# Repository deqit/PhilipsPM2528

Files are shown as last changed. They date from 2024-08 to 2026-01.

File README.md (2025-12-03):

# Reviving a Philips PM2528 Digital Multimeter
Picked up this vintage multimeter a while back. Half-functional, no manuals, and full of mystery. Perfect!

It’s built around an Intel 8035 microcontroller and packed with analog boards. There wasn’t a complete service manual anywhere, so I decided to dive in myself. This project's become a learning experience in hardware reverse engineering, firmware disassembly, and documentation.

Also see https://hackaday.io/project/203720-reviving-a-philips-pm2528-digital-multimeter

# The project
The goal of this project is fixing the multimeter. Well... maybe not really. In real life, the road towards that goal is much more interesting. And I'm documenting everything I found along the way.

In this repository you'll find:
- Original Philips-documentation (at least, what I could find, unfortunately in lo-res)
- Schematics (KiCad)
- PCB Layouts (KiCad)
- Schematic/PCB of a risercard, for testing the expansionboards
- Disassembled firmware, including annotations (Ghidra)
- A lot of documentation regarding relais-mapping, IO-expander-ports, etc.
- Detailed scope- and logic analyzer screenprints and capture-logs
- Deepdive: Explaination of how-everything-works
- etc.

Everything you find here is work-in-progress. It might be incomplete, and some parts may not be 100% accurate yet. If you spot something interesting or catch an error, feel free to drop me a message.

# The components
### Overview
- See [PM2528 Overview](/Deepdive/Overview/README.md "A very broad overview")
### Risercard
- See [PM2528 Risercard](/Deepdive/Risercard/README.md "A Risercard for testing the Expansionboards")
### ADC
- See [ADC Overview](/Deepdive/ADC/README.md "The ADC in more detail")
- See [ADC Control (Expansionboard N20)](/Deepdive/N20/README.md "ADC Control (Expansionboard N20)")
- See [ADC Analog (Expansionboard N21)](/Deepdive/N21/README.md "ADC Analog (Expansionboard N21)")

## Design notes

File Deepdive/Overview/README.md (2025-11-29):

# Introduction: A Multimeter with a Microprocessor Soul
Unlike modern instruments that rely on integrated chips, the PM2528 is built with a mixture of analog and logic-level circuits driven by an Intel 8035 microcontroller.

## Measurement Capabilities
The PM2528 supports a broad range of measurements, including:
- DC Voltage: 200 mV to 2000 V (max 1000 V continuous)
- AC Voltage (RMS): 200 mV to 2000 V (600 Vrms max)
- AC + DC Voltage: 200 mV to 2000 V (600 Vrms / 900 V peak max)
- DC Current: 2 µA to 2000 mA (2500 mA max)
- AC + DC Current: 2 µA to 2000 mA (2500 mA max)
- Resistance (2-wire): 200 Ω to 2000 MΩ
- Resistance (4-wire): 200 Ω to 2000 kΩ
- Temperature (via external PT100 sensor): –220 °C to +850 °C
- Optional features (not present in my unit) included:
- Peak voltage capture
- High-frequency AC voltage measurement

## System Overview: Four Functional Blocks
The PM2528 is organized into four primary functional blocks, each with clearly defined responsibilities.

### Analog Front-End

All measurements begin here. The analog section accepts voltage, current, resistance, or temperature inputs and scales them down to normalized voltage levels. These conditioned signals are then routed to the ADC for digitization. The analog input circuits also include protection circuitry and signal routing via relays, depending on the selected function and range.

### Analog-to-Digital Converter (ADC)
At the heart of the PM2528 is a dual-slope integrating ADC, a method widely used in precision multimeters of this era for its excellent noise rejection and accuracy. Unlike modern designs that use a single-chip ADC, the PM2528 implements this function across two full circuit boards.

### Control Logic and CPU

The PM2528 is controlled by an Intel 8035 microcontroller running at 6 MHz. It has 64 bytes of internal RAM and no on-chip ROM. The firmware lives in two external 2 KB EPROMs.

This microcontroller handles sequencing of measurement operations, display updates, user inputs, and communication over GPIB. Inputs to the CPU include front panel controls, GPIB interface, ADC conversion results and external trigger signals. Outputs are sent to a 7-segment display,  LEDs, Relay drivers and some external interfaces.

### Display and User Interface

The user interacts with the multimeter through a combination of buttons and a display: A 6-digit 7-segment LED array shows readings and units, LEDs (in fact: small lamps) indicate selected modes and functions, and function-keys allow measurement mode selection, ranging, and triggering.

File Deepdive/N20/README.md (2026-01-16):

# ADC Control (Expansionboard N20)
This expansion board forms the digital control interface between the microcontroller, the ADC Analog and the Counter.

Its functions include:
- Coordinating of the Ramp-Up and Ramp-Down phases
- Send the correct signals on time to the ADC Analog
- Trigger and reset the Counter
- Return measurement-ready signal to the CPU

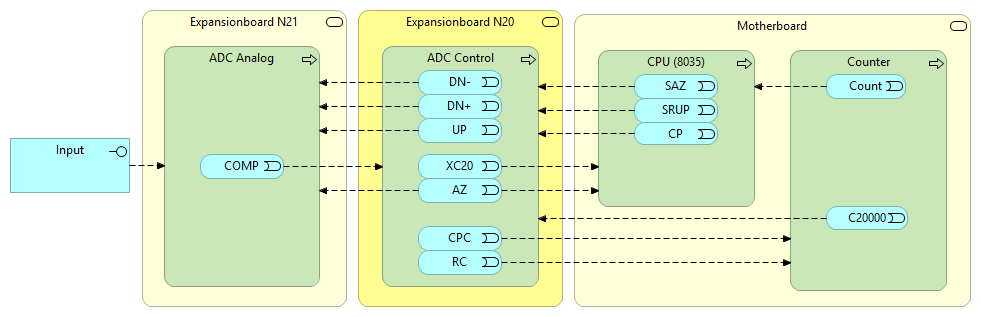
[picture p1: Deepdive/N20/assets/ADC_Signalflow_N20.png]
ADC Signalflow The signalflow between the components


### The signals
The signals used/shown on this page (see also the image above):
| Name | Description | I/O | Target | I/O Pin | Testpoint |
| - | - | :-: | - | -: | - |
| **SRUP** | Start Ramp-Up | I | CPU | 8 |
| **SAZ** | Set Auto Zero | I | CPU |9 |
| **CP** | Clock Pulses | I | CPU | 16 | TP2001 |
| **DN-** | RampDown phase, for -pol input signals | O | ADC Analog | 11 | TP2010 |
| **DN+** | RampDown phase, for +pol input signals | O | ADC Analog | 13 | TP2008 |
| **UP** | RampUp phase | O | ADC Analog| 14 | TP2007 | 
| **XC20** | Counter overflow (20.000 counts) @ RampDown | O | CPU | 15 |
| **AZ** | AutoZero active? | O | ADC Analog, CPU | 12 |
| **COMP** | COMPuting (integrator busy) | I | ADC Analog | 19 | TP2006 |
| **C20000** | Counter overflow (20.000 counts) | I | Counter | 5 |
| **CPC** | ClockPulses for Counter | O | Counter | 4 | TP2011 |
| **RC** | Reset Counter | O | Counter | 3 | TP2003 |

In the scope-screendumps, you'll also see these signals:
| Trace | Description | Measuring point |
| - | - | - |
| **yellow** | Input into ADC Integrator | N21.TP2105 |
| **purple** | ADC Integrator voltage | N21.TP2106 |

## A Measurement Cycle from the ADC Control's perspective

This section describes in detail how the N20 takes it role as the conductor of a measurement. The next image shows an overview, including the most important signals.

_Note: In the images below, the analogue traces are offset by +5V. That's because the digital 0V is -5V in reference to the analogue 0V and this is the way to show two signals in one screenshot (apart from Photoshop)._

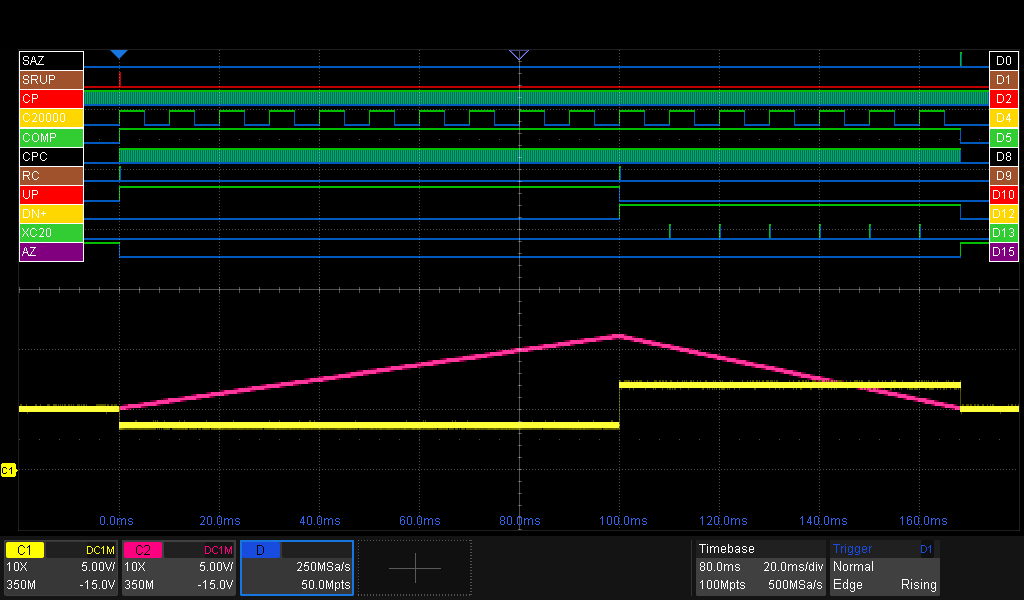
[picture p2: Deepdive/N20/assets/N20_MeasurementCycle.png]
N20 MeasurementCycle N20 - A complete measurement-cycle


#### @0ms: start of the cycle
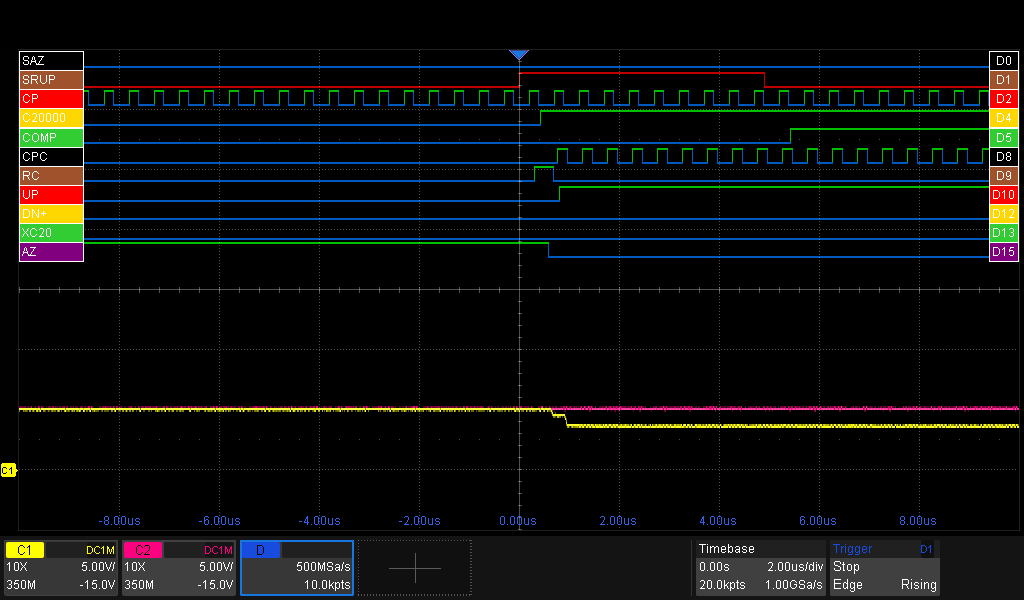
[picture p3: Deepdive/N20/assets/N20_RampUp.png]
N20 Start RampUp

- The measurement starts with a **SRUP**-pulse from the CPU
- The ADC Control resets the counter via **RC**. The counter resets and sets the **C20000** signal high (it's active low)
- The ADC Control opens the gate for the **CP** signals to passthrough to the Counter via the **CPC** signal.
- The ADC Control raises the **UP** signal, which instructs the ADC Analog to select the input-signal (reverse polarity) to be selected.
- The **AZ** signal is set low by the ADC-control, indicating there's no auto-zeroing going on.
- The ADC Analog signals the ADC Analog it's integrating, by setting the **COMP** signal.

#### @0-100ms: Ramp-up phase
See the first image in this section for reference.
- The Counter is busy counting, clocked by the **CPC** pulses.
- The Counter sends the **C20000** pulses to indicate it overflows. As the Ramp-Up phase is a fixed time phase, the ADC Control swallows them.
- Watch the clockpulses (**CP**) pulsing
- The ADC (**purple trace**) is integrating

#### @100ms: The fixed-time Ramp-Up phase is finished, starting the Ramp-Down phase
(please add 100ms to the time in the image)
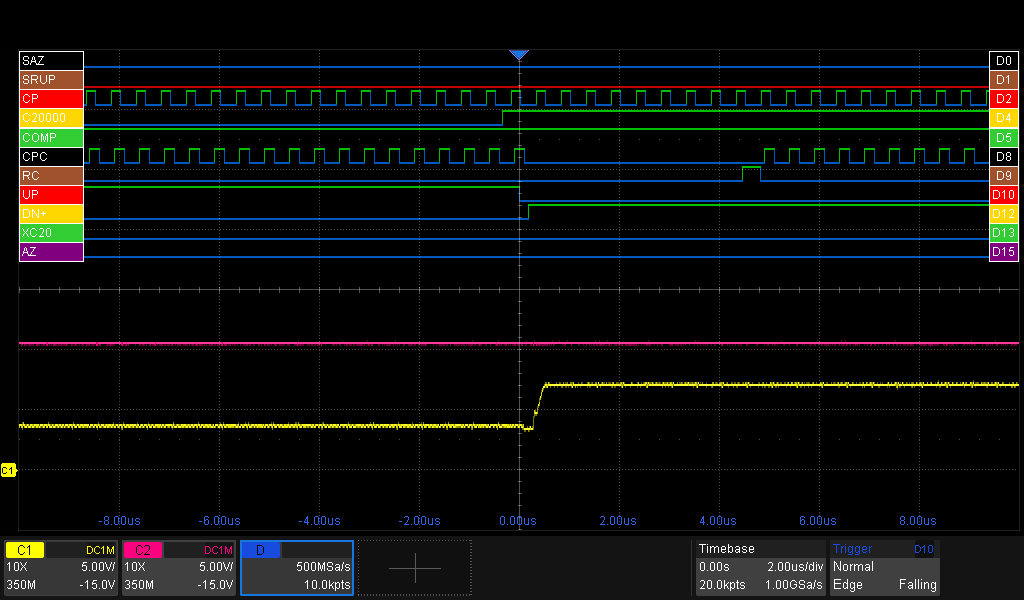
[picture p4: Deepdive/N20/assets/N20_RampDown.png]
N20 Start RampDown

- The ADC Control detected that the Ramp-Up phase has finished, as it has counted 200000 **CP** pulses.
- The ADC Control resets **UP** to signal the ADC Analog Ramp-Up is finished.
- The ADC Control sets **DN+** to indicate the ADC Analog we're now starting the Ramp-Down phase. The ADC Analog selects the positive reference-signal for de-integrating. For negative measure-signals, the ADC Analog would set **DN-** (not pictured).
- The ADC Control resets the counter via **RC**. The counter resets and sets/keeps the **C20000** signal high (it's active low).

#### @100-170ms: Ramp-down phase
See the first image in this section for reference.
- The ADC (**purple trace**) keeps draining
- For every counter-overflow (rising edge of **C20000**), the ADC Control sends a pulse to the CPU (**XC20**).

#### @170ms: Measurement ready
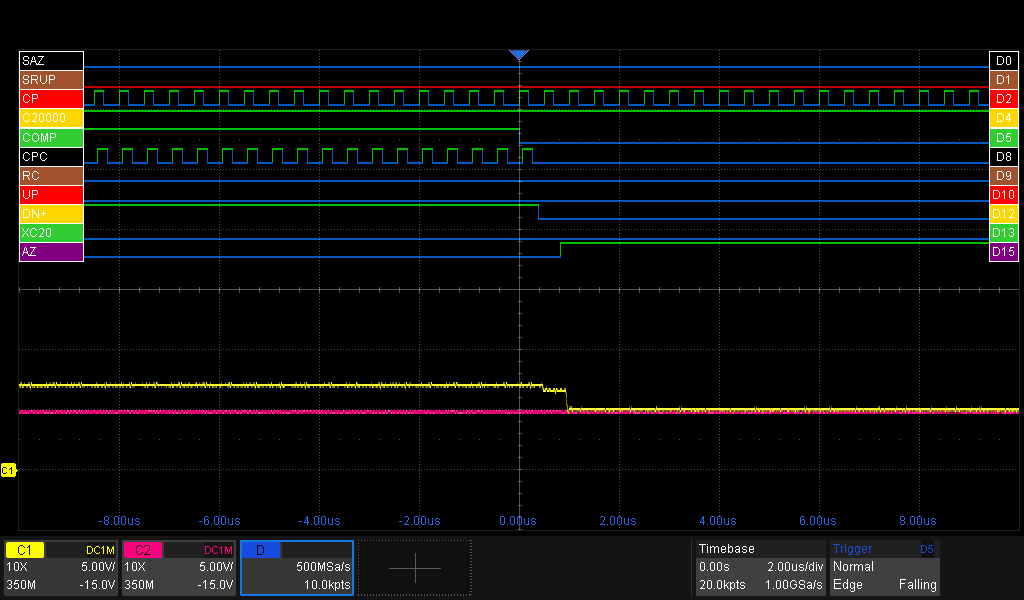
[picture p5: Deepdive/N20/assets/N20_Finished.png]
N20 Measurement Finished

- The ADC Analog detected that de-integrating is ready by resetting the **COMP** signal.
- The ADC Control then resets the **DN+** signal
- The ADC Control closes the gate for the **CPC** signal, stopping the Counter.
- The ADC Control asserts the **AZ** signal, signalling the CPU it's job has been done and signaling the ADC Analog to select 0V (**yellow trace**) as input to the ADC logic.

The CPU has enough info to calculate the voltage of the input-signal:
- the current value of the Counter
- Multiply the number of **XC20** pulses by 20.000
- Ramp-up phase = 200.000 counts (=fixed)
- Ramp-down phase = 135.100 counts (=6 x 20.000 from **XC20** + 15.100 from the Counter), which should be the same as the nummber of pulses **CPC**
- Reference-voltage = 2000mV
>Vin = (Tdown / Tup) × Vref = (135.100 / 200.000) * 2000mV = 1351mV

## Schematics
I copied and rearranged the schematics and PCB in KiCad, using the low‑res Philips docs as a reference. There might be a few small differences since I tweaked them to match my PM2528. You’ll find the KiCad files in other parts of this repo.
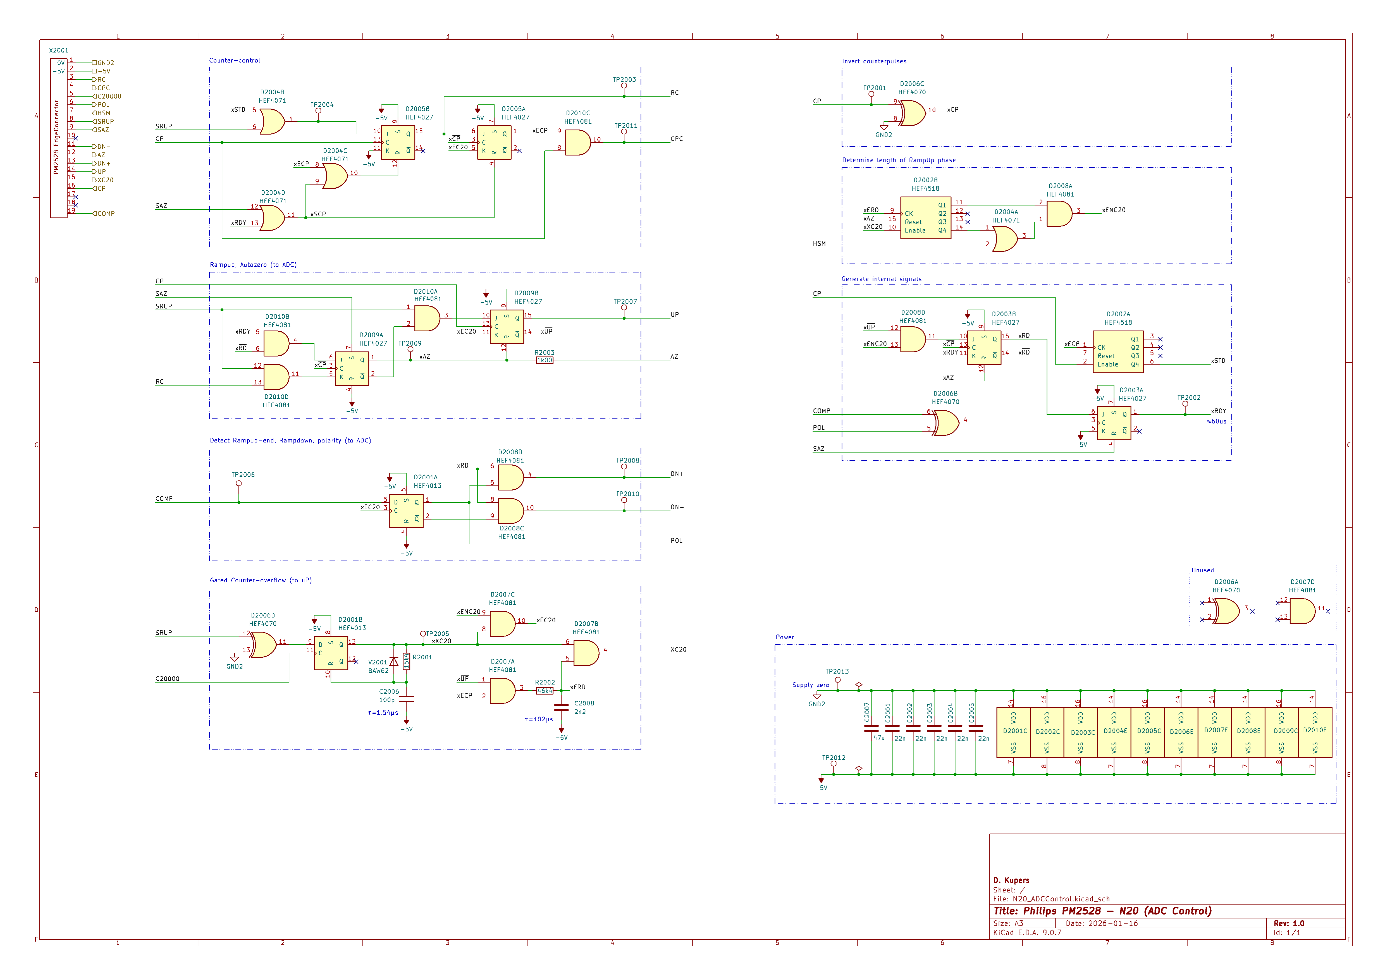
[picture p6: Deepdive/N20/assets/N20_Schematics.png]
N20 Schematics


The input- and output signals of this board are listed at the top of the page. The 'local' signals are listed in the next table.

#### Main signals
| Name |  Description | Testpoint |
| - | - | - |
| **x/UP** | Ramp**UP** active (active low)
| **xSTD** | **ST**art Ramp**D**own (level)| |
| **xERD** | **E**nable **R**amp**D**own | |
| **xRD** | **R**amp**D**own active | |
| **x/RD** | **R**amp**D**own active (active-low) | |
| **xAZ** | AutoZero active (same as **AZ**) | TP2009 |
| **xRDY** | **R**ea**DY**: RampUp and RampDown finished (pulse ≈60us)| TP2002 |

#### Clock and Counter pulses
| Name |  Description | Testpoint |
| - | - | - |
| **x/CP** | **C**lock**P**ulses (inverted)  | |
| **xECP** | **E**nable **C**lock**P**ulses (gate for pulses to counter)| |
| **xSCP** |  **S**top **C**ounter**P**ulses | |
| **xXC20** | Pulse (≈1.4us) for every Counter overflow  | TP2005 |
| **xENC20** | **EN**d **C20000**?  | |
| **xEC20** | **E**nable **C20000** gate, Pulse (≈1.4us) when ending RampUp | |
|
### Section: Counter-control (to Counter)
This section generates the **CPC** (ClockPulses for Counter) and **RC** (Reset Counter) signals.

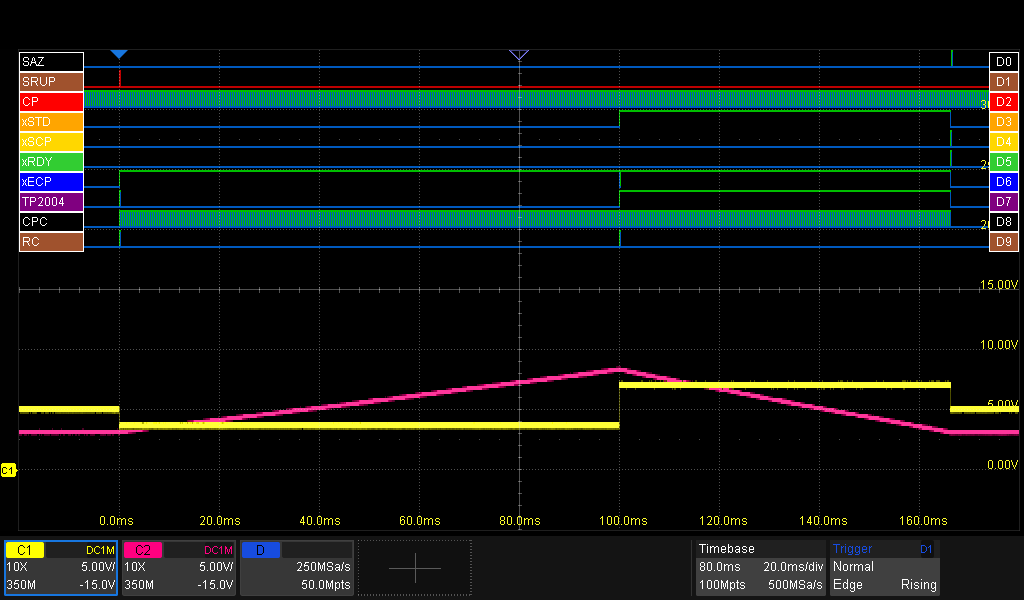
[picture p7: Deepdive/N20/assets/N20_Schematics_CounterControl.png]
N20 CounterControl


### Section: RampUp, AutoZero (to ADC)
This section generates the **UP** (RampUp active) and **AZ** (AutoZero) signals.

The **UP** (RampUp) signal is active during the RampUp phase.
The **AZ** (AutoZero) signal is active when the measurement is not active, eg, when not in the RampUp or RampDown phase.

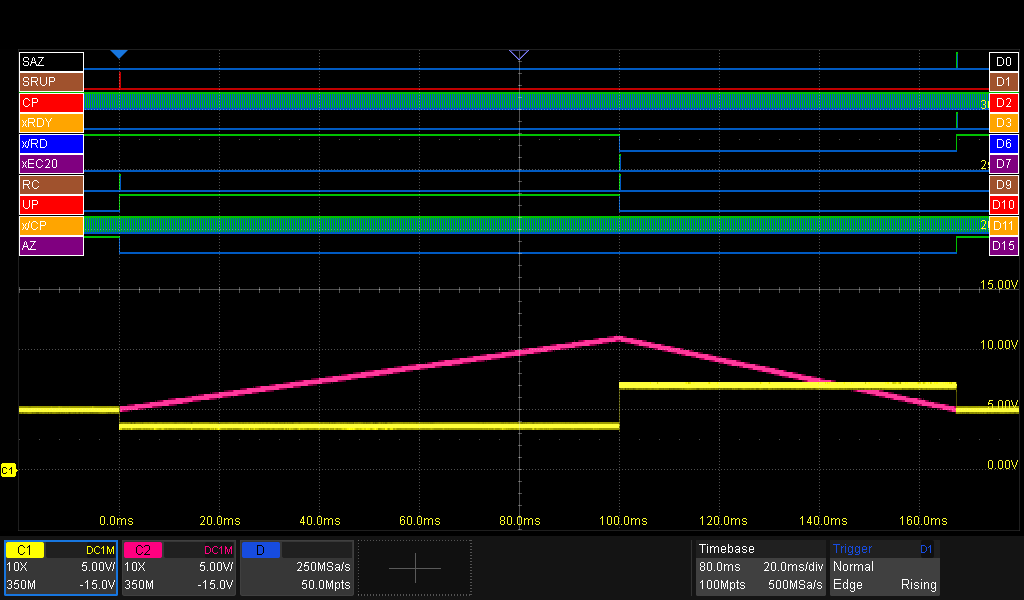
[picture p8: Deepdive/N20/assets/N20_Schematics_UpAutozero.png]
N20 UpAutozero


### Section: Polarity and RampDown (to ADC)
This section generates the **POL** (Polarity), **DN+** and **DN-** (DownRamp) signals.

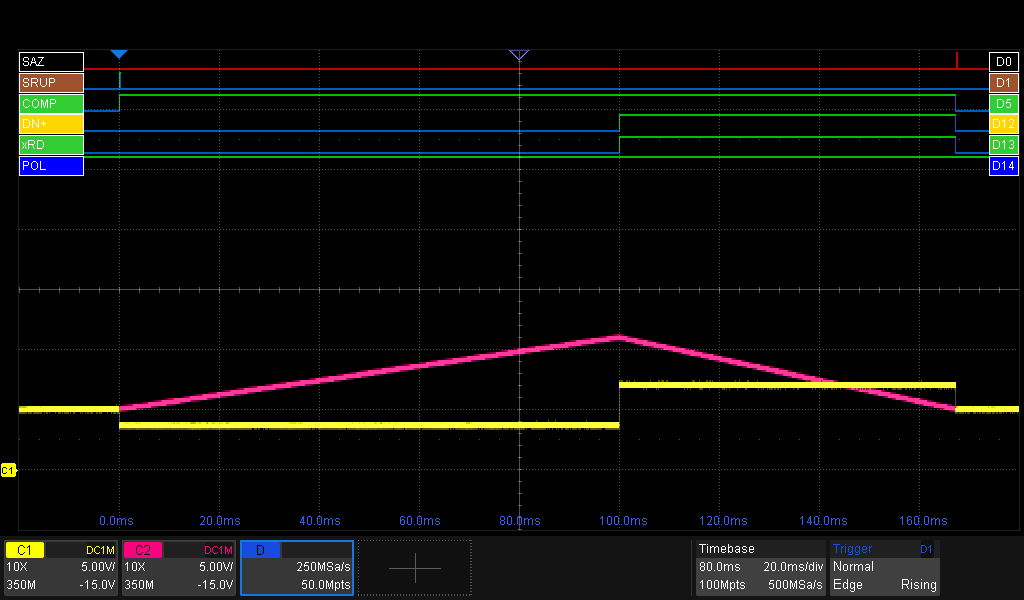
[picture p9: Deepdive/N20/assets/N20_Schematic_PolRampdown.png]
N20 Polarity, Rampdown


### Section: Gated Counter-overflow (to uP)
This section creates the **XC20** signal for the CPU. This is in fact a gated Counter-Overflow signal. The gate is closed in the RampUp phase, and opened in the RampDown phase.

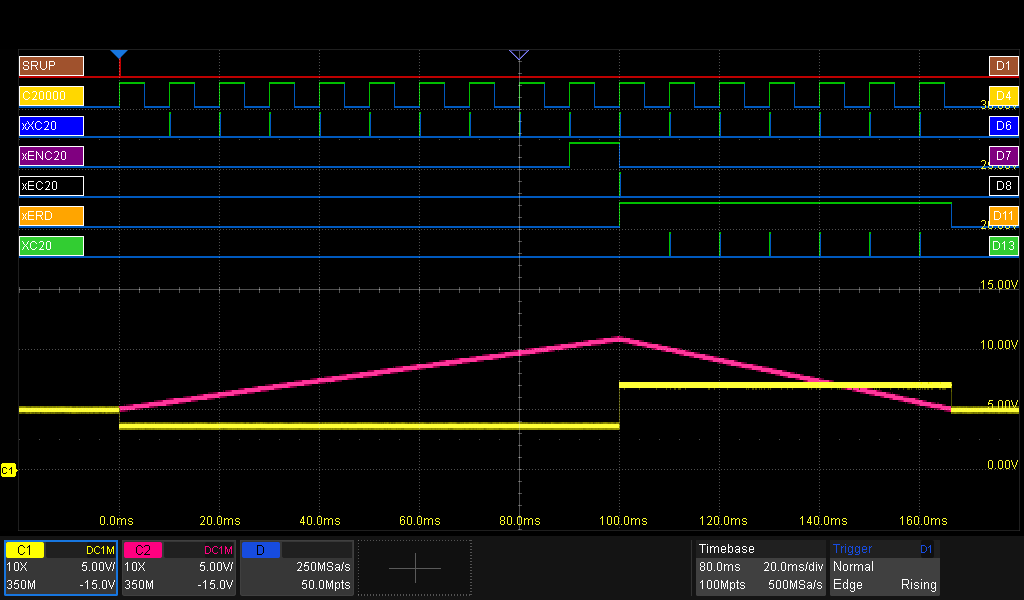
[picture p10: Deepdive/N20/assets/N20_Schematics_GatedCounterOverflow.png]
N20 Gated Counter Overflow


### Section: Invert counterpulses

### Section: Determine length of RampUp phase
This section generates the internal **xENC20** signal. In HSM-mode it sets **xENC20** after one Counter-overflow (10ms), otherwise it sets **xENC20** after 9 Counter-overflows (eg, 100ms). The RampUp-phase ends on the falling edge of **xENC20**, see the 'Generate internal signals' section.

### Section: Determine start and end of RampDown

## PCB
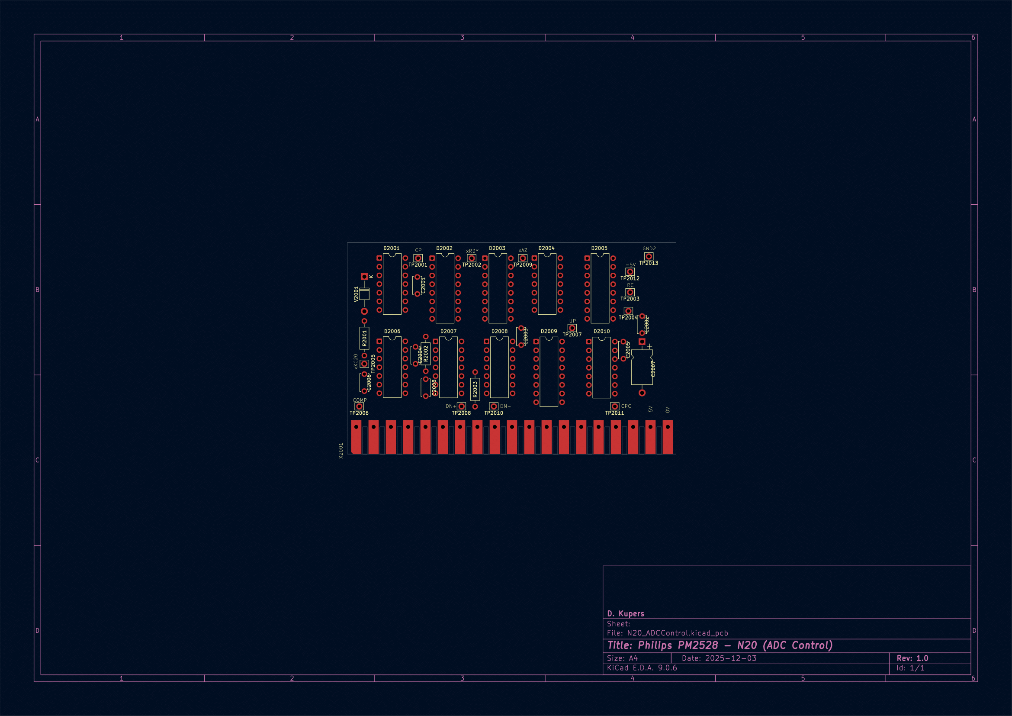
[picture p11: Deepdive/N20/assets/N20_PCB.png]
N20 PCB

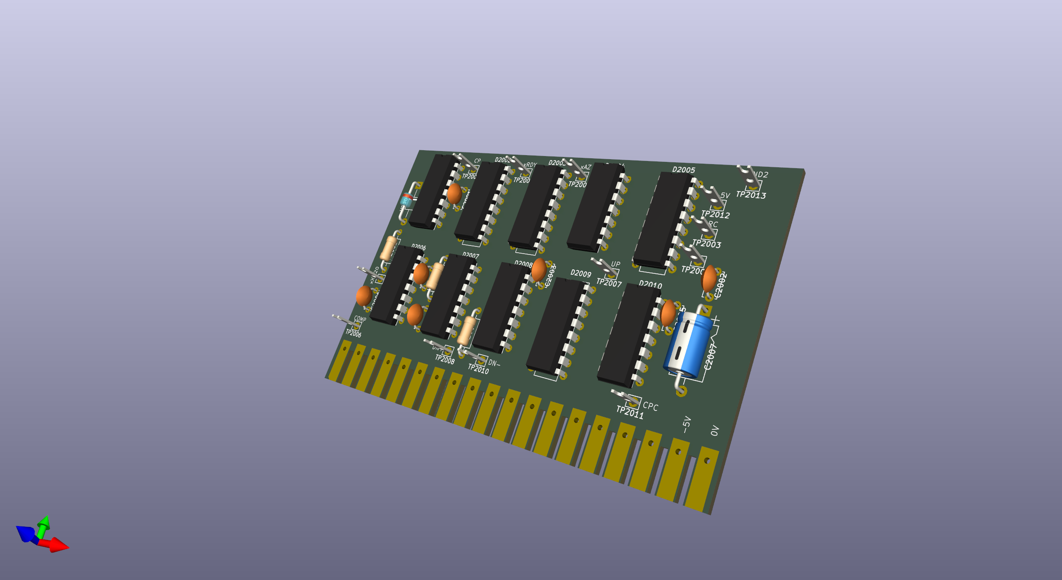
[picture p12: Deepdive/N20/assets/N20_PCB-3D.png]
N21 PCB 3D N20 PCB 3D


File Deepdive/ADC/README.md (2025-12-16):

# The ADC: Dual-Slope Precision from Discrete Parts
At the heart of the PM2528 is a **dual-slope integrating ADC**, a method widely used in precision multimeters of this era for its excellent noise rejection and accuracy. Unlike modern designs that use a single-chip ADC, the PM2528 implements most of this function across multiple components on multiple modules.

## The theory
An integrating ADC is a type of analog-to-digital converter that converts an unknown input voltage into a digital representation through the use of an integrator. In this implementation this is performed by a dual-slope converter. In short, it measures voltage by timing how long it takes to discharge a capacitor. It works in two phases: **ramp-up** and **ramp-down**.

#### Ramp-Up (Integration)
First, the unknown input voltage charges an integrator (an opamp with a capacitor in the feedback loop) for a fixed period. The output voltage of this integrator ramps up linearly.

#### Ramp-Down (De-integration)
Then, a known precise reference voltage of opposite polarity is applied, discharging the capacitor. The time required to bring the integrator’s output back to zero is measured. This gives the relationship:

>Vin = (Tdown / Tup) × Vref

Since the integration time (**Tup**) and **Vref** are fixed and stable, measuring **Tdown** gives an accurate representation of the input voltage.

## In Practice: how does the PM2528 do this?

Performing a measurement requires four components of the machine: The CPU, module ADC Control, module ADC Analog and a 20.000-count Counter. For understanding how everything works together, the role of every component must be clear.

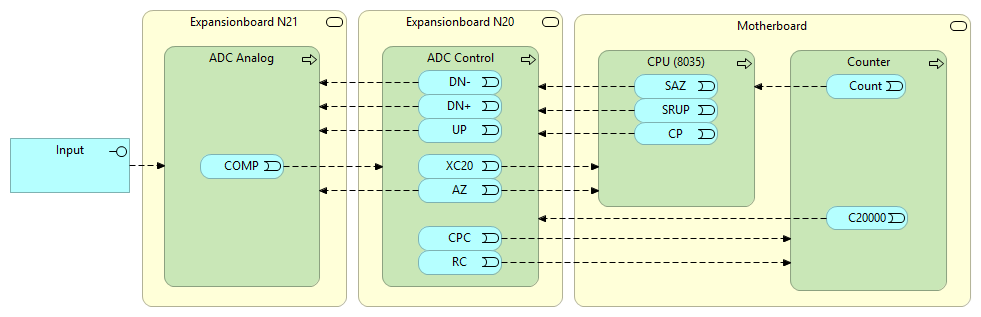
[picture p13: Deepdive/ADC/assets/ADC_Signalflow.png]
ADC Signalflow The signalflow between the components


#### Input
This is the voltage to be measured. For this section, assume this voltage has been scaled down to normalized voltage levels, ready for processing.

#### The CPU
The CPU is the director of a measurement. It is in control of the clocksignal, gives a start-signal to the ADC-Control and reads the counter, among other things.

#### ADC Control (Expansionboard N20)
This board forms the digital control interface between the microcontroller, the ADC Analog and the Counter. The ADC Control is normaly 'idle', unless commanded by the CPU to perform a measurement.

#### ADC Analog (Expansionboard N21)
Here lies the analog heart of the converter. This board provides a reference voltage for the de-integration phase and contains all analog logic for the dual slope integration process.

#### The Counter
The 20.000 counts Counter just counts pulses, provided by the ADC Control. In return, it provides the actual count-value to the CPU.

### The signals
The signals used/shown on this page (see also the image above):
| Signal | Use | Source | Target |
| - | - | - | - |
| **SRUP** | Start Ramp-Up | CPU | ADC Control |
| **SAZ** | Set Auto Zero | CPU | ADC Analog |
| **CP** | Clock Pulses | CPU | ADC Analog |
| **XC20** | Counter overflow (20.000 counts) @ RampDown | ADC Control | CPU |
| **Count** | Current value | Counter | CPU |
| **yellow trace** | Input to ADC Integrator | Signal conditioning | ADC Analog |
| **purple trace** | ADC Integrator | ADC Analog | ADC Analog |

## A Measurement Cycle from the CPU's perspective
Let’s walk through a full measurement cycle, based on scope captures and logic traces.

_Note: In the images below, the analogue traces are offset by +5V. That's because the digital 0V is -5V in reference to the analogue 0V and this is the way to show two signals in one screenshot (apart from Photoshop)._

The screencapture below shows a full ADC-cycle. The input voltage is about 1351mV DC, the meter is in 2V range. The digital signals (top of the screen) are the signals as seen from the CPU's point of view.

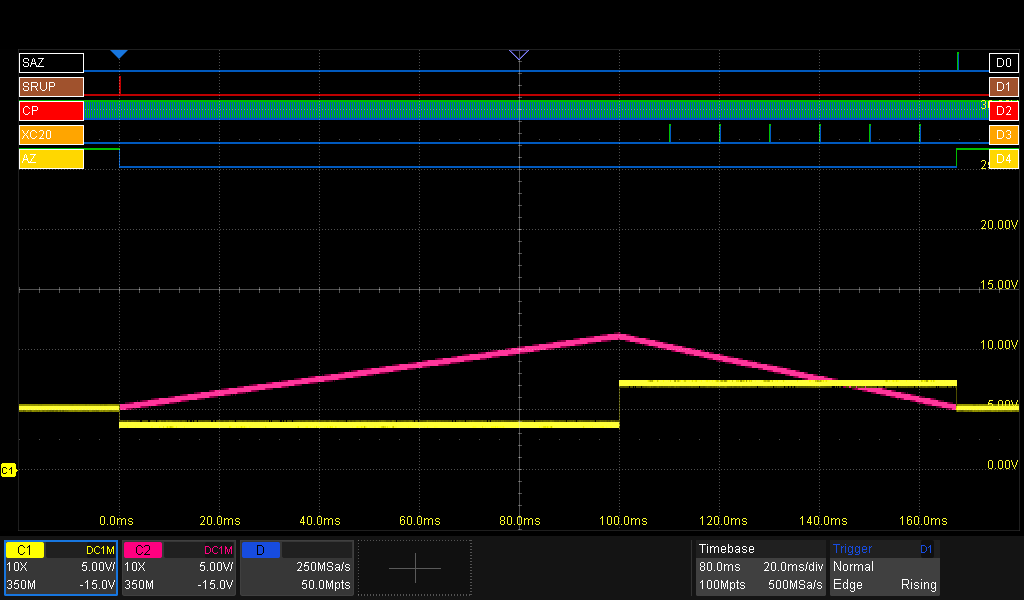
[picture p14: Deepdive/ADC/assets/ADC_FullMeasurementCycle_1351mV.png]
ADC Full MeasurementCycle A complete measurement-cycle


#### @0ms: start of the cycle
- The CPU sets the **SRUP** signal. This initiates the 'Ramp-Up' phase.
- The input-signal (**yellow trace**, reverse polarity, why?) is offered to the ADC
- The **AZ** signal is set low by the ADC-control, indicating there's no auto-zeroing going on.

#### @0-100ms: Ramp-up phase
- The ADC (**purple trace**) is integrating
- As this is a fixed time phase, under control of the ADC Control, the CPU does not receive any signal. Note there are no timer-overflow (**XC20**) pulses.
- Watch the clockpulses (**CP**) pulsing

#### @100ms: The fixed-time Ramp-Up phase is finished
- The measurement-signal (**yellow trace**) is set to the reference voltage (opposite polarity of the input voltage)

#### @100-170ms: Ramp-down phase
- The ADC (**purple trace**) keeps draining due to the reference voltage
- Every 20.000 pulses of the clock, the CPU receives the Counter Overflow pulse (**XC20**). The CPU counts the number of these pulses.

#### @170ms: Measurement ready
- The ADC (**purple trace**) has crossed zero, meaning we're ready. The CPU knows this, because the AutoZero signal (**AZ**) has been set by the ADC Control.
- The CPU asserts **SAZ** telling the ADC Control to auto-zero.
- The input signal to the ADC (**yellow trace**) is reset to 0V.

#### Displaying the measured value
The CPU now calculates the measured value, using
- the current value of the Counter
- the number of **XC20** pulses
- Ramp-up phase = 200.000 counts (=fixed)
- Ramp-down phase = 135.100 counts (=6 x 20.000 from **XC20** + 15.100 from the Counter)
- Reference-voltage = 2000mV
>Vin = (Tdown / Tup) × Vref = (135.100 / 200.000) * 2000mV = 1351mV

### A second example
When you offer a small voltage (but in the same measurement range), the Ramp-down phase will be shorter as the ADC won't be charged up as much in the Ramp-Up phase. See the image below for a measurement of 500mV.

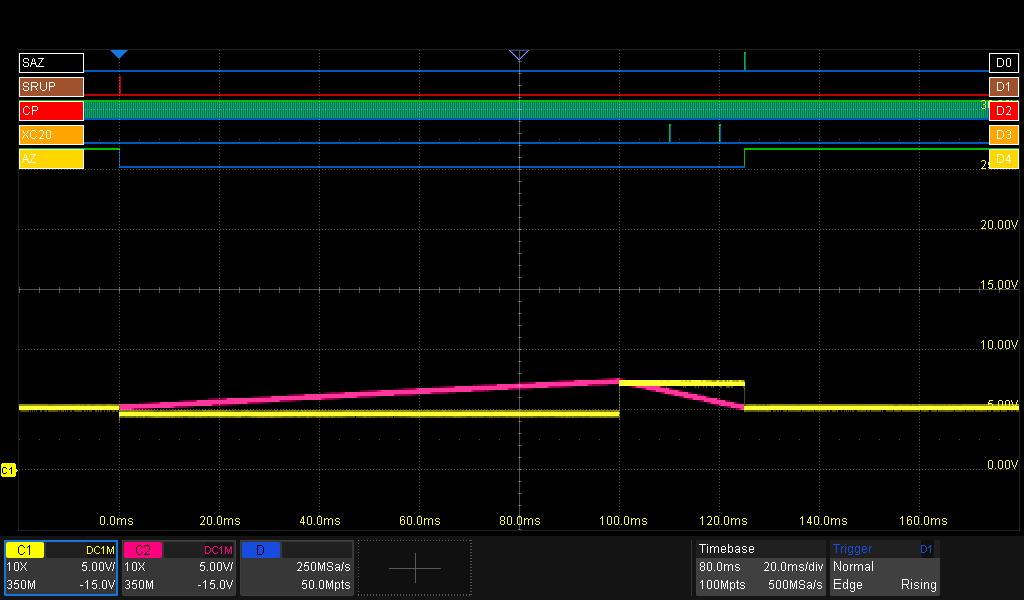
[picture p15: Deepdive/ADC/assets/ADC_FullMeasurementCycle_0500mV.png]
ADC Full MeasurementCycle A complete measurement-cycle


### High-speed mode
In high-speed mode (can only be enabled via the GPIB-interface) the ramp-up phase is reduced from 200.000 counts to 20.000 counts, eg, 10 times faster.

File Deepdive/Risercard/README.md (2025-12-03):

# Risercard
Testing the expansion boards isn’t exactly convenient. They’re packed in tight, so probing components is a hassle. Pulling a board out gives you access, but wiring up all the signals is basically impossible. The fix was straightforward: I built a simple riser card

It’s got a few handy features:
- Works in any expansion slot, except the ones reserved for the Galvanic Isolation board (N30) and the IEEE488 board (N32).
- Power LED to show there’s juice (0V/‑5V) coming from the PM2528 into the riser.
- Another power LED to confirm that same juice is actually reaching the “rised” board.
- Jumpers to break all 19 signals going to and from the board.
- Pin headers so you can tap or inject those 19 signals.
- Test pins for the same job, if you prefer a quick probe.

## Schematics and PCB
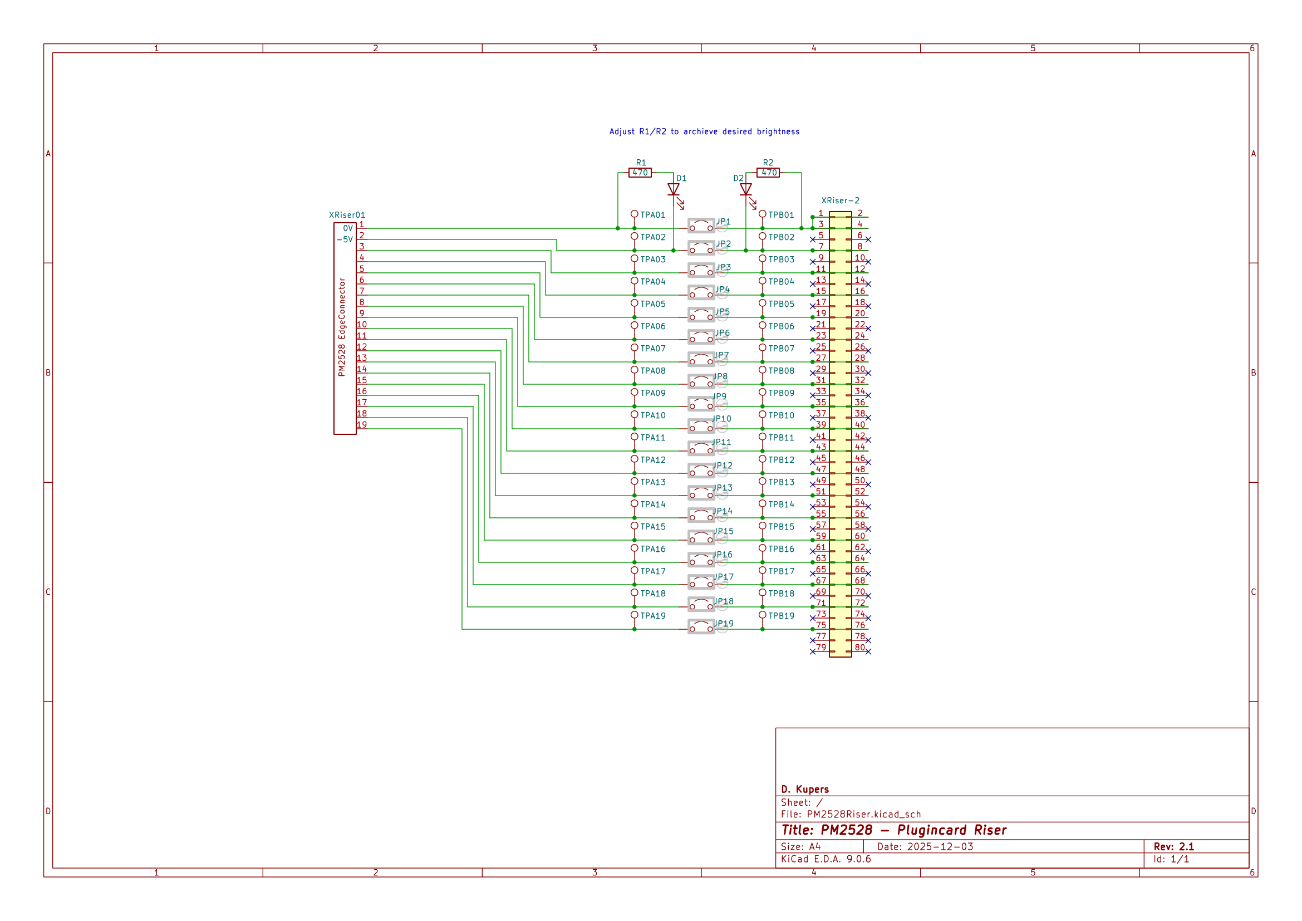
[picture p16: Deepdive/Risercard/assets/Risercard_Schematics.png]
Risercard Schematics

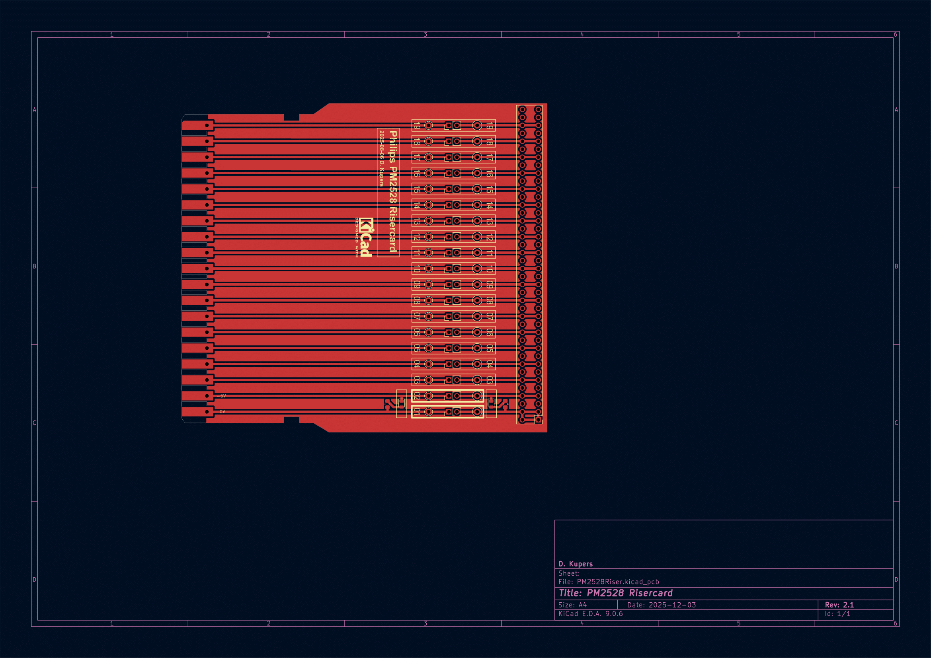
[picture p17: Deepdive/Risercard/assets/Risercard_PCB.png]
Risercard PCB

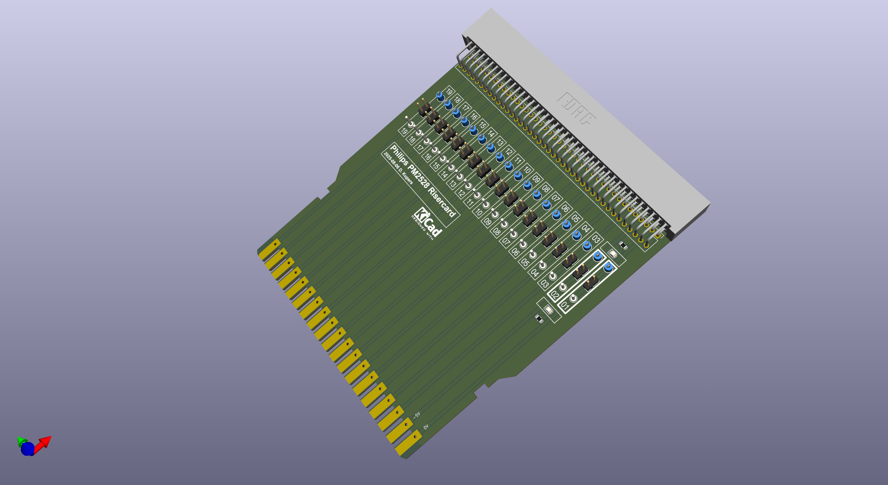
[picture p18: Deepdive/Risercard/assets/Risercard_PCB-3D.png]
Risercard PCB 3D

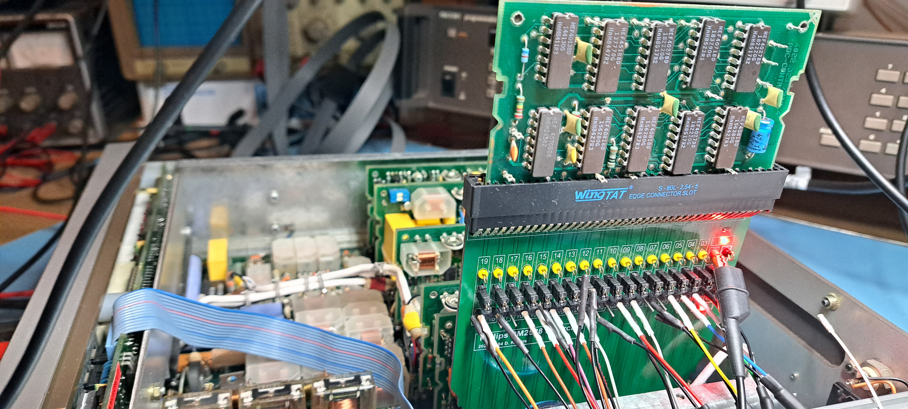
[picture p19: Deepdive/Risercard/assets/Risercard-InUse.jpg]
Risercard In use Risercard In real life


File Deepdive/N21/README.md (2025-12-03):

# ADC Analog (Expansionboard N21)
This expansion board realizes the actual Dual Slope Integrator.

Its functions include:
- Providing a reference voltage
- Realizing the actual Dual Slope Integrator
- Selecting the right signal to be fed into the integrator

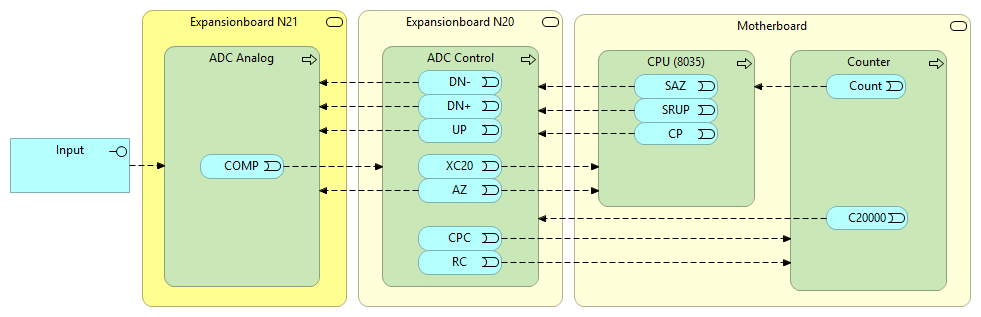
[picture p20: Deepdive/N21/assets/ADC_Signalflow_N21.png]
ADC Signalflow The signalflow between the components


The signals used/shown on this page (see also the image above):
| Signal | Use | Source | Target |
| - | - | - | - |
| **AZ** | AutoZero active? | ADC Control | ADC Analog, CPU |
| **DN-** | RampDown phase, for -pol input signals | ADC Control | ADC Analog |
| **DN+** | RampDown phase, for +pol input signals | ADC Control | ADC Analog |
| **UP** | RampUp phase | ADC Control | ADC Analog|
| **COMP** | COMPuting (integrator busy) | ADC Analog | ADC Control |
| **yellow trace** | Input to ADC Integrator | Signal conditioning | ADC Analog |
| **purple trace** | ADC Integrator | ADC Analog | ADC Analog |

## A Measurement Cycle from the ADC Analog's perspective

This section describes in detail how the N20 takes it role as the conductor of a measurement. The next image shows an overview, including the most important signals.

_Note: In the images below, the analogue traces are offset by +5V. That's because the digital 0V is -5V in reference to the analogue 0V and this is the way to show two signals in one screenshot (apart from Photoshop)._

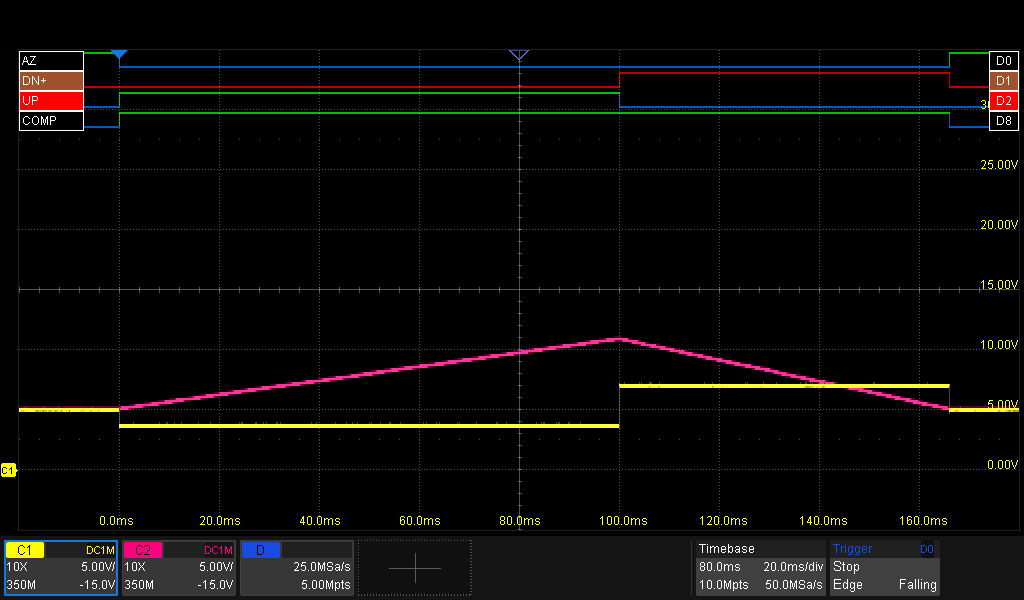
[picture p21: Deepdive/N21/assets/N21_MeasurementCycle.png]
N21 MeasurementCycle N21 - A complete measurement-cycle


#### @0ms: start of the cycle
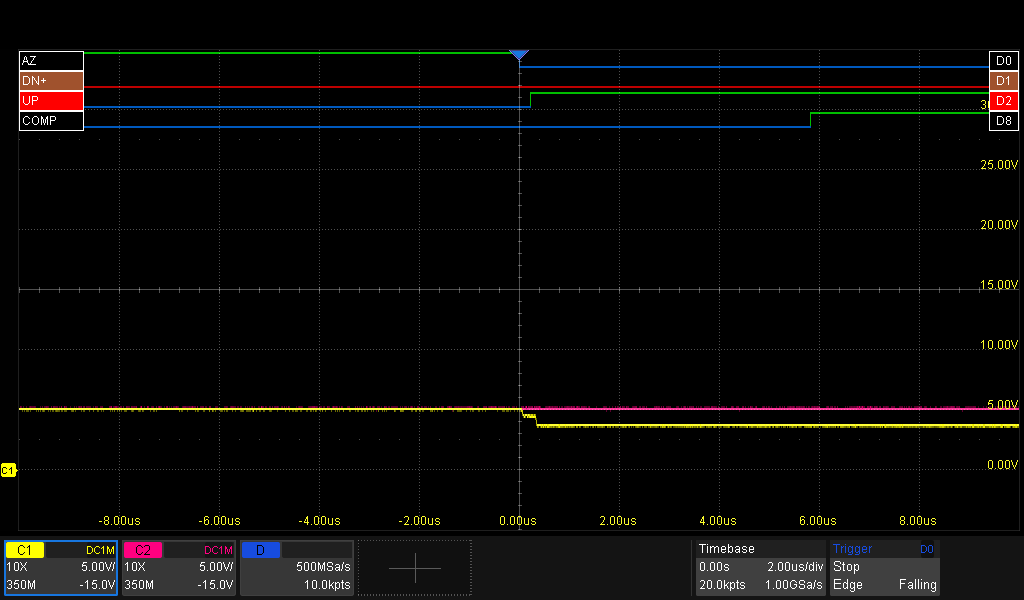
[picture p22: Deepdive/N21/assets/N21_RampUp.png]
N21 Start RampUp

- The measurement starts with the **AZ**-signal from the ADC Control. This 'releases' the zero-clamping and offset-correcting circuits.
- After this, the ADC Control signals the ADC Analog to start the RampUp-phase by setting the **UP** signal.
- The integrator starts integrating (**purple trace**)

#### @0-100ms: Ramp-up phase
See the first image in this section for reference.
- The ADC selects the input-signal to be fed into the integrator (**yellow trace**)
- The integrator keeps integrating (**purple trace**)
- The integrator on the ADC Analog sees a non-zero signal and raises **COMP**.

#### @100ms: The fixed-time Ramp-Up phase is finished
(please add 100ms to the time in the image)
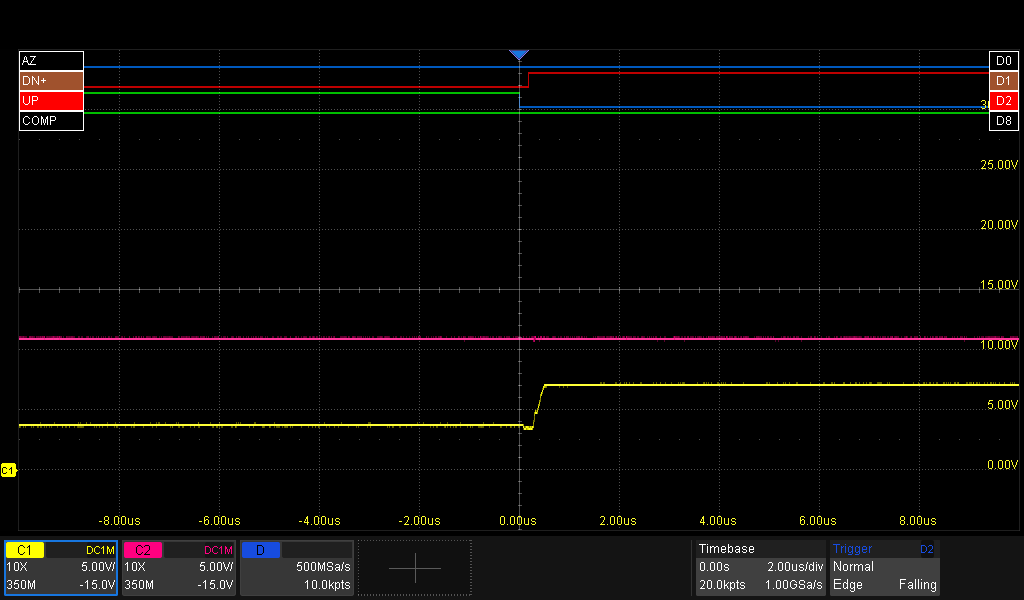
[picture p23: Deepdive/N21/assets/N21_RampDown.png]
N21 Start RampDown

- The ADC Control releases the **UP** signal as the fixed time has passed.
- The ADC Analog sets the **DN+** signal to tell the ADC Analog it can start the Ramp-Down phase.
- As a response, the ADC Analog now selects the correct Reference Signal (**yellow trace**), in this case +2V.
- The integrator now start to drain the capacitor (**purple trace**).

#### @100-170ms: Ramp-down phase
See the first image in this section for reference.
- The integration-capacitor (**purple trace**) keeps draining

#### @170ms: Measurement ready
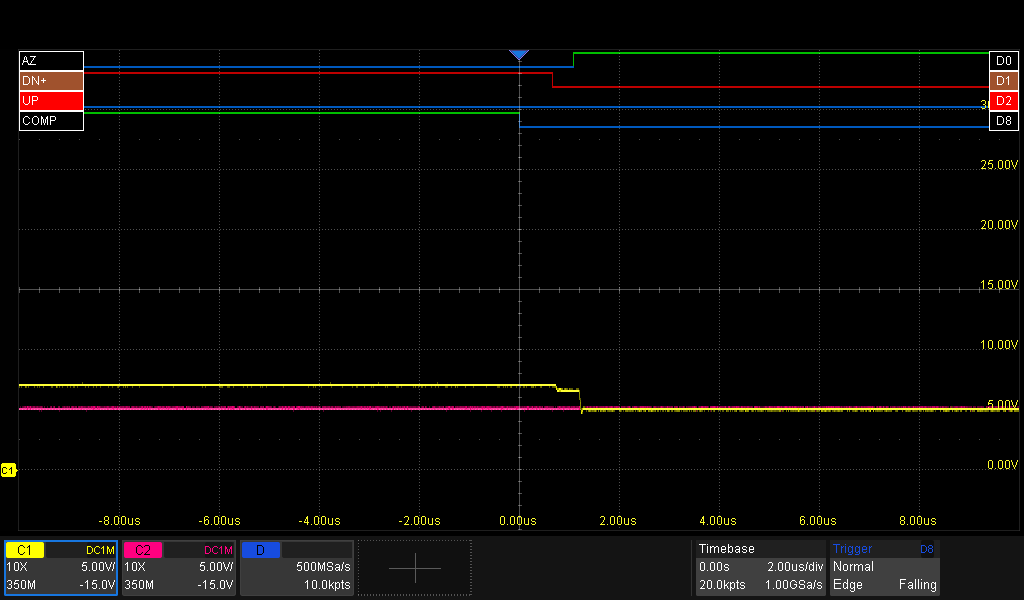
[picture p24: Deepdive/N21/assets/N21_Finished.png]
N21 Measurement Finished

- The ADC Analog detects de-integrating is ready (the capacitor-voltage crosses zero) and resets the **COMP** signal.
- The ADC Control release the **DN++** signal, telling the ADC Control to stop the Ramp-down phase.
- The ADC Analog deselects the reference-signal from the integrator-input
- The ADC Control sets the **AZ** signal, the ADC Analog initiates the Auto-zero circuitery.

## Schematics and PCB
I copied and redrew the schematics and PCB in KiCad, using the low‑res Philips docs as a reference. There might be a few small differences since I tweaked them to match my PM2528. You’ll find the KiCad files in other parts of this repo.
N21 Schematics
N21 PCB
N21 PCB 3D

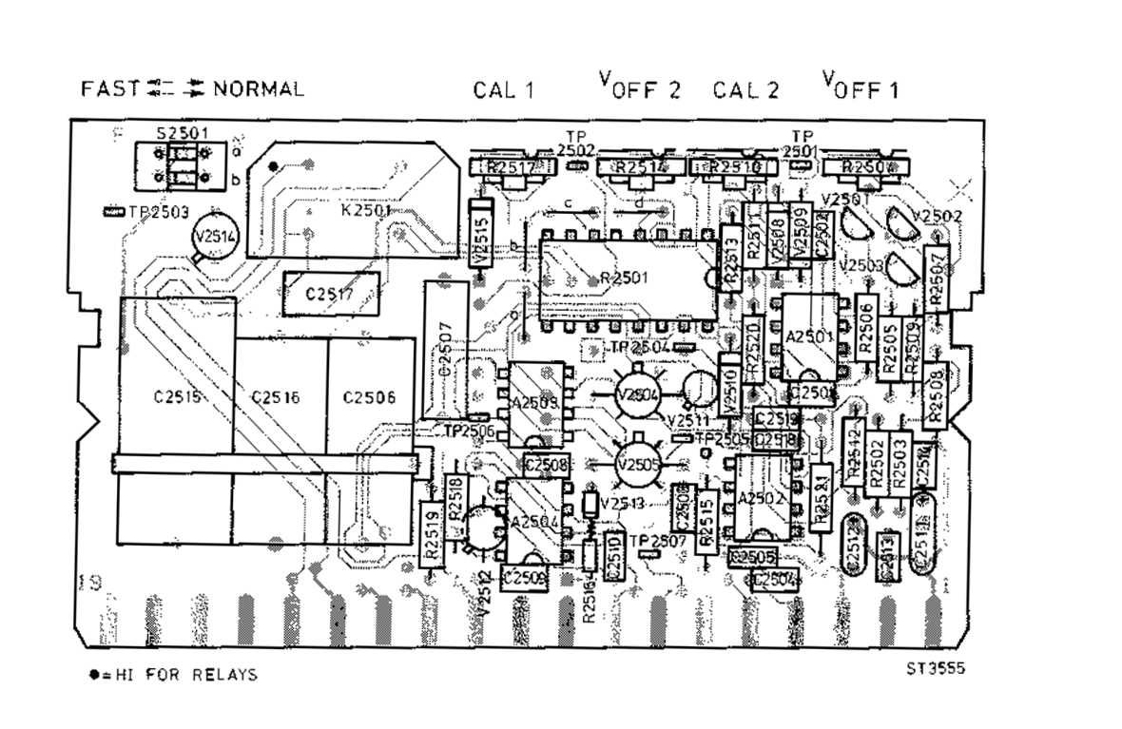
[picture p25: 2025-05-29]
Schematics/Expensionboards/N25_RMSConverter/pcb.png

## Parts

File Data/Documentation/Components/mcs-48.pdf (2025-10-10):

# Grokking the MCS-48 System

## Version 3.5.2, September 2021

# Preface

This document came into existence as the effort to collect and maintain the information about the MCS-48 microcontroller family I have access to.
The collected paperwork consists of several copied sheets from Intel databooks that age over time, slowly fading away. In addition, the resources in electronic form for this microcontroller

## family were never complete nor exhaustive. As nowadays, not everyone is lucky enough to have access to these old, big databooks, this document intends to transport all the

knowledge necessary to work with these grandfathers.
Please note that this document does not claim correctness of the contained information. Nor should you ever use it as the only reference for building critical applications.

## Five separate sources contributed to this document: - Two different versions of the "MCS-48TM Microcomputer User's Manual" The chapter "The Expanded MCS-48TM System" was found in a 1978's copy of the User's Manual while the chapter "The Single Component MCS® -48 System" was probably part of a

later revision of the User's Manual.

## - Das 8039, 8048, 8748 Brevier H. Weidner, Braunschweig The first part of this booklet is a translation of "The Single Component MCS ® -48 System" into the German language while the second part gives a very detailed description of the

family's instruction set.

## - HMOS Single-Component 8-Bit Microcomputer Intel Corporation, August 1982, Order Number 210677-001

A 9-page datasheet with an excellent instruction set table.

- Some scanned pages with details about the 8243, apparently from an old Intel databook.

## - A set of copied pages containing the 8245 product specification. The second page of the

character set is missing.

## October 2006

## Arnim Läuger

mailto: arnim.laeuger <at> gmx.net

The following are trademarks of Intel Corporation and its affiliates and may be used only to identify Intel products: BXP, CREDIT, i, ICE, ICS, im, insite, Intel, INTEL, Intelevision, Intellec, iSBC, iSBX, Library Manager, MCS, MAIN MULTIMODULE, Megachassis, Micromap, MULTIBUS, Plug-A-Bubble, PROMPT, Promware, RMX, UPI, µScope, System 2000, Micromainframe, and the combination of MCS, ICE, iSBC, iRMX or iCS and a numerical suffix.

# HMOS Single-Component 8-Bit Microcomputer

- High Performance HMOS | • Reduced Power Consumption
- Interval Timer/Event Counter | • Compatible with 8080/8085 Peripherals
- Two Single Level Interrupts | • Easily Expandable Memory and I/O
- Single 5-Volt Supply | • Up to 1.36 μs Instruction Cycle
- Over 96 Instructions; 90% Single Byte | All Instructions 1 or 2 Cycles

The Intel MCS®

-48 family are totally self-sufficient, 8-bit parallel computers fabricated on single silicon chips using Intel's advanced N-channel silicon gate HMOS process.
The family contains 27 I/O lines, an 8-bit timer/counter and on-board oscillator/clock circuits. For systems that require extra capability, the family can be expanded using MCS®
| -80/MCS® -85 peripherals.
To minimize development problems and provide maximum flexibility, a logically and functionally pin-compatible version of the ROM devices with UV-erasable user-programmable EPROM program memory is available with minor differences.
These microcomputers are designed to be efficient controllers as well as arithmetic processors. They have extensive bit handling capability as well as facilities for both binary and BCD arithmetic. Efficient use of program memory results from an instruction set consisting mostly of single byte instructions and no instructions over 2 bytes in length.
Device | Internal Memory | RAM Standby
8050AH | 4K x 8 ROM | 256 x 8 RAM | yes
8049H | 2K x 8 ROM | 128 x 8 RAM | yes
8048H | 1K x 8 ROM | 64 x 8 RAM | yes
8040AHL | none | 256 x 8 RAM | yes
8039HL | none | 128 x 8 RAM | yes
8035HL | none | 64 x 8 RAM | yes
8749H | 2K x 8 EPROM | 128 x 8 RAM | yes
8748H | 1K x 8 EPROM | 64 x 8 RAM | yes

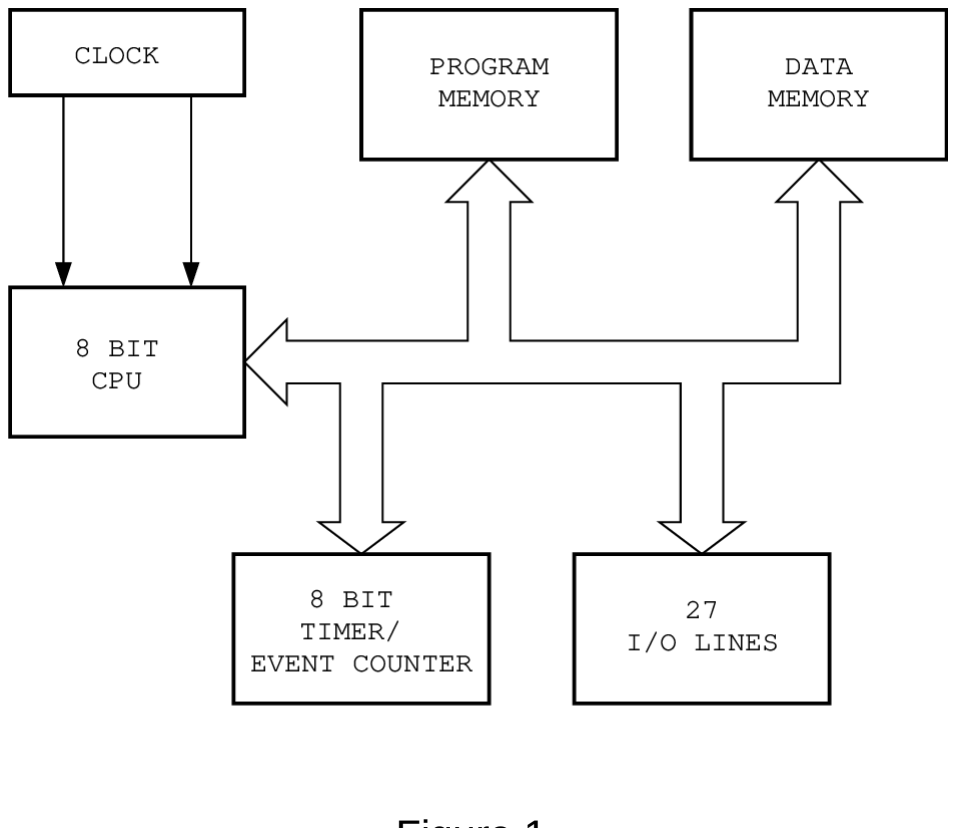
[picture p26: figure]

Figure 1.
Block Diagram

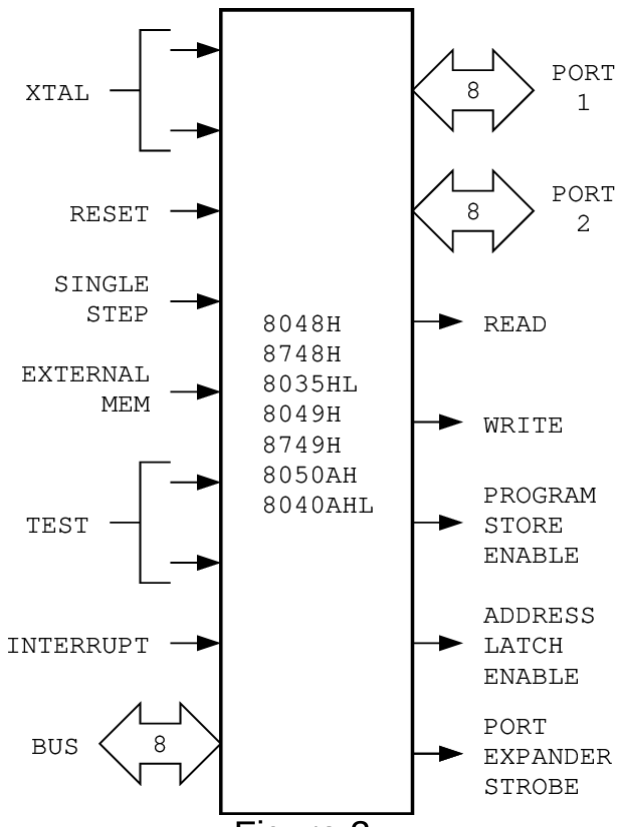
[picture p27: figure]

Figure 2.
Logic Symbol

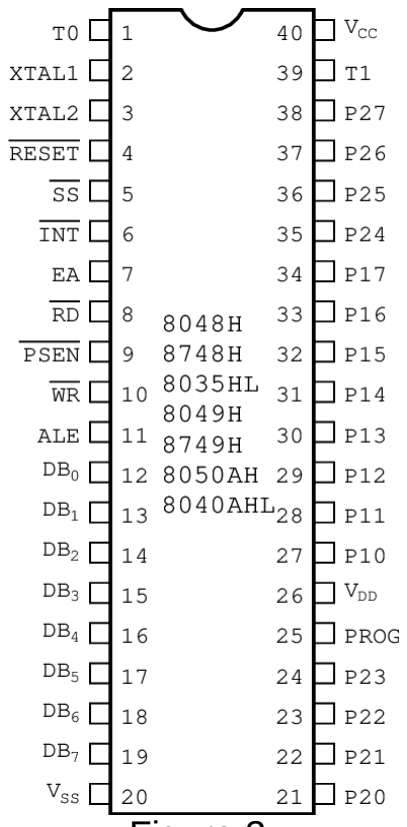
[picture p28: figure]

Figure 3.
Pin Configuration

# THE SINGLE COMPONENT MCS® -48 SYSTEM

## 1.0 INTRODUCTION

Sections 2 through 5 describe in detail the functional characteristics of the 8748H and 8749H EPROM,
8048AH/8049AH/8050AH | ROM | and | 8035AHL/
8039AHL/8040AHL CPU single component microcomputers. Unless otherwise noted, details within these sections apply to all versions. This chapter is limited to those functions useful in single-chip implementations of the MCS®

-48. The Chapter on the Expanded MCS®

| | | -48
System discusses functions which allow expansion of program memory, data memory, and input output capability.

## 2.0 ARCHITECTURE

The following sections break the MCS-48 Family into functional blocks and describe each in detail. The following description will use the 8048AH as the representative product for the family. See 4.

## 2.1 Arithmetic Section

The arithmetic section of the processor contains the basic data manipulation functions of the 8048AH and can be divided into the following blocks:
- Arithmetic Logic Unit (ALU)
- Accumulator
- Carry Flag
- Instruction Decoder

In a typical operation data stored in the accumulator is combined in the ALU with data from another source on the internal bus (such as a register or I/O port) and the result is stored in the accumulator or another register.

The following is more detailed description of the function of each block.

## INSTRUCTION DECODER

The operation code (op code) portion of each program instruction is stored in the Instruction Decoder and is converted to outputs which control the function of each of the blocks of the Arithmetic Section. These lines control the source of data and the destination register as well as the function performed in the ALU.

## ARITHMETIC LOGIC UNIT

The ALU accepts 8-bit data words from one or two sources and generates an 8-bit result under control of the Instruction Decoder. The ALU can perform the following functions:

- Add With or Without Carry
- AND, OR, Exclusive OR
- Increment/Decrement
- Bit Complement
- Rotate Left, Right
- Swap Nibbles
- BCD Decimal Adjust

If the operation performed by the ALU results in a value represented by more than 8 bits (overflow of most significant bit), the Carry Flag is set in the Program Status Word.

## ACCUMULATOR

The accumulator is the single most important data register in the processor, being one of the sources of input to the ALU and often the destination of the result of operations performed by the ALU. Data to and from I/O ports and memory also normally passes through the accumulator.

## 2.2 Program Memory

Resident program memory consists of 1024, 2048 or 4096 words eight bit wide which are addressed by the program counter. In the 8748H and the 8749H this memory is user programmable and erasable EPROM; in the 8048AH/ 8049AH/8050AH the memory is ROM which is mask programmable at the factory. The 8035AHL/8039AHL/ 8040AHL has no internal program memory and is used with external memory devices. Program code is completely interchangeable among the various versions. To access the upper 2K of program memory in the 8050AH and other MCS-48 devices, a select memory bank and a JUMP or CALL instruction must be executed to cross the 2K boundary.

There are three locations in Program Memory of special importance as shown in 5.

LOCATION 0
Activating the Reset line of the processor causes the first instruction to be fetched from location 0.

LOCATION 3
Activating the Interrupt input line of the processor (if interrupt is enabled) causes a jump to subroutine at location 3.

LOCATION 7
A timer/counter interrupt resulting from timer counter overflow (if enabled) causes a jump to subroutine at location 7.

Therefore, the first instruction to be executed after initialization is stored in location 0, the first word of an external interrupt service subroutine is stored in location 3 and the first word of a timer/counter service routines is stored in location 7. Program memory can be used to

4

## SINGLE COMPONENT MCS® -48 SYSTEM

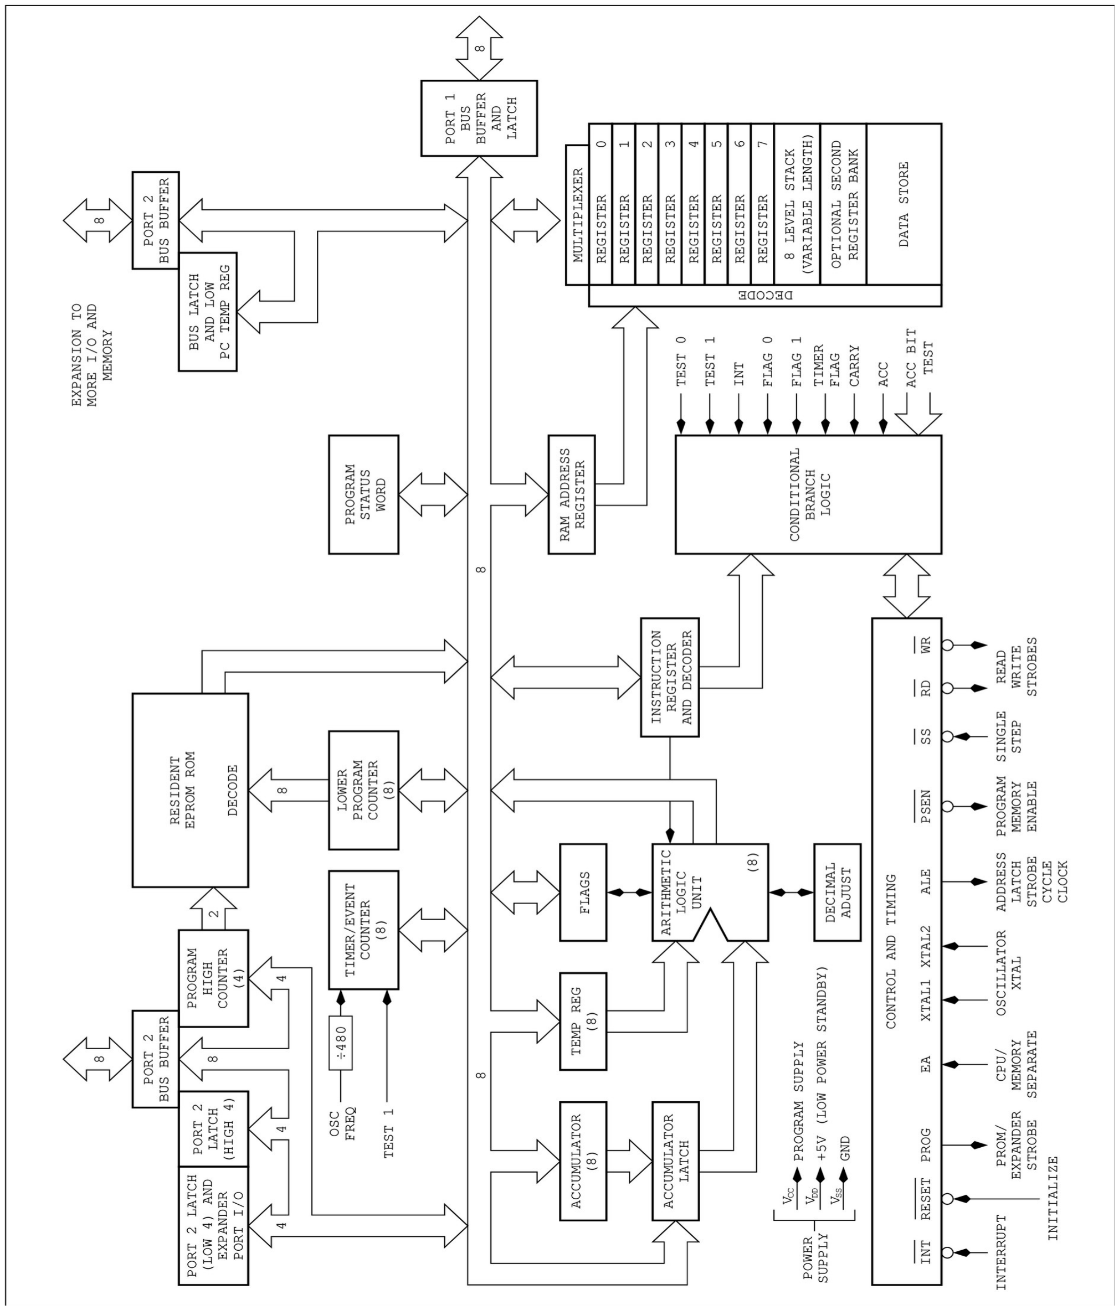
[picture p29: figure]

5

Figure 4: 8748H/8048H/8749AH/8050AH Block Diagram store constants as well as program instructions. Instructions such as MOVP and MOVP3 allow easy access to data "lookup" tables.

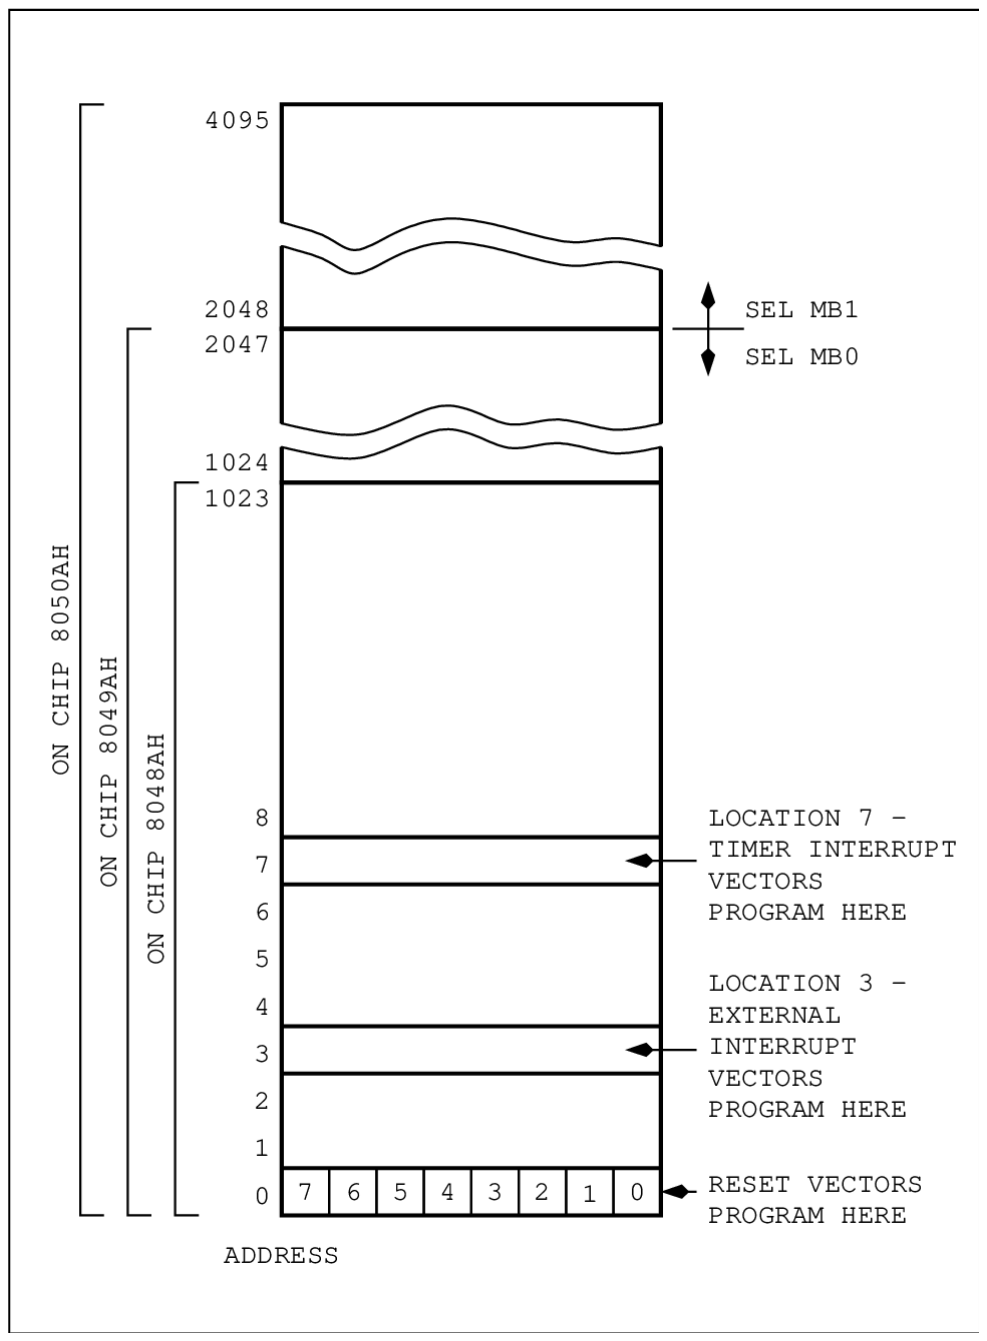
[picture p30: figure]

## 2.3 Data Memory

Resident data memory is organized as 64, 128 or 256 by 8-bits wide in the 8048AH, 8049AH and 8058AH. All locations are indirectly addressable through either of two RAM Pointer Registers which reside at address 0 and 1 of the register array. In addition, as shown in 6, the first 8 locations (0-7) of th array are designated as working registers and are directly addressable by several instructions. Since these registers are more easily addressed, they are usually used to store frequently accessed intermediate results. The DJNZ instruction makes very efficient use of the working registers as program loop counters by allowing the programmer to decrement and test the register in a single instruction.

By executing a Register Bank Switch instruction (SEL RB), RAM locations 24-31 are designated as the working registers in place of locations 0-7 and are then directly addressable. This second bank of working registers may be used as an extension of the first bank or reserved for use during interrupt service subroutines allowing the registers of Bank 0 used in the main program to be instantly "saved" by a Bank Switch. Note that if this second bank is not used, locations 24-31 are still addressable as general purpose RAM. Since the two RAM pointer Registers R0 and R1 are a part of the working register array, bank switch effectively creates two more pointer registers (R0/ and R1/) which can be used with R0 and R1 to easily access up to four separate working areas in RAM at one time. RAM locations 8-23 also serve a dual role in that they contain the program counter stack as explained in Section 2.6. These locations are addressed by the Stack Pointer during subroutine calls as well as by RAM Pointer Registers R0 and R1. If the level of subroutine nesting is less than 8, all stack registers are not required and can be used as general purpose RAM locations. Each level of subroutine nesting not used provides the user with two additional RAM locations.

6

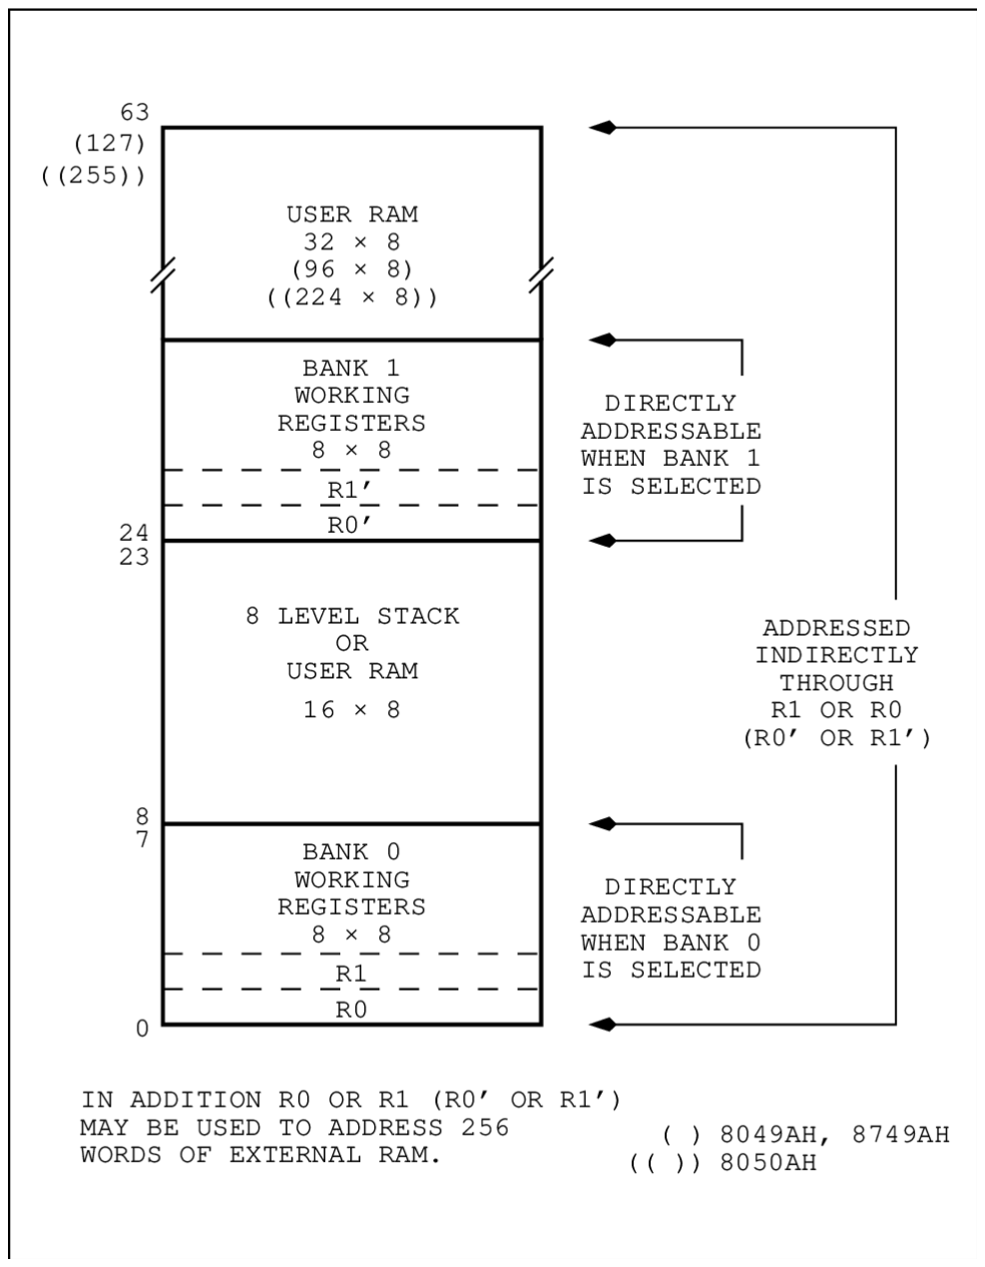
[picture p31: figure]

Figure 6. Data Memory Map

Figure 5. Program Memory Map

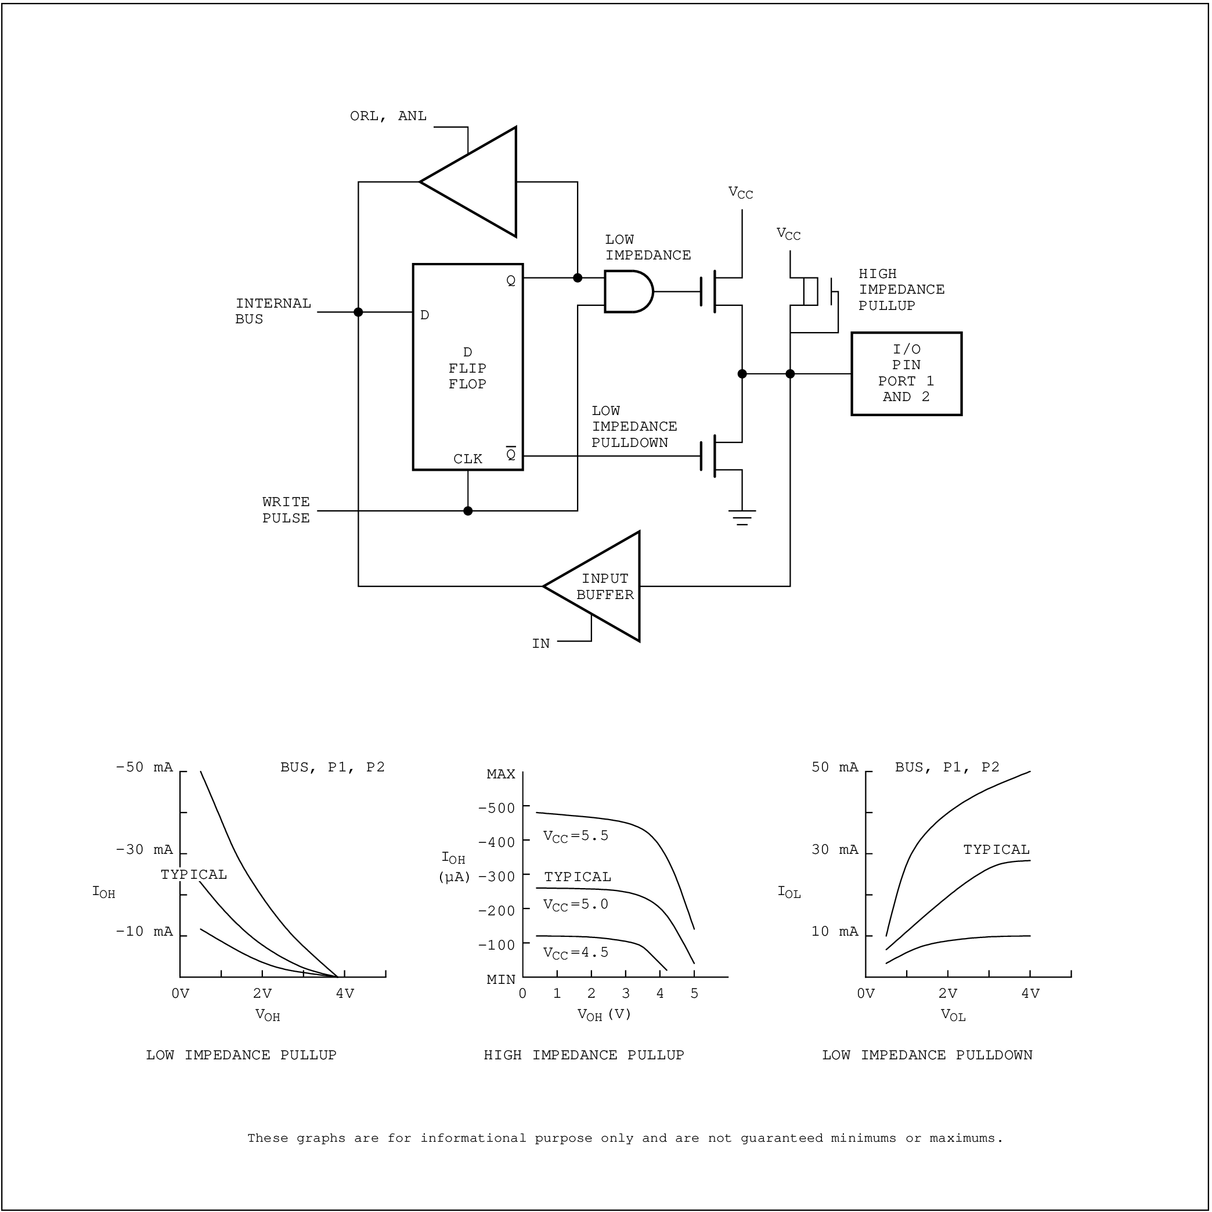
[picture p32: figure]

7

Figure 7. "Quasi-bidirectional" Port Structure

## 2.4 Input/Output

The 8048AH has 27 lines which can be used for input or output functions. These lines are grouped as 3 ports of 8 lines each which serve as either inputs, outputs or bidirectional ports and 3 "test" inputs which can alter program sequences when tested by conditional jump instructions.

## PORTS 1 AND 2

Ports 1 and 2 are each 8 bits wide and have identical characteristics. Data written to these ports is statically latched and remains unchanged until rewritten. As input ports these lines are non-latching, i. e., inputs must be present until read by an input instruction. Inputs are fully TTL compatible and outputs will drive one standard TTL load.

The lines of ports 1 and 2 are called quasi-bidirectional because of a special output circuit structure which allows each line to serve as an input and output or both even though outputs are statically latched. 7 shows the circuit configuration in detail. Each line is continuously pulled to VCC through a resistive device of relatively high impedance.

This pullup is sufficient to provide the source current for a TTL high level yet can be pulled low by a standard TTL gate thus allowing the same pin to be used for both input and output. To provide fast switching times in a "0" to "1" transition a relatively low impedance device is switched in momentarily (≈ 1/5 of a machine cycle) whenever a "1" is written to the line. When a "0" is written to the line, a low impedance device overcomes the light pullup and provides TTL current sinking capability. Since the pulldown transistor is a low impedance device a "1" must first be written to any line which is to be used as an input. Reset initializes all lines to the high impedance "1" state.

It is important to note that the ORL and the ANL are read/ write operations. When executed, the μC "reads" the port, modifies the data according to the instruction, then "writes" the data back to the port. The "writing" (essentially an OUTL instruction) enables the low impedance pull-up momentarily again even if the data was unchanged from a "1". This specifically applies to configurations that have inputs and outputs mixed together on the same port. See also section 8 in the Expanded MCS-48 System chapter.

## BUS

Bus is also an 8-bit port which is a true bidirectional port with associated input and output strobes. If the bidirectional feature is not needed, Bus can serve as either a statically latched output port or non-latching input port. Input and output lines on this port cannot be mixed however.

As a static port, data is written and latched using the OUTL instruction and inputted using the INS instruction. The INS and OUTL instructions generate pulses on the corresponding RD' and WR' output strobe lines; however, in the static port mode they are generally not used. As a bidirectional port the MOVX instructions are used to read and write the port. A write to the port generates a pulse on the WR' output line and output data is valid at the trailing edge of WR'. A read of the port generates a pulse on the RD' output line and input data must be valid at the trailing edge of RD'. When not being written or read, the BUS lines are in a high impedance state. See also sections 7 and 8 in the Expanded MCS-48 System chapter.

## 2.5 Test and INT Inputs

Three pins serve as inputs and are testable with the conditional jump instructions. These are T0, T1, and INT'. These pins allow inputs to cause program branches without the necessity to load an input port into the accumulator. The T0, T1, and INT' pins have other possible functions as well. See the pin description in Section 3.

## 2.6 Program Counter and Stack

The Program Counter is an independent counter while the Program Counter Stack is implemented using pairs of registers in the Data Memory Area. Only 10, 11 or 12 bits of the Program Counter are used to address the 1024, 2048 or 4096 words of on-board program memory of the 8048AH, 8049AH or 8050AH, while the most significant bits can be used for external Program Memory fetches. See 8. The Program Counter is initialized to zero by activating the Reset line.

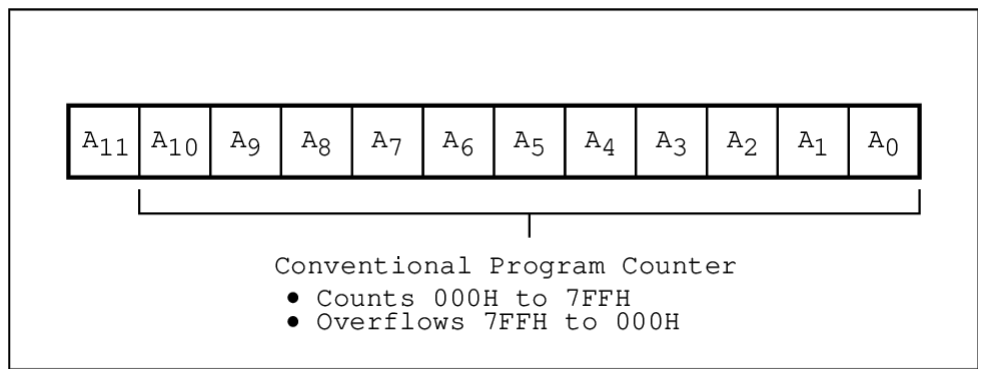
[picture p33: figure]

An interrupt or CALL to a subroutine causes the contents of the program counter to be stored in one of the 8 register pairs of the Program Counter Stack as shown in 9. The pair to be used is determined by a 3-bit Stack Pointer which is part of the Program Status Word (PSW).

8

Figure 8. Program Counter


Data RAM locations 8-23 are available as stack registers and are used to store the Program Counter and 4 bits of PSW as shown in 9. The Stack Pointer when initialized to 000 points to RAM location 8 and 9. The first subroutine jump or interrupt results in the program counter contents being transferred to locations 8 and 9 of the RAM array. The stack pointer is then incremented by one to point to locations 10 and 11 in anticipation of another CALL. Nesting of subroutines within subroutines can continue up to 8 times without overflowing the stack. If overflow does occur, the deepest address stored (locations 8 and 9) will be overwritten and lost since the stack pointer overflows from 111 to 000. It also underflows from 000 to 111.

The end of a subroutine, which is signaled by a return instruction (RET or RETR), causes the Stack Pointer to be decremented and the contents of the resulting register pair to be transferred to the Program Counter.

## 2.7 Program Status Word

An 8-bit status word which can be loaded to and from the accumulator exists called the Program Status Word (PSW). 10 shows the information available in the word. The Program Status Word is actually a collection of flipflops throughout the machine which can be read or written as a whole. The ability to write the PSW allows for easy restoration of machine status after a power down sequence.


The upper four bits of PSW are stored in the Program Counter Stack with every call to subroutine or interrupt vector and are optionally restored upon return with the RETR instruction. The RET return instruction does not update PSW.

The PSW bit definitions are as follows:

Bits 0-2: | Stack Pointer bits (S0, S1, S2)
Bit 3: | Not used ("1" level when read)
Bit 4: | Working Register Bank Switch Bit (BS) 0 = Bank 0 1 = Bank 1
Bit 5: | Flag 0 bit (F0) user controlled flag which can be complemented or cleared and tested with the conditional jump instruction JF0.
Bit 6: | Auxiliary Carry (AC) carry bit generated by an ADD instruction and used by the decimal adjust instruction DA A.
Bit 7: | Carry (CY) carry flag which indicates that the previous operation has resulted in overflow of the accumulator.

## 2.8 Conditional Branch Logic

The conditional branch logic within the processor enables several conditions internal and external to the processor to be tested by the user program. By using the conditional jump instruction the conditions that are listed in 1 can affect a change in the sequence of the program execution.

9

Figure 10. Program Status Word (PSW)

Figure 9. Program Counter Stack

Table 1

Device Testable | Jump Condition (Jump On)
Accumulator Accumulator Bit Carry Flag User Flags (F0, F1) Timer Overflow Flag Test Inputs (T0, T1) Interrupt Input (INT) | All zeros ---0 ------0 0 | not all zeros 1 1 1 1 1 ---

## 2.9 Interrupt

An interrupt sequence is initiated by applying a low "0" level input to the INT' pin. Interrupt is level triggered and active low to allow "WIRE ORing" of several interrupt sources at the input pin. 11 shows the interrupt logic of the 8048AH. The interrupt line is sampled every instruction cycle and when detected causes a "call to subroutine" at location 3 in program memory as soon as all cycles of the current instruction are complete. On 2-cycle instructions the interrupt line is sampled on the 2nd cycle only. INT' must be held low for at least 3 machine cycles to ensure proper interrupt operations. As in any CALL to subroutine, the Program Counter and Program Status word is saved in the stack. For a description of this operation see the previous section, Program Counter and Stack. Program Memory location 3 usually contains an unconditional jump to an interrupt service subroutine elsewhere in program memory. The end of an interrupt service subroutine is signaled by the execution of a Return and Restore Status instruction RETR. The interrupt system is single level in that once an interrupt is detected all further interrupt requests are ignored until execution of an RETR reenables the interrupt input logic. This occurs at the beginning of the second cycle of the RETR instruction. This sequence holds true also for an internal interrupt generated by timer overflow. If an internal timer/counter generated interrupt and an external source will be recognized at the same time, the external source will be recognized. See the following Timer/Counter section for a description of timer interrupt. If needed, a second external interrupt can be created by enabling the timer/counter interrupt, loading FFH in the Counter (one less than terminal count) and enabling the event counter mode. A "1" to "0" transition on the T1 input will then cause an interrupt vector to location 7.

## INTERRUPT TIMING

The interrupt input may be enabled or disabled under Program Control using the EN I and DIS I instructions. Interrupts are disabled by Reset and remain so until enabled by the user's program. An interrupt request must be removed before the RETR instruction is executed upon return from the service subroutine otherwise the processor will re-enter the service routine immediately. Many peripheral devices prevent this situation by resetting their interrupt request line whenever the processor accesses (Reads or Writes) the peripheral's data buffer register. If the interrupt device does not require access by the processor, one output line of the 8048AH may be designated as an "interrupt acknowledge" which is activated by the service subroutine to reset the interrupt request. The INT' pin may also be tested using the conditional jump instruction JNI. This instruction may be used to detect the presence of a pending interrupt before interrupts are enabled. If interrupt is left disabled, INT' may be used as another test input like T0 and T1.

## 2.10 Timer/Counter

The 8048AH contains a counter to aid the user in counting external events and generating accurate time delays without placing a burden on the processor for these functions. In both modes the counter operation is the same, the only difference being the source of the input to the counter. The timer/event counter is show in 12.

## COUNTER

The 8-bit binary counter is presettable and readable with the MOV instructions which transfer the contents of the accumulator to the counter and vice versa. The counter content may be affected by Reset and should be initialized by software. The counter is stopped by a Reset or STOP TCNT instruction and remains stopped until started as a timer by a STRT T instruction or as an event counter by a STRT CNT instruction. Once started, the counter will increment to this maximum count (FF) and overflow to zero continuing its count until stopped by a STOP TCNT instruction or Reset.

The increment from maximum count to zero (overflow) results in the setting of an overflow flag flip-flop and in the generation of an interrupt request. The state of the overflow flag is testable with the conditional jump instruction JTF. The flag is reset by executing a JTF or by Reset. The interrupt request is stored in a latch and then ORed with the external interrupt input INT. The timer interrupt may be enabled or disabled independently of external interrupt by the EN TCNTI and DIS TCNTI instructions. If enabled, the counter overflow will cause a subroutine call to location 7 where the timer or counter service routine may be stored.

10


11

Figure 11. Interrupt Logic


If timer and external interrupts occur simultaneously, the external interrupt will be recognized and the Call will be to location 3. Since the timer interrupt is latched it will remain pending until the external device is serviced and immediately be recognized upon return from the service routine. The pending timer interrupt is reset by the Call to location 7 or may be removed by executing a DIS TCNTI instruction.

## AS AN EVENT COUNTER

Execution of a START CNT instruction connects the T1 input pin to the counter input and enables the counter. The T1 input is sampled at the beginning of state 3 or in later MCS-48 devices in state time 4. Subsequent high to low transitions on T1 will cause the counter to increment. T1 must be held low for at least 1 machine cycle to ensure it won't be missed. The maximum rate at which the counter may be incremented is once per three instruction cycles (every 5.7 µsec when using an 8 MHz crystal) --- there is no minimum frequency. T1 input must remain high for at least 1/5 machine cycle after each transition.

## AS A TIMER

Execution of a START T instruction connects an internal clock to the counter input and enables the counter. The internal clock is derived by passing the basic machine cycle clock through a ÷ 32 prescaler. The prescaler is reset during the START T instruction. The resulting clock increments the counter every 32 machine cycles. Various delays from 1 to 256 counts can be obtained by presetting the counter and detecting overflow. Times longer than 256 counts may be achieved by accumulating multiple overflows in a register under software control. For time resolution less than 1 count an external clock can be applied to the T1 input and the counter operated in the event counter mode. ALE divided by 3 or more can serve as this external clock. Very small delays or "fine tuning" of larger delays can be easily accomplished by software delay loops.

Often a serial link is desirable in an MCS-48 family member. 2 lists the timer counts and cycles needed for a specific baud rate given a crystal frequency.

## 2.11 Clock and Timing Circuits

Timing generation for the 8048AH is completely self contained with the exception of a frequency reference which can be XTAL, ceramic resonator or external clock source. The Clock and Timing circuitry can be divided into the following functional blocks.

## OSCILLATOR

The on-board oscillator is a high gain parallel resonant circuit with a frequency range of 1 to 11 MHz. The X1 external pin is the input to the amplifier stage while X2 is the output. A crystal or ceramic resonator connected between X1 and X2 provides the feedback and phase shift required for oscillation. If an accurate frequency reference is not required, ceramic resonator may be used in place of the crystal.

For accurate clocking, a crystal should be used. An externally generated clock may also be applied to X1—X2 as the frequency source. See the data sheet for more information.

12

Figure 12. Timer/Event Counter

## STATE COUNTER

The output of the oscillator is divided by 3 in the State Counter to create a clock which defines the state times of the machine (CLK). CLK can be made available on the external pin T0 by executing an ENT0 CLK instruction. The output of CLK on T0 is disabled by Reset of the processor.

## CYCLE COUNTER

CLK is then divided by 5 in the Cycle Counter to provide a clock which defines a machine cycle consisting of 5 machine states as shown in 13. 14 shows the different internal operations as divided into the machine states. This clock is called Address Latch Enable (ALE) because of its function in MCS-48 systems with external memory. It is provided continuously on the ALE output pin.

## 2.12 Reset

The reset input provides a means for initialization for the processor. This Schmitt-trigger input has an internal pullup device which in combination with an external 1 µF capacitor provides an internal reset pulse of sufficient length to guarantee all circuitry is reset, as shown in 15. If the reset pulse is generated externally, the RESET pin must be held low for at least 10 milliseconds after the power supply is within tolerance. Only 5 machine cycles

(6.8 µs @ 11 MHz) are required if power is already on and the oscillator has stabilized. ALE and PSEN (if EA = 1) are active while in Reset.

Reset performs the following functions:

1) Sets program counter to zero.
2) Sets stack pointer to zero.
3) Selects register bank 0.
4) Selects memory bank 0.
5) Sets BUS to high impedance state (except when EA = 5 V).
6) Sets Ports 1 and 2 to input mode.
7) Disables interrupts (timer and external).
8) Stops timer.
9) Clears timer flag.
10) Clears F0 and F1.
11) Disables clock output from T0.

13

Table 2. Baud Rate Generation

Frequency (MHz) | TCY | T0 Prr(1/5 TCY) | Timer Prescaler (32 TCY)
4 6 8 11 | 3.75 µs 2.50 µs 1.88 µs 1.36 µs | 750 ns 500 ns 375 ns 275 ns | 120 µs 80 µs 60.2 µs 43.5 µs
Baud Rate | 4 MHz Timer Counts + Instr. Cycles | 6 MHz Timer Counts + Instr. Cycles | 8 MHz Timer Counts + Instr. Cycles | 11 MHz Timer Counts + Instr. Cycles
110 | 75 + 24 Cycles .01% Error | 113 + 20 Cycles .01% Error | 151 + 3 Cycles .01% Error | 208 + 28 Cycles .01% Error
300 | 27 + 24 Cycles .1% Error | 41 + 21 Cycles .03% Error | 55 + 13 Cycles .01% Error | 76 + 18 Cycles .04% Error
1200 | 6 + 30 Cycles .1% Error | 10 + 13 Cycles .1% Error | 12 + 27 Cycles .06% Error | 19 + 4 Cycles .12% Error
1800 | 4 + 20 Cycles .1% Error | 6 + 30 Cycles .1% Error | 9 + 7 Cycles .17% Error | 12 + 24 Cycles .12% Error
2400 | 3 + 15 Cycles .1% Error | 5 + 6 Cycles .4% Error | 6 + 24 Cycles .29% Error | 9 + 18 Cycles .12% Error
4800 | 1 + 23 Cycles 1.0% Error | 2 + 19 Cycles .4% Error | 3 + 14 Cycles .74% Error | 4 + 25 Cycles .12% Error


## 2.13 Single-Step

This feature, as pictured in 16, provides the user with a debug capability in that the processor can be stepped through the program one instruction at a time. While stopped, the address of the next instruction to be fetched is available concurrently on BUS and the lower half of Port
2. The user can therefore follow the program through each of the instruction steps. A timing diagram, showing the interaction between output ALE and input SS', is shown. The BUS buffer contents are lost during single step; however, a latch may be added to reestablish the lost I/O capability if needed. Data is valid at the leading edge of ALE.

14

Figure 13. MCS-48 Timing Generation and Cycle Timing


15

Figure 14. 8048AH/8049AH Instruction Timing Diagram


## TIMING

The 8048AH operates in a single-step mode as follows:

1) The processor is requested to stop by applying a low level on SS'.
2) The processor responds by stopping during the address fetch portion of the next instruction. If a double cycle instruction is in progress when the single step command is received, both cycles will be completed before stopping.
3) The processor acknowledges it has entered the stopped state by raising ALE high. In this state (which can be maintained indefinitely) the address of the next instruction to be fetched is present on BUS and the lower half of port 2.
4) SS' is then raised high to bring the processor out of the stopped mode allowing it to fetch the next instruction. The exit from stop is indicated by the processor brining ALE low.
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

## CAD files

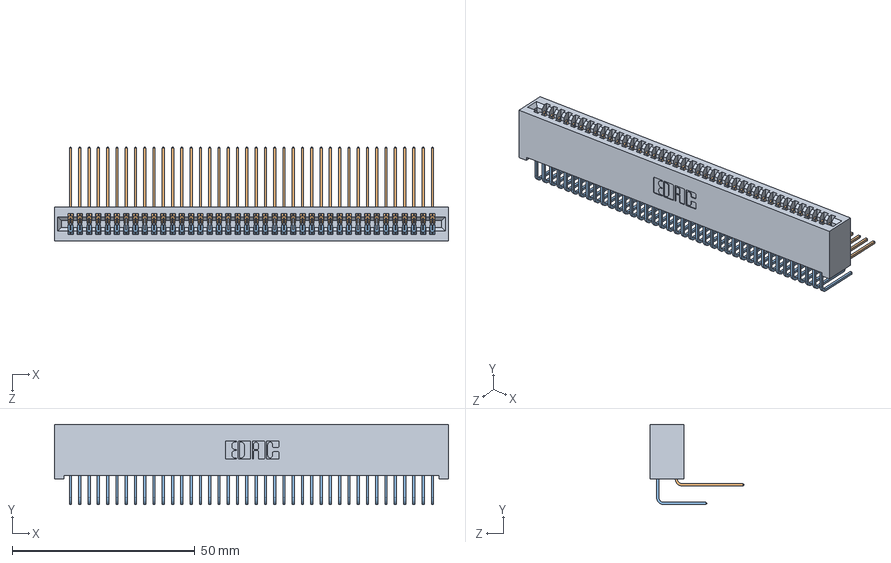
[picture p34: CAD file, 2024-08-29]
Schematics/RiserCard/components/342-080-558-201 - EDAC Card Edge Connector.STEP
107.8 x 21.9 x 25.8 mm
342 Part_Lugless
345-292-001_558 559 Tail - 1 x 40
345-292-001_558 Tail - 2 x 40

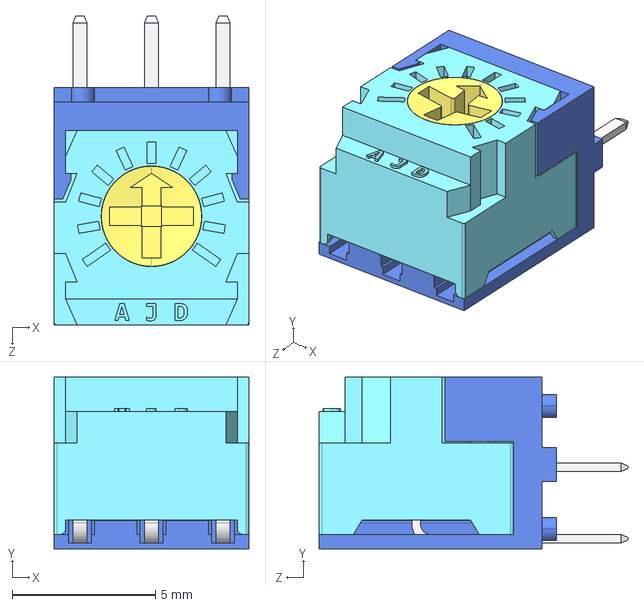
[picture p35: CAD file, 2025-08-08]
Schematics/_KiCad/3DModels/GF063X1.STEP
6.80 x 6.00 x 10.8 mm
GF063X1
SOPORTE_01

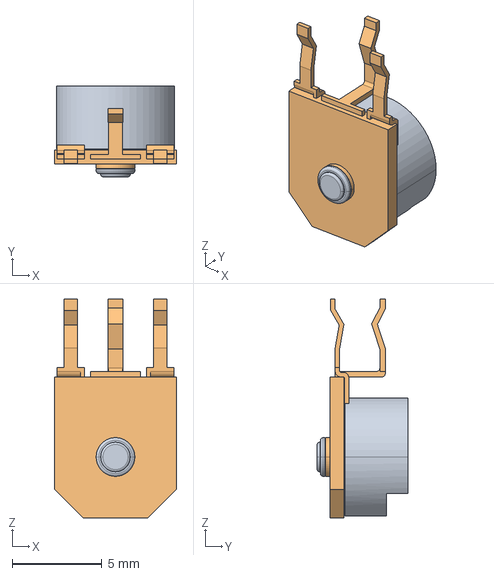
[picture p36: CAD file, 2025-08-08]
Schematics/_KiCad/3DModels/3306W.stp
6.81 x 5.05 x 12.2 mm

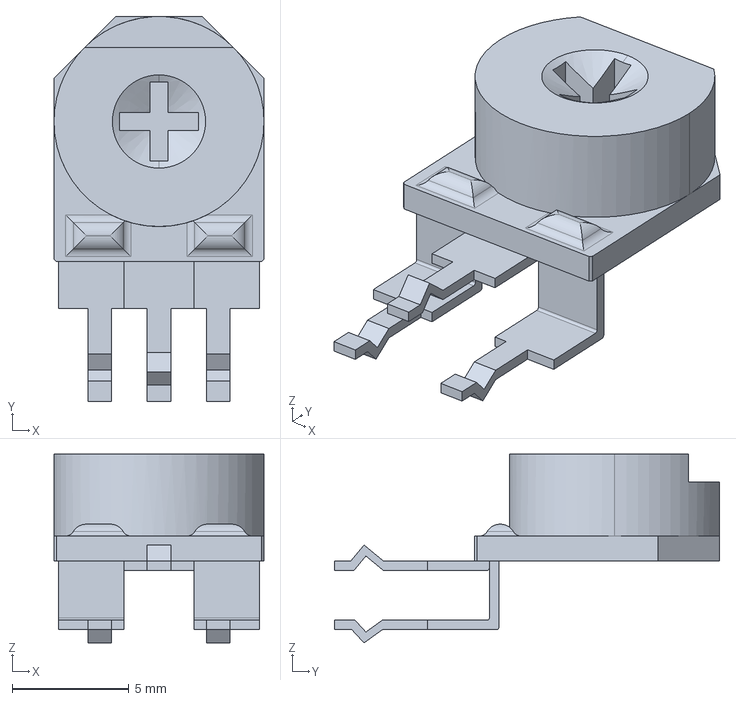
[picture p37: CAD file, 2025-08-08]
Schematics/_KiCad/3DModels/3319W.stp
8.99 x 16.5 x 8.08 mm

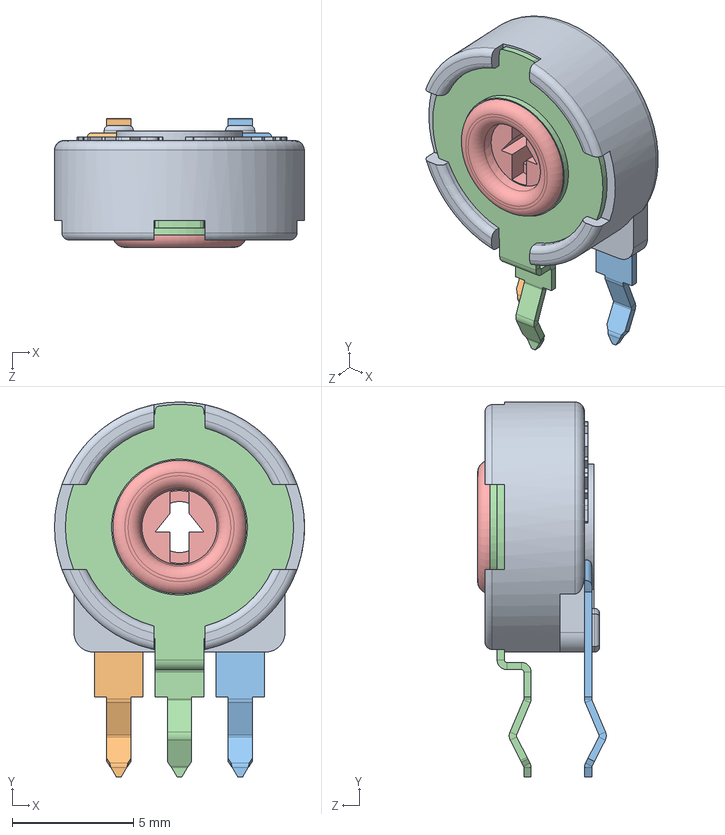
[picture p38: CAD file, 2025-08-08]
Schematics/_KiCad/3DModels/PT10_PTC10_LH02.STEP
10.3 x 15.4 x 5.30 mm
PT10LH02-CARCASA
PT10LH02-TERMINAL DERECHO
PT10LH02-TERMINAL IZQUIERDO
PT10LH02-COLECTOR
PT10LH02-PORTACURSOR_Predeterminada

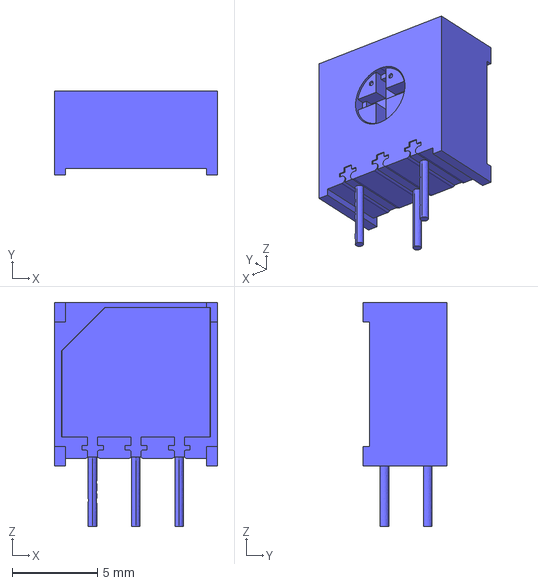
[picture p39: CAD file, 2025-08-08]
Schematics/_KiCad/3DModels/3386V001XXX.stp
9.58 x 4.95 x 13.1 mm

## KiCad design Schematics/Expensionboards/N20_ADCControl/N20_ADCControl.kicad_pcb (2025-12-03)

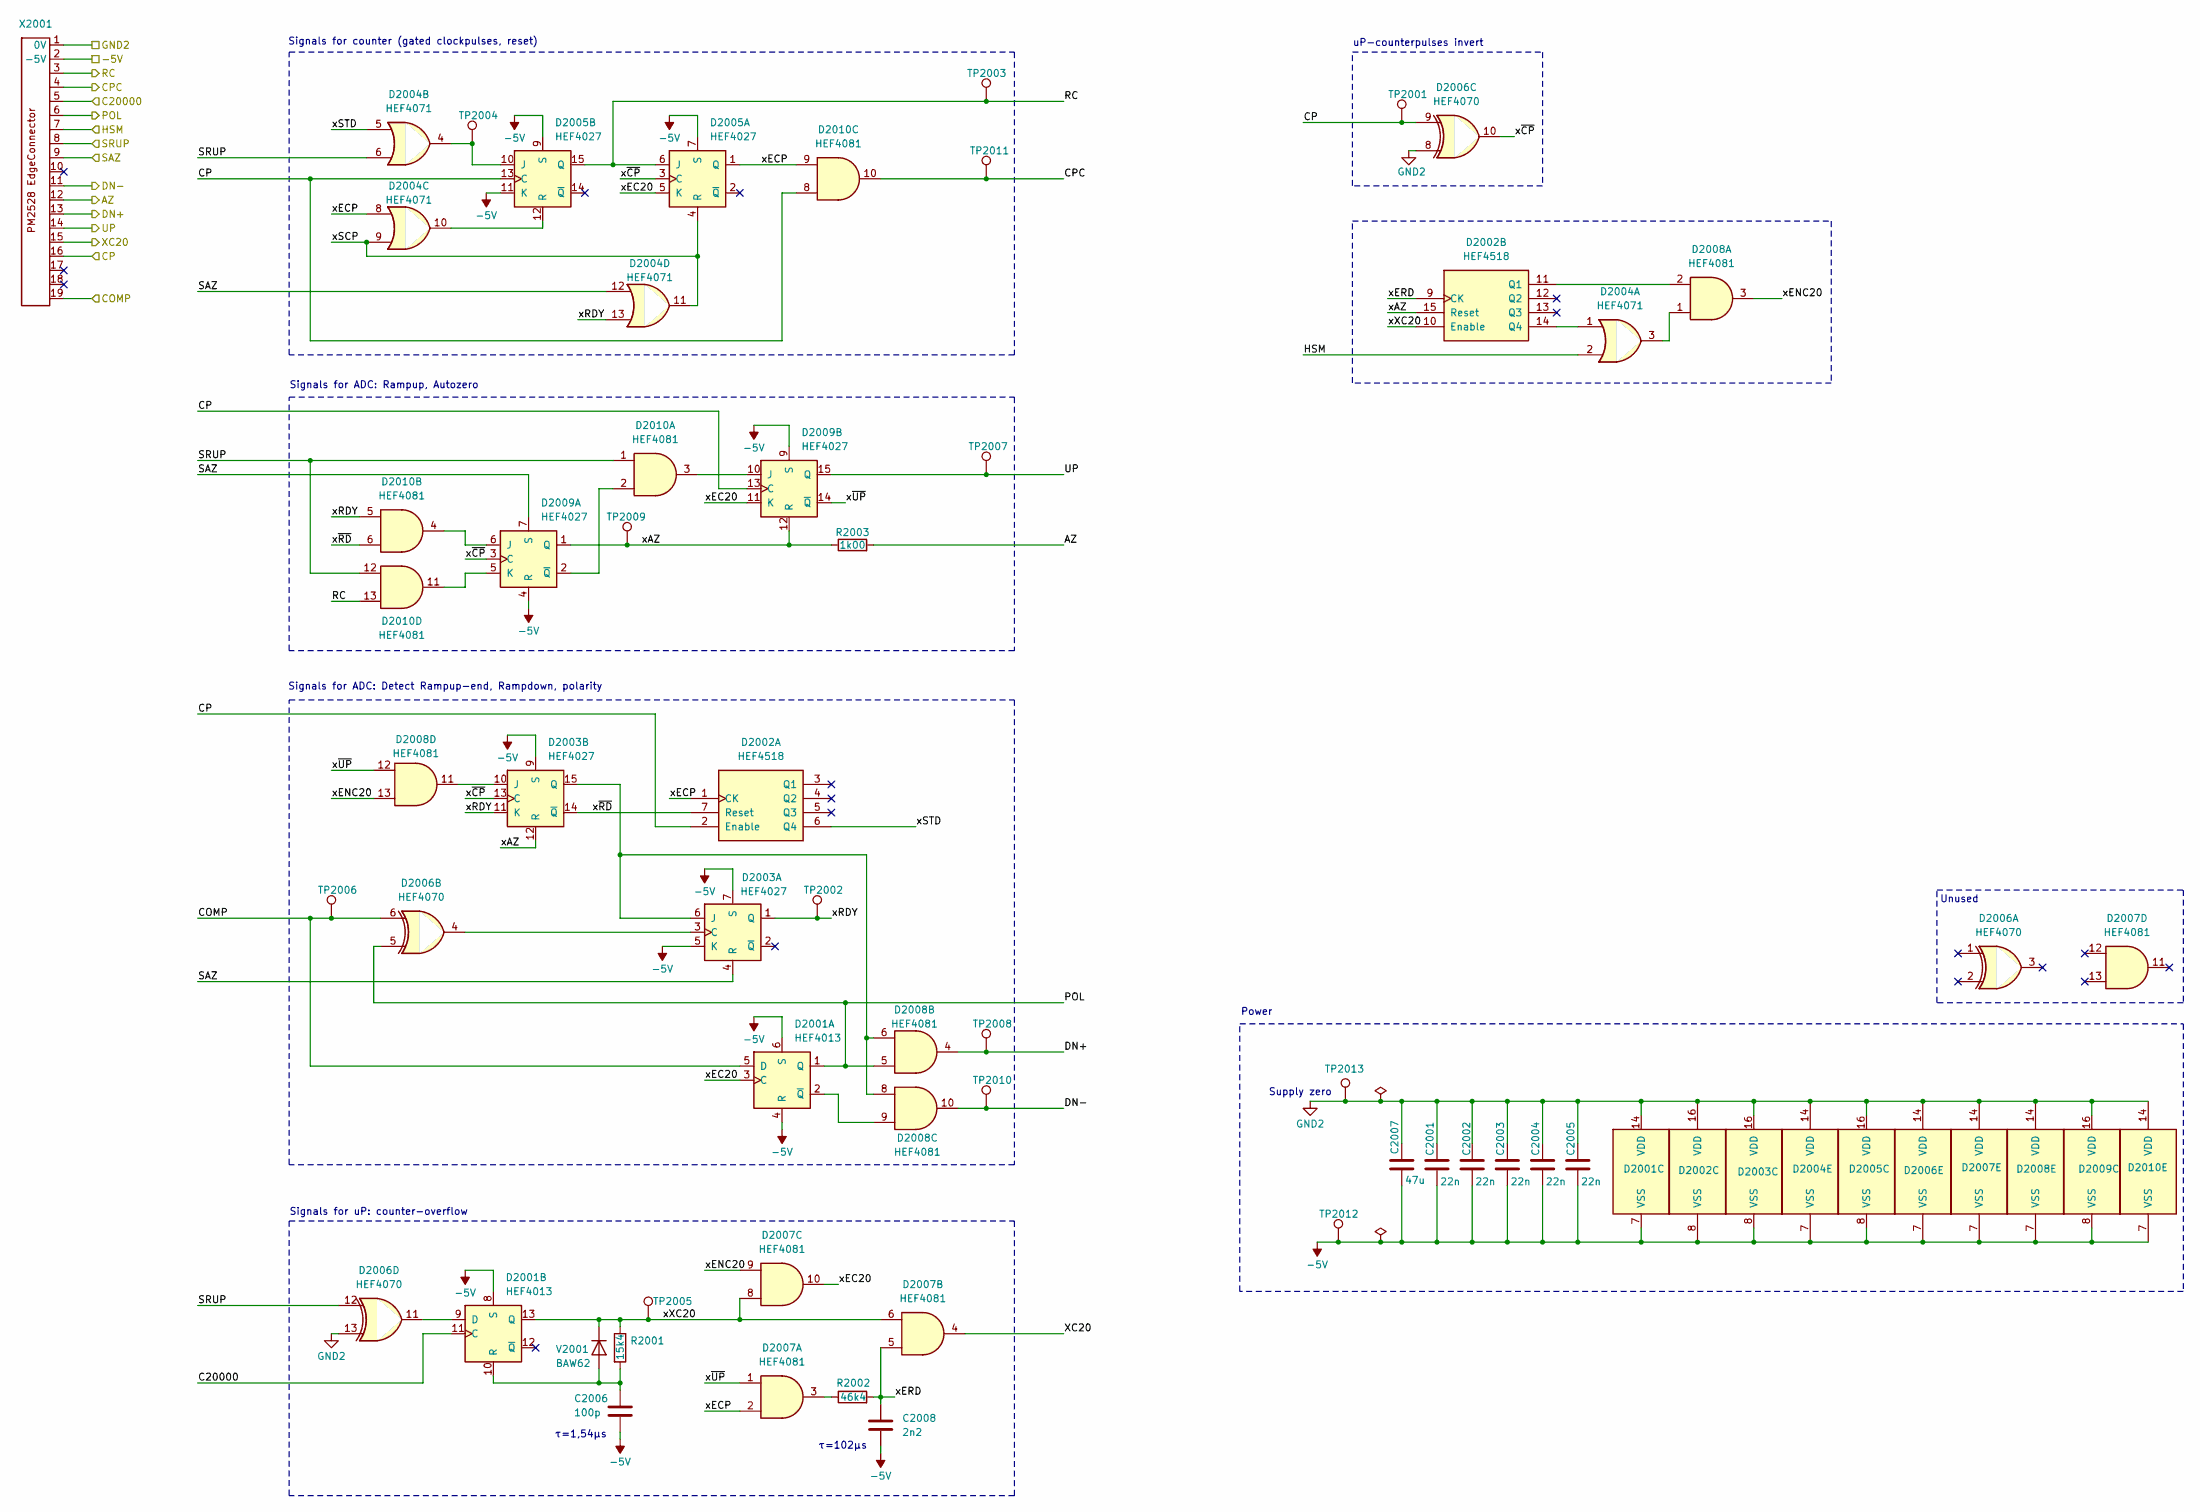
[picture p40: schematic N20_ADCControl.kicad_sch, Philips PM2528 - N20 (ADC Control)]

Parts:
C2001, C2002, C2003, C2004, C2005: 22n; C_Disc_D5.0mm_W2.5mm_P5.00mm
C2006: 100p; C_Disc_D5.0mm_W2.5mm_P5.00mm
C2007: 47u; CP_Axial_L10.0mm_D6.0mm_P15.00mm_Horizontal
C2008: 2n2; C_Disc_D5.0mm_W2.5mm_P5.00mm
D2001: HEF4013; DIP-14_W7.62mm
D2002: HEF4518; DIP-16_W7.62mm
D2003, D2005, D2009: HEF4027; DIP-16_W7.62mm
D2004: HEF4071; DIP-14_W7.62mm
D2006: HEF4070; DIP-14_W7.62mm
D2007, D2008, D2010: HEF4081; DIP-14_W7.62mm
R2001: 15k4; R_Axial_DIN0207_L6.3mm_D2.5mm_P10.16mm_Horizontal
R2002: 46k4; R_Axial_DIN0207_L6.3mm_D2.5mm_P10.16mm_Horizontal
R2003: 1k00; R_Axial_DIN0207_L6.3mm_D2.5mm_P10.16mm_Horizontal
TP2001, TP2002, TP2003, TP2004, TP2005, TP2006, TP2007, TP2008, TP2009, TP2010, TP2011, TP2012, TP2013: TestPoint; Pin_D0.9mm_L10.0mm_W2.4mm_FlatFork
V2001: BAW62; D_T-1_P10.16mm_Horizontal
X2001: PM2528_RiserCardConnector

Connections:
-5V: C2001.2, C2002.2, C2003.2, C2004.2, C2005.2, C2006.2, C2007.2, C2008.2, D2001.4 (R), D2001.6 (S), D2001.7 (VSS), D2001.8 (S), D2002.8 (VSS), D2003.5 (K), D2003.7 (S), D2003.8 (VSS), D2003.9 (S), D2004.7 (VSS), D2005.7 (S), D2005.8 (VSS), D2005.9 (S), D2005.11 (K), D2006.7 (VSS), D2007.7 (VSS), D2008.7 (VSS), D2009.4 (R), D2009.8 (VSS), D2009.9 (S), D2010.7 (VSS), TP2012.1, X2001.2 (-5V)
/AZ: R2003.2, X2001.12
/C20000: D2001.11 (C), X2001.5
/COMP: D2001.5 (D), D2006.6, TP2006.1, X2001.19
/CP: D2002.2 (Enable), D2005.13 (C), D2006.9, D2009.13 (C), D2010.8, TP2001.1, X2001.16
/CPC: D2010.10, TP2011.1, X2001.4
/DN+: D2008.4, TP2008.1, X2001.13
/DN-: D2008.10, TP2010.1, X2001.11
/HSM: D2004.2, X2001.7
/POL: D2001.1 (Q), D2006.5, D2008.5, X2001.6
/RC: D2005.6 (J), D2005.15 (Q), D2010.13, TP2003.1, X2001.3
/SAZ: D2003.4 (R), D2004.12, D2009.7 (S), X2001.9
/SRUP: D2004.6, D2006.12, D2010.1, D2010.12, X2001.8
/UP: D2009.15 (Q), TP2007.1, X2001.14
/XC20: D2007.4, X2001.15
/xAZ: D2002.15 (Reset), D2003.12 (R), D2009.1 (Q), D2009.12 (R), R2003.1, TP2009.1
/xEC20: D2001.3 (C), D2005.5 (K), D2007.10, D2009.11 (K)
/xECP: D2002.1 (CK), D2004.8, D2005.1 (Q), D2007.2, D2010.9
/xENC20: D2007.9, D2008.3, D2008.13
/xERD: C2008.1, D2002.9 (CK), D2007.5, R2002.2
/xRDY: D2003.1 (Q), D2003.11 (K), D2004.13, D2010.5, TP2002.1
/xSCP: D2004.9, D2004.11, D2005.4 (R)
/xSTD: D2002.6 (Q4), D2004.5
/xXC20: D2001.13 (Q), D2002.10 (Enable), D2007.6, D2007.8, R2001.1, TP2005.1, V2001.1 (K)
/x~CP: D2003.13 (C), D2005.3 (C), D2006.10, D2009.3 (C)
/x~RD: D2002.7 (Reset), D2003.14 (~Q), D2010.6
/x~UP: D2007.1, D2008.12, D2009.14 (~Q)
GND2: C2001.1, C2002.1, C2003.1, C2004.1, C2005.1, C2007.1, D2001.14 (VDD), D2002.16 (VDD), D2003.16 (VDD), D2004.14 (VDD), D2005.16 (VDD), D2006.8, D2006.13, D2006.14 (VDD), D2007.14 (VDD), D2008.14 (VDD), D2009.16 (VDD), D2010.14 (VDD), TP2013.1, X2001.1 (0V)
unnamed: D2001.2 (~Q), D2008.9
unnamed: D2001.9 (D), D2006.11
unnamed: C2006.1, D2001.10 (R), R2001.2, V2001.2 (A)
unnamed: D2002.11 (Q1), D2008.2
unnamed: D2002.14 (Q4), D2004.1
unnamed: D2003.3 (C), D2006.4
unnamed: D2003.6 (J), D2003.15 (Q), D2008.6, D2008.8
unnamed: D2003.10 (J), D2008.11
unnamed: D2004.3, D2008.1
unnamed: D2004.4, D2005.10 (J), TP2004.1
unnamed: D2004.10, D2005.12 (R)
unnamed: D2007.3, R2002.1
unnamed: D2009.6 (J), D2010.4
unnamed: D2009.5 (K), D2010.11
unnamed: D2009.2 (~Q), D2010.2
unnamed: D2009.10 (J), D2010.3

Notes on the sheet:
τ=102μs
Signals for ADC: Rampup, Autozero
Signals for ADC: Detect Rampup-end, Rampdown, polarity
Power
Supply zero
uP-counterpulses invert
Signals for counter (gated clockpulses, reset)
τ=1,54μs
Signals for uP: counter-overflow
Unused

Board: 2 copper layers, 36 parts (0 on the bottom side), 44 nets, no tracks yet.

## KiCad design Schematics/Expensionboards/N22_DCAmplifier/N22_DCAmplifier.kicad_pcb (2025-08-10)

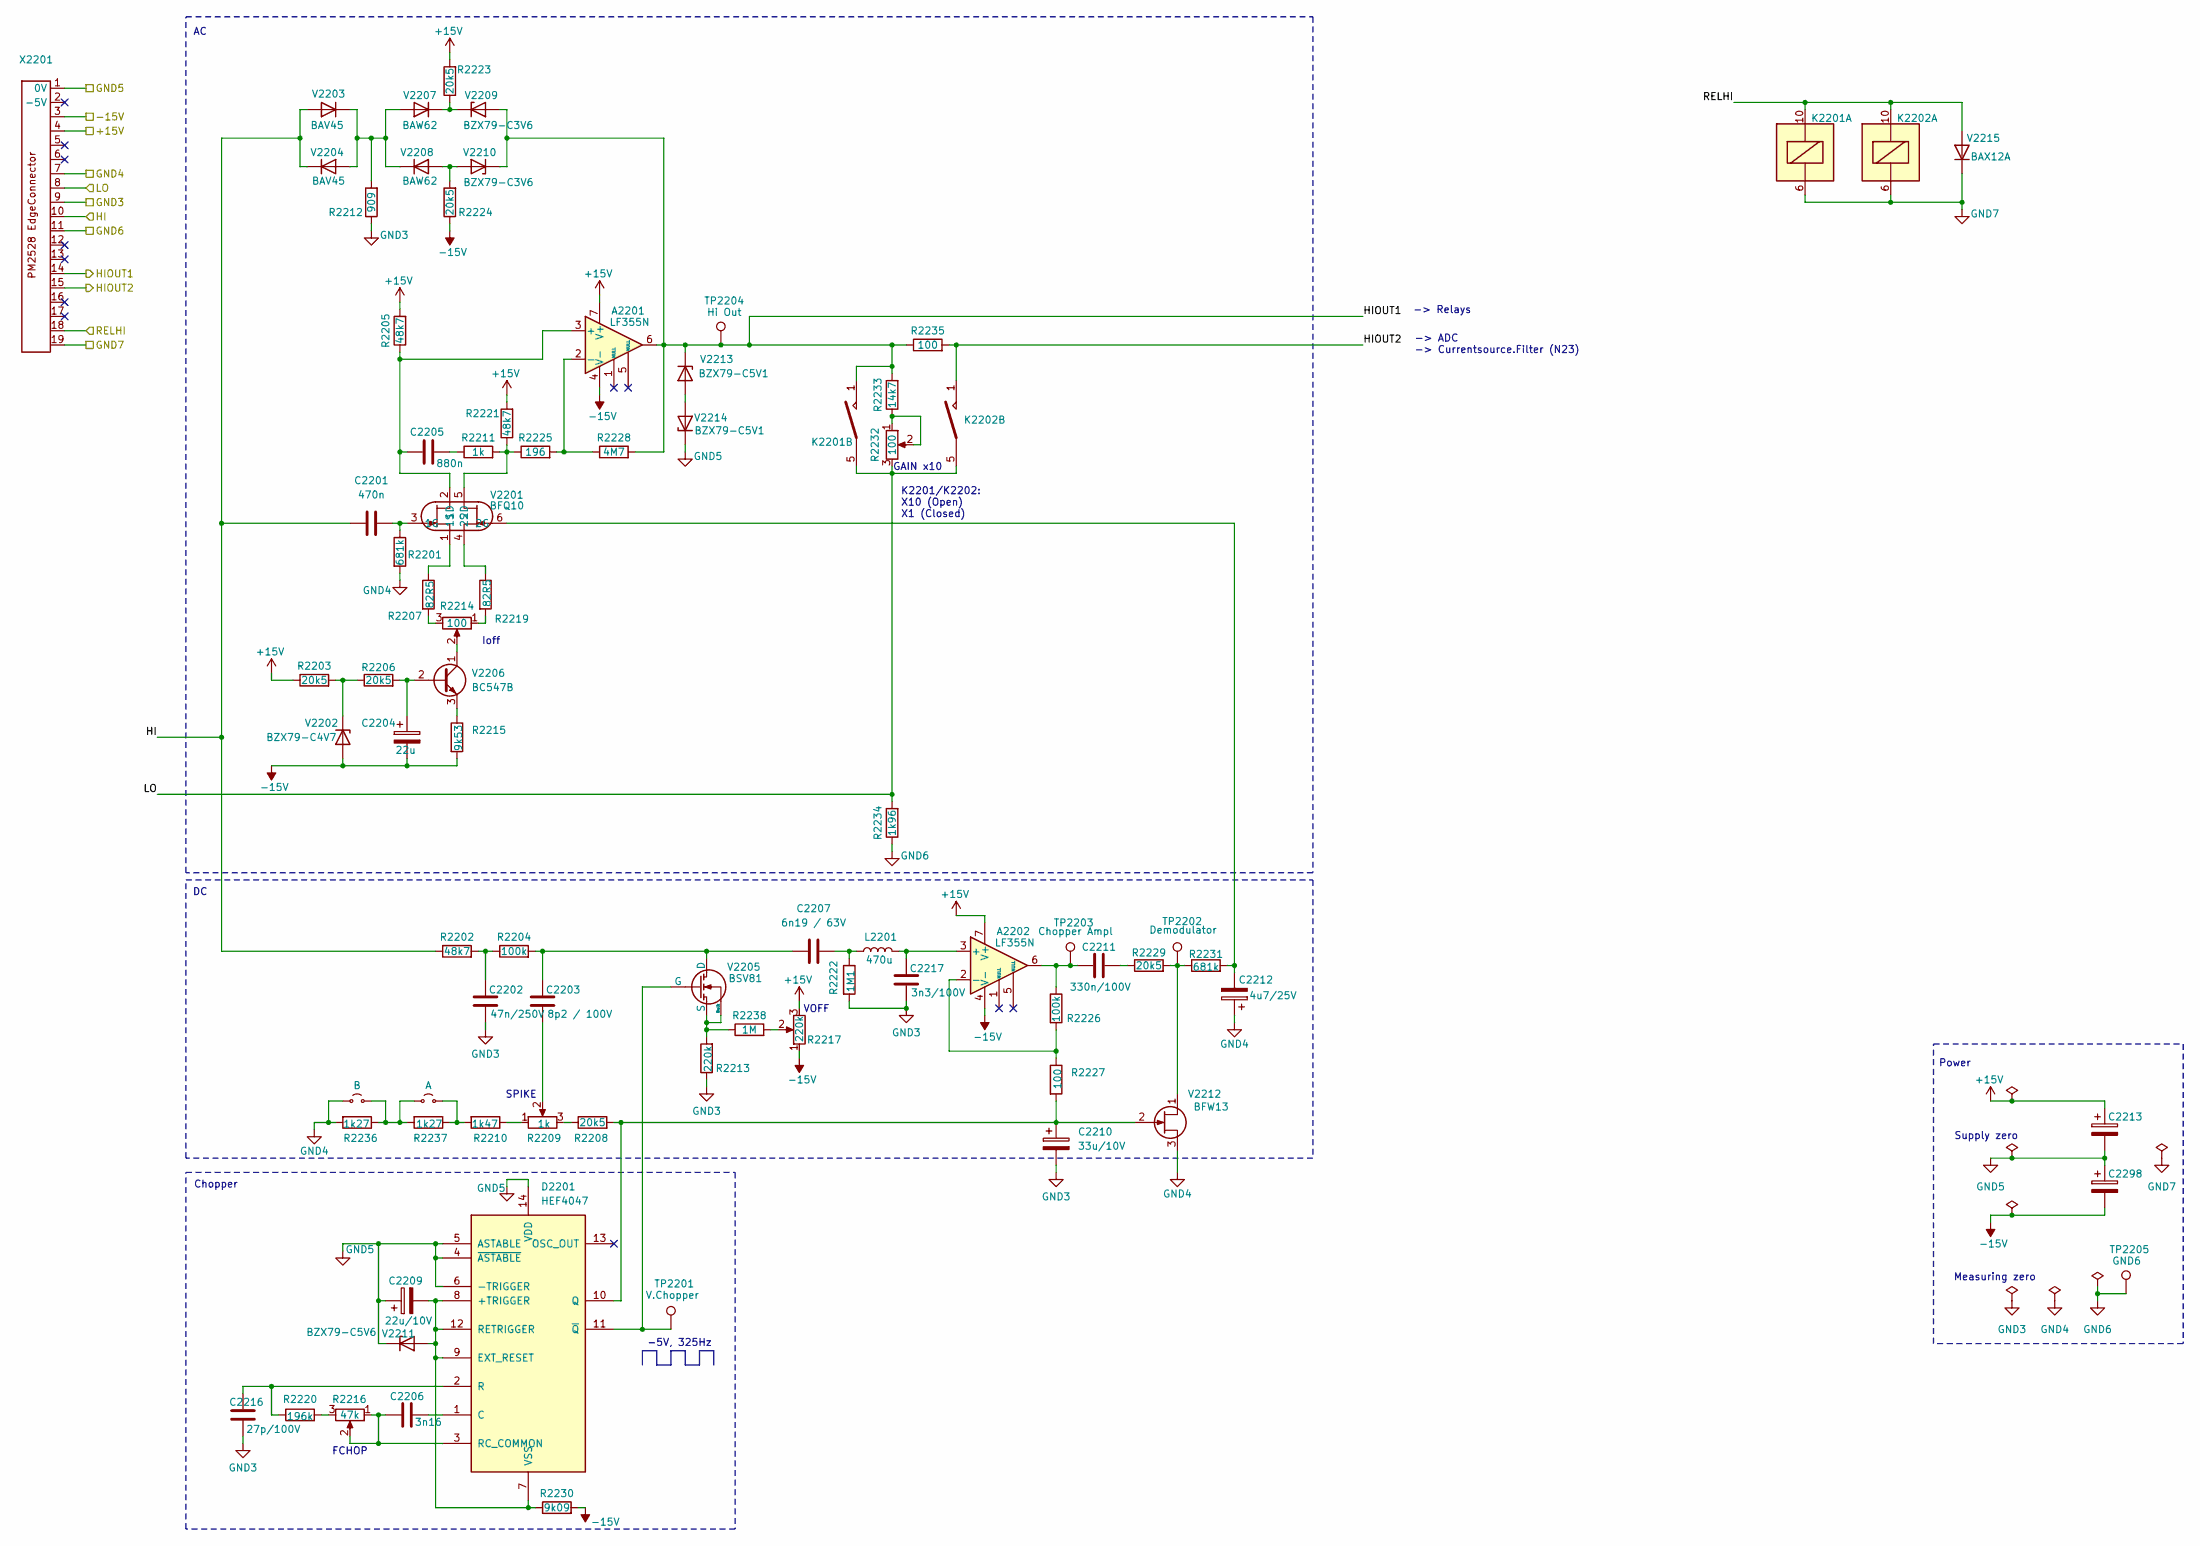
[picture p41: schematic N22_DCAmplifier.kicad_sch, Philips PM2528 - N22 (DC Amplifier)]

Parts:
A2201, A2202: LF355N; DIP-8_W7.62mm
C2201: 470n; C_Rect_L18.0mm_W6.0mm_P15.00mm_FKS3_FKP3
C2202: 47n/250V; C_Rect_L10.0mm_W4.0mm_P7.50mm_FKS3_FKP3
C2203: 8p2 / 100V; C_Disc_D4.3mm_W1.9mm_P5.00mm
C2204: 22u; CP_Radial_Tantal_D4.5mm_P5.00mm
C2205: 880n; C_Rect_L18.0mm_W5.0mm_P15.00mm_FKS3_FKP3
C2206: 3n16; C_Axial_L3.8mm_D2.6mm_P15.00mm_Horizontal
C2207: 6n19 / 63V; C_Axial_L3.8mm_D2.6mm_P15.00mm_Horizontal
C2209: 22u/10V; C_Disc_D5.0mm_W2.5mm_P5.00mm
C2210: 33u/10V; CP_Radial_Tantal_D4.5mm_P5.00mm
C2211: 330n/100V; C_Rect_L18.0mm_W5.0mm_P15.00mm_FKS3_FKP3
C2212: 4u7/25V; CP_Radial_Tantal_D4.5mm_P5.00mm
C2213, C2298: C_Polarized; C_Disc_D4.7mm_W2.5mm_P5.00mm
C2216: 27p/100V; C_Disc_D5.1mm_W3.2mm_P5.00mm
C2217: 3n3/100V; C_Disc_D4.3mm_W1.9mm_P5.00mm
D2201: HEF4047; DIP-14_W7.62mm
JP2201: A; TestPoint_Bridge_Pitch5.08mm_Drill0.7mm
JP2202: B; TestPoint_Bridge_Pitch5.08mm_Drill0.7mm
K2201, K2202: Reed relay assy
L2201: 470u; L_Axial_L9.5mm_D4.0mm_P15.24mm_Horizontal_Fastron_SMCC
R2201, R2231: 681k; R_Axial_DIN0207_L6.3mm_D2.5mm_P10.16mm_Horizontal
R2202, R2205, R2221: 48k7; R_Axial_DIN0207_L6.3mm_D2.5mm_P10.16mm_Horizontal
R2203, R2206, R2208, R2223, R2224, R2229: 20k5; R_Axial_DIN0207_L6.3mm_D2.5mm_P10.16mm_Horizontal
R2204, R2226: 100k; R_Axial_DIN0207_L6.3mm_D2.5mm_P10.16mm_Horizontal
R2207, R2219: 82R5; R_Axial_DIN0207_L6.3mm_D2.5mm_P10.16mm_Horizontal
R2209: 1k; Trimmer vertical
R2210: 1k47; R_Axial_DIN0207_L6.3mm_D2.5mm_P10.16mm_Horizontal
R2211: 1k; R_Axial_DIN0207_L6.3mm_D2.5mm_P10.16mm_Horizontal
R2212: 909; R_Axial_DIN0207_L6.3mm_D2.5mm_P10.16mm_Horizontal
R2213: 220k; R_Axial_DIN0207_L6.3mm_D2.5mm_P10.16mm_Horizontal
R2214, R2232: 100; Trimmer vertical
R2215: 9k53; R_Axial_DIN0207_L6.3mm_D2.5mm_P10.16mm_Horizontal
R2216: 47k; Trimmer vertical
R2217: 220k; Trimmer vertical
R2220: 196k; R_Axial_DIN0207_L6.3mm_D2.5mm_P10.16mm_Horizontal
R2222: 1M1; R_Axial_DIN0207_L6.3mm_D2.5mm_P10.16mm_Horizontal
R2225: 196; R_Axial_DIN0207_L6.3mm_D2.5mm_P10.16mm_Horizontal
R2227, R2235: 100; R_Axial_DIN0207_L6.3mm_D2.5mm_P10.16mm_Horizontal
R2228: 4M7; R_Axial_DIN0207_L6.3mm_D2.5mm_P10.16mm_Horizontal
R2230: 9k09; R_Axial_DIN0207_L6.3mm_D2.5mm_P10.16mm_Horizontal
R2233: 14k7; R_Axial_DIN0207_L6.3mm_D2.5mm_P10.16mm_Horizontal
R2234: 1k96; R_Axial_DIN0207_L6.3mm_D2.5mm_P10.16mm_Horizontal
R2236, R2237: 1k27; R_Axial_DIN0207_L6.3mm_D2.5mm_P10.16mm_Horizontal
R2238: 1M; R_Axial_DIN0309_L9.0mm_D3.2mm_P12.70mm_Horizontal
TP2201: V.Chopper; Pin_D0.9mm_L10.0mm_W2.4mm_FlatFork
TP2202: Demodulator; Pin_D0.9mm_L10.0mm_W2.4mm_FlatFork
TP2203: Chopper Ampl; Pin_D0.9mm_L10.0mm_W2.4mm_FlatFork
TP2204: Hi Out; Pin_D0.9mm_L10.0mm_W2.4mm_FlatFork
TP2205: GND6; Pin_D0.9mm_L10.0mm_W2.4mm_FlatFork
V2201: BFQ10; TO-75-6
V2202: BZX79-C4V7; D_DO-35_SOD27_P10.16mm_Horizontal
V2203, V2204: BAV45; D_DO-35_SOD27_P7.62mm_Horizontal
V2205: BSV81; TO-72-4
V2206: BC547B; TO-92_Inline
V2207, V2208: BAW62; D_DO-35_SOD27_P10.16mm_Horizontal
V2209, V2210: BZX79-C3V6; D_DO-35_SOD27_P10.16mm_Horizontal
V2211: BZX79-C5V6; D_DO-35_SOD27_P10.16mm_Horizontal
V2212: BFW13; TO-72-4
V2213, V2214: BZX79-C5V1; D_DO-35_SOD27_P12.70mm_Horizontal
V2215: BAX12A; D_DO-35_SOD27_P10.16mm_Horizontal
X2201: PM2528_RiserCardConnector

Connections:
+15V: A2201.7 (V+), A2202.7 (V+), C2213.1, R2203.1, R2205.2, R2217.3, R2221.2, R2223.2, X2201.4
-15V: A2201.4 (V-), A2202.4 (V-), C2204.2, C2298.2, R2215.2, R2217.1, R2224.1, R2230.2, V2202.2 (A), X2201.3
/HI: C2201.1, R2202.1, V2203.2 (A), V2204.1 (K), X2201.10
/HIOUT1: A2201.6, K2201.1, R2228.2, R2233.2, R2235.1, TP2204.1, V2209.2 (A), V2210.1 (K), V2213.1 (K), X2201.14
/HIOUT2: K2202.1, R2235.2, X2201.15
/LO: K2201.5, K2202.5, R2232.3, R2234.2, X2201.8
/RELHI: K2201.10, K2202.10, V2215.2 (A), X2201.18
GND3: C2202.1, C2210.2, C2216.1, C2217.1, R2212.1, R2213.1, R2222.2, X2201.9
GND4: C2212.1, JP2202.1 (A), R2201.2, R2236.2, V2212.3 (S), X2201.7
GND5: C2209.1, C2213.2, C2298.1, D2201.4 (~ASTABLE), D2201.5 (ASTABLE), D2201.6 (-TRIGGER), D2201.14 (VDD), V2211.1 (K), V2214.1 (K), X2201.1 (0V)
GND6: R2234.1, TP2205.1, X2201.11
GND7: K2201.6, K2202.6, V2215.1 (K), X2201.19
unnamed: A2201.3 (+), C2205.1, R2205.1, V2201.2 (1D)
unnamed: A2201.2 (-), R2225.2, R2228.1
unnamed: A2202.3 (+), C2217.2, L2201.2
unnamed: A2202.2 (-), R2226.2, R2227.1
unnamed: A2202.6, C2211.1, R2226.1, TP2203.1
unnamed: C2202.2, R2202.2, R2204.1
unnamed: C2203.1, R2209.2
unnamed: C2205.2, R2211.1
unnamed: C2207.2, L2201.1, R2222.1
unnamed: C2211.2, R2229.1
unnamed: C2209.2, D2201.7 (VSS), D2201.8 (+TRIGGER), D2201.9 (EXT_RESET), D2201.12 (RETRIGGER), R2230.1, V2211.2 (A)
unnamed: C2206.2, D2201.1 (C)
unnamed: C2210.1, D2201.10 (Q), R2208.2, R2227.2, V2212.2 (G)
unnamed: C2216.2, D2201.2 (R), R2220.1
unnamed: C2206.1, D2201.3 (RC_COMMON), R2216.1, R2216.2
unnamed: D2201.11 (~Q), TP2201.1, V2205.2 (G)
unnamed: JP2201.1 (A), JP2202.2 (B), R2236.1, R2237.2
unnamed: JP2201.2 (B), R2210.2, R2237.1
unnamed: R2207.2, R2214.3
unnamed: R2208.1, R2209.3
unnamed: R2209.1, R2210.1
unnamed: R2214.1, R2219.2
unnamed: R2216.3, R2220.2
unnamed: R2217.2, R2238.2
unnamed: R2232.1, R2232.2, R2233.1
unnamed: C2201.2, R2201.1, V2201.3 (1G)
unnamed: R2207.1, V2201.1 (1S)
unnamed: R2211.2, R2221.1, R2225.1, V2201.5 (2D)
unnamed: C2212.2, R2231.2, V2201.6 (2G)
unnamed: R2219.1, V2201.4 (2S)
unnamed: R2203.2, R2206.1, V2202.1 (K)
unnamed: R2212.2, V2203.1 (K), V2204.2 (A), V2207.2 (A), V2208.1 (K)
unnamed: R2213.2, R2238.1, V2205.3 (S), V2205.4 (Bulk)
unnamed: C2203.2, C2207.1, R2204.2, V2205.1 (D)
unnamed: C2204.1, R2206.2, V2206.2 (B)
unnamed: R2214.2, V2206.1 (C)
unnamed: R2215.1, V2206.3 (E)
unnamed: R2223.1, V2207.1 (K), V2209.1 (K)
unnamed: R2224.2, V2208.2 (A), V2210.2 (A)
unnamed: R2229.2, R2231.1, TP2202.1, V2212.1 (D)
unnamed: V2213.2 (A), V2214.2 (A)

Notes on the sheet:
-> Relays
-> ADC -> Currentsource.Filter (N23)
FCHOP
SPIKE
Supply zero
GAIN x10
K2201/K2202: X10 (Open) X1 (Closed)
VOFF
Chopper
-5V, 325Hz
Power
Measuring zero
Ioff

Board: 2 copper layers, 81 parts (0 on the bottom side), 53 nets, no tracks yet.

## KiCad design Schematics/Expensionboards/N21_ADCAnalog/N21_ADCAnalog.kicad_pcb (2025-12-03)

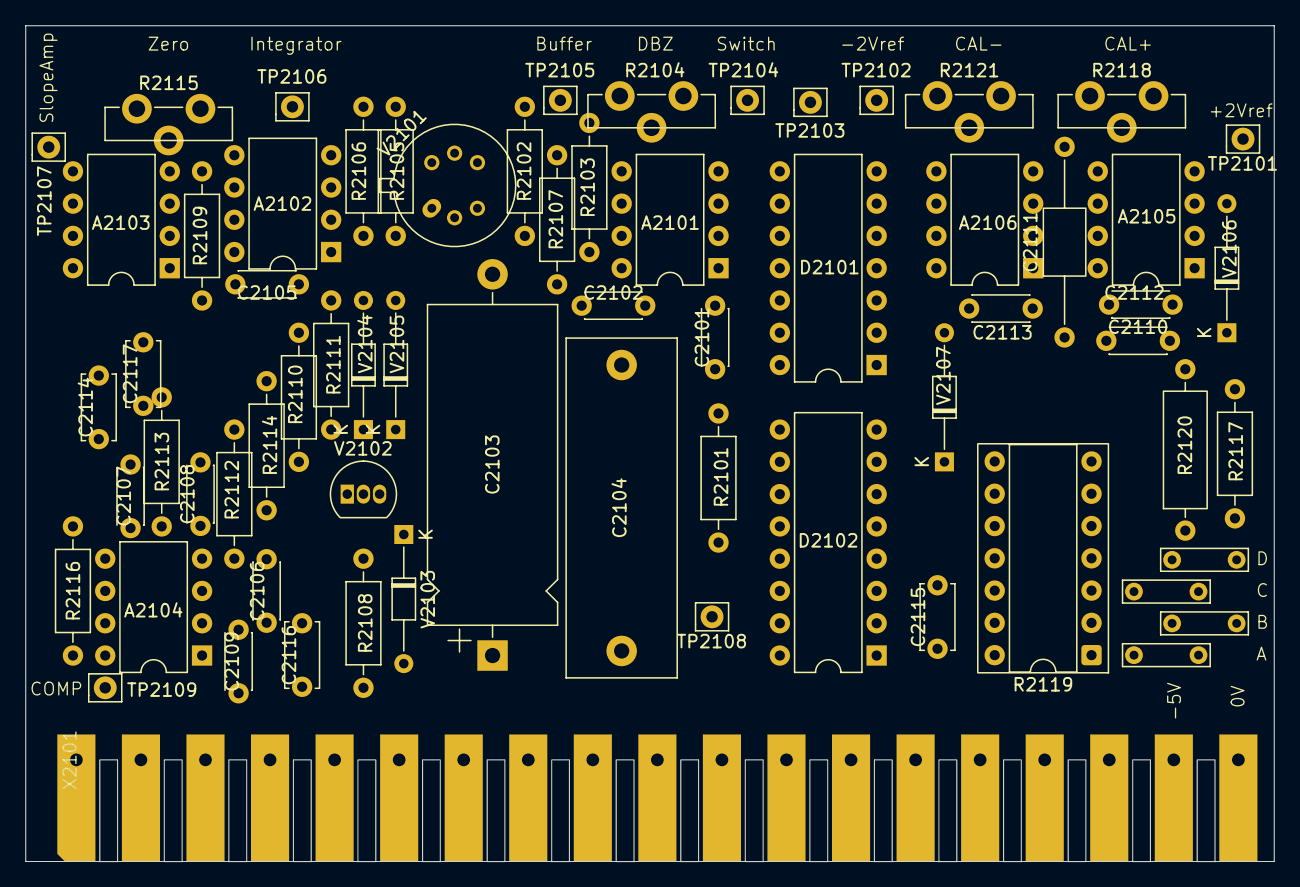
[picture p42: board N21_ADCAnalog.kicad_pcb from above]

Board: 2 copper layers, 98.2 x 65.8 mm, 67 parts (0 on the bottom side), 54 nets, no tracks yet.

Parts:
A2101: LF356H; DIP-8_W7.62mm
A2102, A2105, A2106: LM201AN; DIP-8_W7.62mm
A2103: LF355H; DIP-8_W7.62mm
A2104: LM311N; DIP-8_W7.62mm
C2101: 10n/100V; C_Disc_D4.3mm_W1.9mm_P5.00mm
C2102, C2107, C2108, C2109: 22n/63V; C_Disc_D4.3mm_W1.9mm_P5.00mm
C2103: 162n/100V; CP_Axial_L25.0mm_D10.0mm_P30.00mm_Horizontal
C2104: 3u3/100V; C_Rect_L26.5mm_W8.5mm_P22.50mm_MKS4
C2105, C2112, C2113: 33p/100V; C_Disc_D4.3mm_W1.9mm_P5.00mm
C2106: 220p/500V; C_Disc_D4.3mm_W1.9mm_P5.00mm
C2110: 4n7/100V; C_Disc_D4.3mm_W1.9mm_P5.00mm
C2111: 4n22/63V; C_Axial_L5.1mm_D3.1mm_P15.00mm_Horizontal
C2114, C2117: 6u8/25V; C_Disc_D5.0mm_W2.5mm_P5.00mm
C2115, C2116: 22u/10V; C_Disc_D5.0mm_W2.5mm_P5.00mm
D2101: HEF4066; DIP-14_W7.62mm
D2102: HEF4104; DIP-16_W7.62mm
JP2101: A; TestPoint_Bridge_Pitch5.08mm_Drill0.7mm
JP2102: B; TestPoint_Bridge_Pitch5.08mm_Drill0.7mm
JP2103: C; TestPoint_Bridge_Pitch5.08mm_Drill0.7mm
JP2104: D; TestPoint_Bridge_Pitch5.08mm_Drill0.7mm
R2101: 8k66; R_Axial_DIN0207_L6.3mm_D2.5mm_P10.16mm_Horizontal
R2102: 140k; R_Axial_DIN0207_L6.3mm_D2.5mm_P10.16mm_Horizontal
R2103: 64k9; R_Axial_DIN0207_L6.3mm_D2.5mm_P10.16mm_Horizontal
R2104: 680k; Trimmer vertical
R2105, R2106: 21M1; R_Axial_DIN0207_L6.3mm_D2.5mm_P10.16mm_Horizontal
R2107: 24k9; R_Axial_DIN0207_L6.3mm_D2.5mm_P10.16mm_Horizontal
R2108: 40k2; R_Axial_DIN0207_L6.3mm_D2.5mm_P10.16mm_Horizontal
R2109: 5k9; R_Axial_DIN0207_L6.3mm_D2.5mm_P10.16mm_Horizontal
R2110: 121k; R_Axial_DIN0207_L6.3mm_D2.5mm_P10.16mm_Horizontal
R2111: 5k90; R_Axial_DIN0207_L6.3mm_D2.5mm_P10.16mm_Horizontal
R2112, R2113: 442; R_Axial_DIN0207_L6.3mm_D2.5mm_P10.16mm_Horizontal
R2114: 442k; R_Axial_DIN0207_L6.3mm_D2.5mm_P10.16mm_Horizontal
R2115: 47k; Trimmer vertical
R2116: 1k05; R_Axial_DIN0207_L6.3mm_D2.5mm_P10.16mm_Horizontal
R2117: 8k25; R_Axial_DIN0207_L6.3mm_D2.5mm_P10.16mm_Horizontal
R2118: 33; Trimmer vertical
R2119: OM528; DIP-14_W7.62mm_Socket
R2120: 590; R_Axial_DIN0309_L9.0mm_D3.2mm_P12.70mm_Horizontal
R2121: 100; Trimmer vertical
TP2101: +2Vref; Pin_D0.9mm_L10.0mm_W2.4mm_FlatFork
TP2102: -2Vref; Pin_D0.9mm_L10.0mm_W2.4mm_FlatFork
TP2103: 0Vref; Pin_D0.9mm_L10.0mm_W2.4mm_FlatFork
TP2104: Switch; Pin_D0.9mm_L10.0mm_W2.4mm_FlatFork
TP2105: Buffer; Pin_D0.9mm_L10.0mm_W2.4mm_FlatFork
TP2106: Integrator; Pin_D0.9mm_L10.0mm_W2.4mm_FlatFork
TP2107: Slope Amp; Pin_D0.9mm_L10.0mm_W2.4mm_FlatFork
TP2108: Input; Pin_D0.9mm_L10.0mm_W2.4mm_FlatFork
TP2109: Comp; Pin_D0.9mm_L10.0mm_W2.4mm_FlatFork
V2101: TO-78-6
V2102: BSV80; TO-92_Inline
V2103, V2104, V2105, V2106: BAW62; D_DO-34_SOD68_P10.16mm_Horizontal
V2107: BZV14; D_DO-34_SOD68_P10.16mm_Horizontal
X2101: PM2528_RiserCardConnector

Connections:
+5V: C2115.1, D2102.1 (Vddo), X2101.5
+15V: A2101.7 (V+), A2102.7 (V+), A2103.7 (V+), A2104.8 (V+), A2105.7 (V+), A2106.7 (V+), C2101.2, C2107.1, C2114.1, R2107.1, R2115.1, R2117.2, X2101.4
-5V: A2104.1 (GND), C2109.2, C2116.2, D2101.7 (VSS), D2102.8 (Vss), X2101.2 (-5V)
-15V: A2101.4 (V-), A2102.4 (V-), A2103.4 (V-), A2104.4 (V-), A2105.4 (V-), A2106.4 (V-), C2102.2, C2108.2, C2117.2, R2105.2, R2106.2, R2115.3, X2101.3
/+2VRef: C2110.2, D2101.11, R2117.1, R2118.2, R2118.3, R2119.8, TP2101.1, V2106.1 (K), X2101.7
/AZ: D2102.5, X2101.12
/COMP: A2104.7, R2116.2, TP2109.1, X2101.19
/DN+: D2102.12, X2101.13
/DN-: D2102.4, X2101.11
/INPUT: R2101.1, TP2108.1, X2101.9
/UP: D2102.11, X2101.14
/xAZ: D2101.5, D2102.6, V2103.1 (K)
/xDN+: D2101.12, D2102.13
/xDN-: D2101.6, D2102.3
/xUP: D2101.13, D2102.10
GND3: A2103.3 (+), C2104.2, C2110.1, C2111.2, D2101.4, D2102.15 (EN), D2102.16 (Vddi), R2113.2, R2119.10, TP2103.1, X2101.6, X2101.8, X2101.10
GND4: C2101.1, C2102.1, C2107.2, C2108.1, C2109.1, C2114.2, C2115.2, C2116.1, C2117.1, D2101.14 (VDD), R2108.2, R2116.1, V2104.1 (K), V2105.2 (A), X2101.1 (0V), X2101.18
unnamed: A2101.3 (+), D2101.2, D2101.3, D2101.9, D2101.10, TP2104.1
unnamed: A2101.2 (-), A2101.6, R2102.2, R2103.2, TP2105.1
unnamed: A2102.3 (+), R2106.1, V2101.4 (2S)
unnamed: A2102.2 (-), R2105.1, V2101.1 (1S)
unnamed: A2102.1 (BAL), C2105.1
unnamed: A2102.8 (C/B), C2105.2
unnamed: A2102.6, C2103.1, R2109.1, TP2106.1
unnamed: A2103.2 (-), R2109.2, R2110.1
unnamed: A2103.6, R2110.2, R2111.2, R2112.1, TP2107.1
unnamed: A2104.2 (+), C2106.2, R2104.1, R2104.2, R2113.1, R2114.1
unnamed: A2104.3 (-), C2106.1, R2112.2
unnamed: A2104.5 (BAL), A2104.6 (STRB)
unnamed: A2105.3 (+), R2119.6
unnamed: A2105.2 (-), A2106.2 (-), R2119.4
unnamed: A2105.1 (LOGIC_REFERENCE), C2112.2
unnamed: A2105.8 (~DISABLE), C2112.1
unnamed: A2106.3 (+), R2119.9
unnamed: A2106.1 (LOGIC_REFERENCE), C2113.2
unnamed: A2106.8 (~DISABLE), C2113.1
unnamed: C2111.1, D2101.8, R2119.12, TP2102.1
unnamed: D2101.1, R2101.2
unnamed: JP2101.1 (A), JP2102.1 (A), R2119.14
unnamed: R2119.1, R2120.1
unnamed: JP2103.1 (A), R2119.2
unnamed: JP2104.1 (A), R2119.11
unnamed: R2118.1, R2119.5
unnamed: R2103.1, R2104.3
unnamed: R2114.2, R2115.2
unnamed: R2120.2, R2121.3
unnamed: R2107.2, V2101.2 (1D), V2101.5 (2D)
unnamed: C2103.2, R2102.1, V2101.3 (1G)
unnamed: C2104.1, V2101.6 (2G), V2102.3 (S)
unnamed: R2111.1, V2102.1 (D), V2104.2 (A), V2105.1 (K)
unnamed: R2108.1, V2102.2 (G), V2103.2 (A)
unnamed: A2105.6, V2106.2 (A)
unnamed: A2106.6, R2121.1, R2121.2, V2107.2 (A)
unnamed: R2119.7, V2107.1 (K)

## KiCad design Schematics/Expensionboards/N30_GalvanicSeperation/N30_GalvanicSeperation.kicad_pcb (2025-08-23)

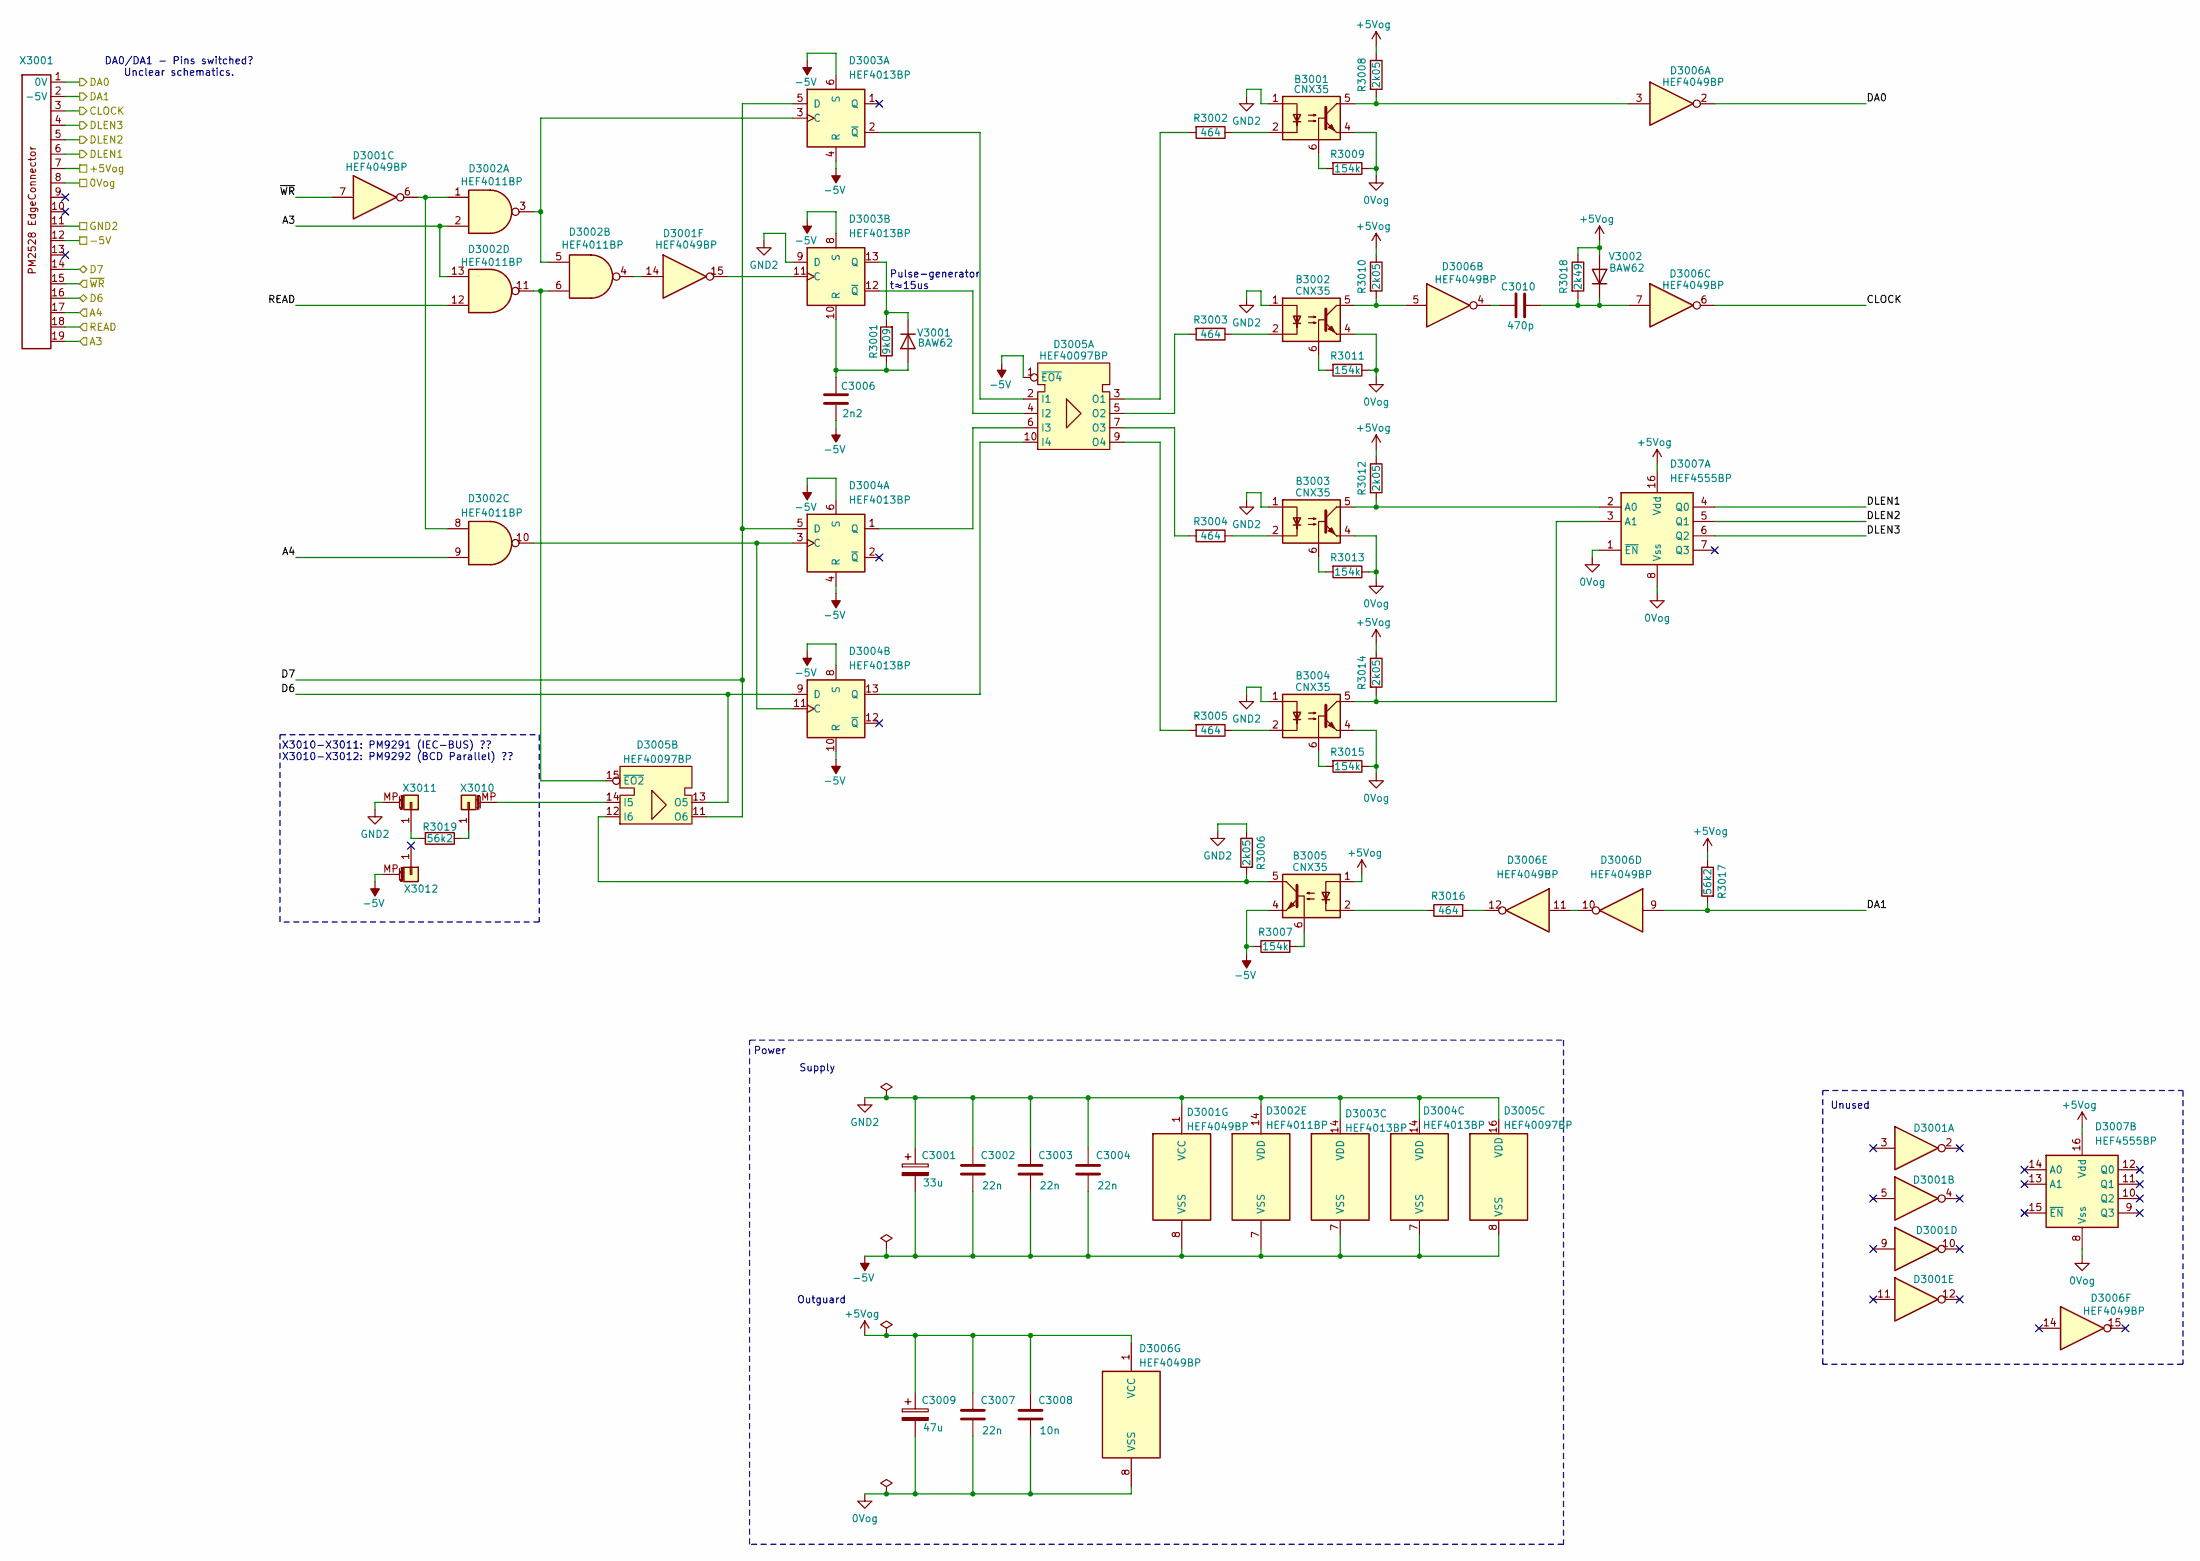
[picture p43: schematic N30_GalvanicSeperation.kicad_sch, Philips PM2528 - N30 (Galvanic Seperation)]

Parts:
B3001, B3002, B3003, B3004, B3005: CNX35; DIP-6_W7.62mm
C3001: 33u; CP_Radial_Tantal_D7.0mm_P5.00mm
C3002, C3003, C3004, C3007: 22n; C_Axial_L5.1mm_D3.1mm_P10.00mm_Horizontal
C3006: 2n2; C_Axial_L5.1mm_D3.1mm_P10.00mm_Horizontal
C3008: 10n; C_Axial_L5.1mm_D3.1mm_P10.00mm_Horizontal
C3009: 47u; CP_Axial_L10.0mm_D6.0mm_P15.00mm_Horizontal
C3010: 470p; C_Axial_L5.1mm_D3.1mm_P10.00mm_Horizontal
D3001, D3006: HEF4049BP; DIP-16_W7.62mm
D3002: HEF4011BP; DIP-14_W7.62mm
D3003, D3004: HEF4013BP; DIP-14_W7.62mm
D3005: HEF40097BP; DIP-16_W7.62mm
D3007: HEF4555BP; DIP-16_W7.62mm
R3001: 9k09; R_Axial_DIN0207_L6.3mm_D2.5mm_P10.16mm_Horizontal
R3002, R3003, R3004, R3005, R3016: 464; R_Axial_DIN0207_L6.3mm_D2.5mm_P10.16mm_Horizontal
R3006, R3008, R3010, R3012, R3014: 2k05; R_Axial_DIN0207_L6.3mm_D2.5mm_P10.16mm_Horizontal
R3007, R3009, R3011, R3013, R3015: 154k; R_Axial_DIN0207_L6.3mm_D2.5mm_P10.16mm_Horizontal
R3017, R3019: 56k2; R_Axial_DIN0207_L6.3mm_D2.5mm_P10.16mm_Horizontal
R3018: 2k49; R_Axial_DIN0207_L6.3mm_D2.5mm_P10.16mm_Horizontal
V3001, V3002: BAW62; D_DO-35_SOD27_P7.62mm_Horizontal
X3001: PM2528_RiserCardConnector
X3010, X3011, X3012: Conn_01x01_MountingPin; Pin_D1.1mm_L8.5mm_W2.5mm_FlatFork

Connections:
0Vog: B3001.4, B3002.4, B3003.4, B3004.4, C3007.2, C3008.2, C3009.2, D3006.8 (VSS), D3007.1 (~EN), D3007.8 (Vss), R3009.1, R3011.1, R3013.1, R3015.1, X3001.8
+5Vog: B3005.1, C3007.1, C3008.1, C3009.1, D3006.1 (VCC), D3007.16 (Vdd), R3008.1, R3010.1, R3012.1, R3014.1, R3017.1, R3018.1, V3002.2 (A), X3001.7
-5V: B3005.4, C3001.2, C3002.2, C3003.2, C3004.2, C3006.2, D3001.8 (VSS), D3002.7 (VSS), D3003.4 (R), D3003.6 (S), D3003.7 (VSS), D3003.8 (S), D3004.4 (R), D3004.6 (S), D3004.7 (VSS), D3004.8 (S), D3004.10 (R), D3005.1 (~EO4), D3005.8 (VSS), R3007.1, X3001.12, X3012.MP (MountPin)
/A3: D3002.2, D3002.13, X3001.19
/A4: D3002.9, X3001.17
/CLOCK: D3006.6, X3001.3
/D6: D3004.9 (D), D3005.13 (O5), X3001.16
/D7: D3003.5 (D), D3004.5 (D), D3005.11 (O6), X3001.14
/DA0: D3006.2, X3001.1 (0V)
/DA1: D3006.9, R3017.2, X3001.2 (-5V)
/DLEN1: D3007.4 (Q0), X3001.6
/DLEN2: D3007.5 (Q1), X3001.5
/DLEN3: D3007.6 (Q2), X3001.4
/READ: D3002.12, X3001.18
/~WR: D3001.7, X3001.15
GND2: B3001.1, B3002.1, B3003.1, B3004.1, C3001.1, C3002.1, C3003.1, C3004.1, D3001.1 (VCC), D3002.14 (VDD), D3003.9 (D), D3003.14 (VDD), D3004.14 (VDD), D3005.16 (VDD), R3006.1, X3001.11, X3011.MP (MountPin)
unnamed: B3001.2, R3002.1
unnamed: B3001.5, D3006.3, R3008.2
unnamed: B3001.6, R3009.2
unnamed: B3002.2, R3003.1
unnamed: B3002.5, D3006.5, R3010.2
unnamed: B3002.6, R3011.2
unnamed: B3003.2, R3004.1
unnamed: B3003.6, R3013.2
unnamed: B3004.2, R3005.1
unnamed: B3004.6, R3015.2
unnamed: B3005.2, R3016.1
unnamed: B3005.6, R3007.2
unnamed: C3010.1, D3006.4
unnamed: D3001.6, D3002.1, D3002.8
unnamed: D3001.14, D3002.4
unnamed: D3002.3, D3002.5, D3003.3 (C)
unnamed: D3003.2 (~Q), D3005.2 (I1)
unnamed: D3001.15, D3003.11 (C)
unnamed: D3003.13 (Q), R3001.2, V3001.1 (K)
unnamed: C3006.1, D3003.10 (R), R3001.1, V3001.2 (A)
unnamed: D3003.12 (~Q), D3005.4 (I2)
unnamed: D3002.10, D3004.3 (C), D3004.11 (C)
unnamed: D3004.1 (Q), D3005.6 (I3)
unnamed: D3004.13 (Q), D3005.10 (I4)
unnamed: D3005.3 (O1), R3002.2
unnamed: D3005.5 (O2), R3003.2
unnamed: D3005.7 (O3), R3004.2
unnamed: D3005.9 (O4), R3005.2
unnamed: D3005.14 (I5), X3010.MP (MountPin)
unnamed: B3005.5, D3005.12 (I6), R3006.2
unnamed: D3002.6, D3002.11, D3005.15 (~EO2)
unnamed: D3006.10, D3006.11
unnamed: D3006.12, R3016.2
unnamed: B3003.5, D3007.2 (A0), R3012.2
unnamed: B3004.5, D3007.3 (A1), R3014.2
unnamed: C3010.2, D3006.7, R3018.2, V3002.1 (K)
unnamed: R3019.1, X3010.1
unnamed: R3019.2, X3011.1

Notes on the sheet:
Unused
Outguard
Supply
Pulse-generator t≈15us
X3010-X3011: PM9291 (IEC-BUS) ?? X3010-X3012: PM9292 (BCD Parallel) ??
DA0/DA1 - Pins switched? Unclear schematics.
Power

Board: 2 copper layers, 46 parts (0 on the bottom side), 53 nets, no tracks yet.

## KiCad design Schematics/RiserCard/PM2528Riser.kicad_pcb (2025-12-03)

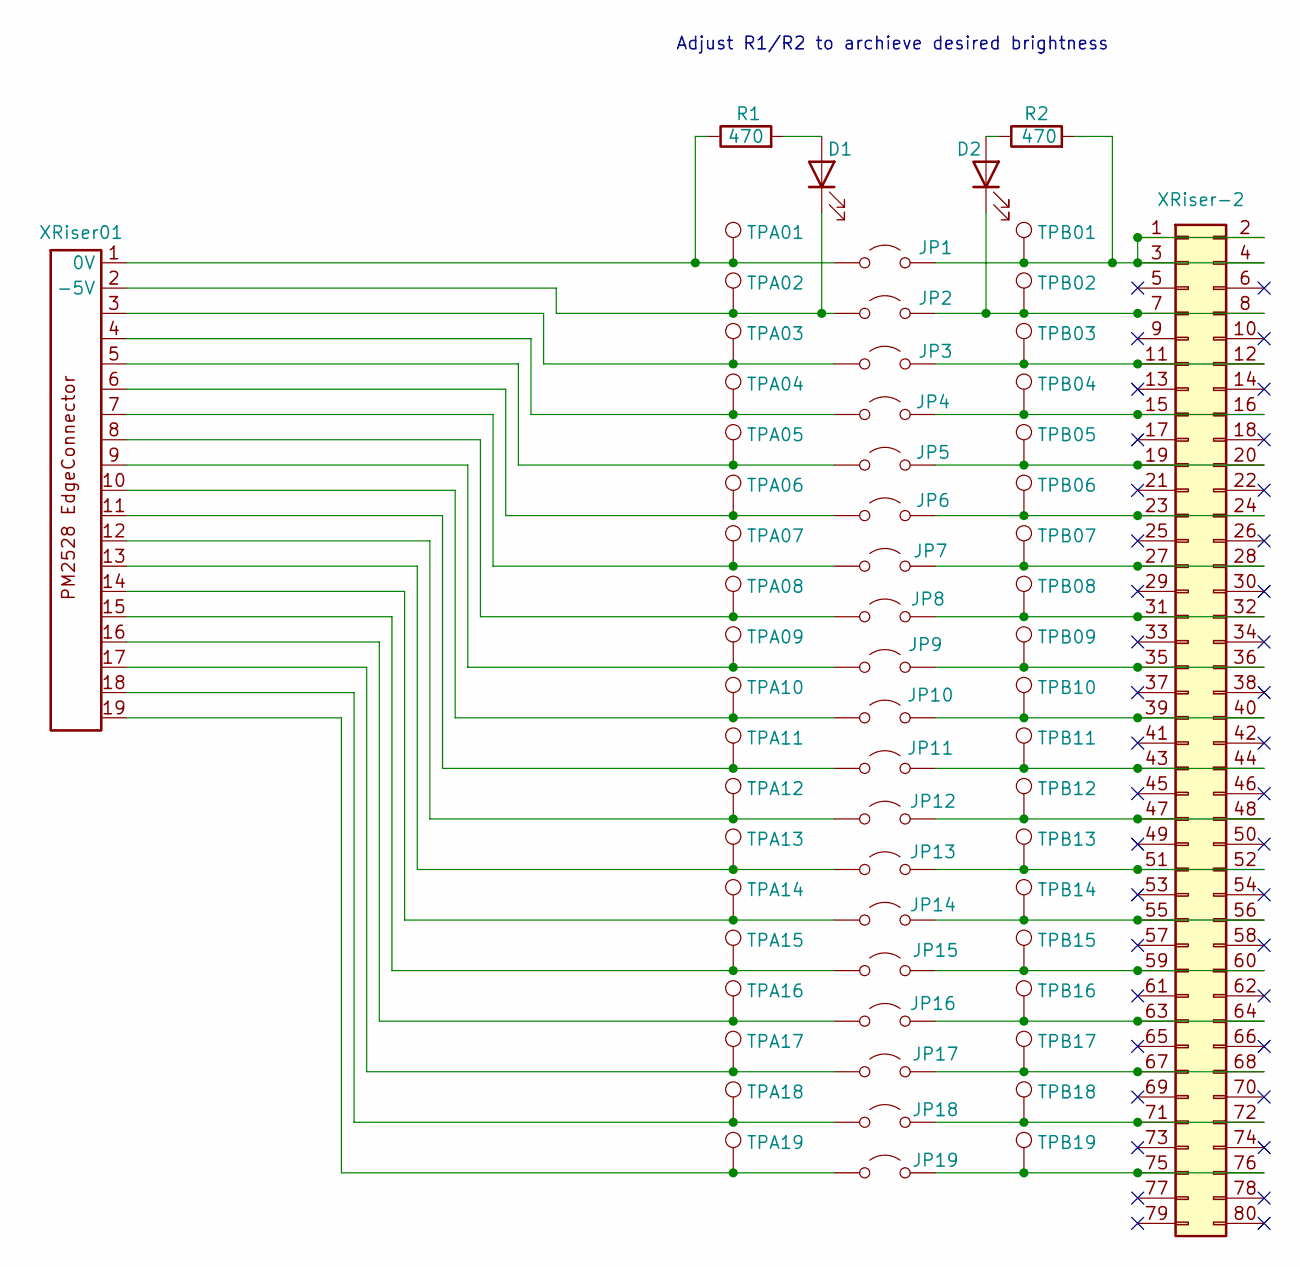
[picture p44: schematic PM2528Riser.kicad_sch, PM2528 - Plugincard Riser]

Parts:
D1, D2: LED; LED_0805_2012Metric
JP1, JP2, JP3, JP4, JP5, JP6, JP7, JP8, JP9, JP10, JP11, JP12, JP13, JP14, JP15, JP16, JP17, JP18, JP19: Jumper_2_Open; PinHeader_1x02_P2.54mm_Vertical
R1, R2: 470; R_0805_2012Metric_Pad1.20x1.40mm_HandSolder
TPA01, TPA02, TPA03, TPA04, TPA05, TPA06, TPA07, TPA08, TPA09, TPA10, TPA11, TPA12, TPA13, TPA14, TPA15, TPA16, TPA17, TPA18, TPA19: TestPoint; Pin_D1.0mm_L10.0mm
TPB01, TPB02, TPB03, TPB04, TPB05, TPB06, TPB07, TPB08, TPB09, TPB10, TPB11, TPB12, TPB13, TPB14, TPB15, TPB16, TPB17, TPB18, TPB19: TestPoint; TestPoint_Loop_D1.80mm_Drill1.0mm_Beaded
XRiser01: PM2528_RiserCardConnector
XRiser-2: Conn_02x40_Odd_Even; CONN EDGE DUAL FMALE 80POS 0.100

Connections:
unnamed: D1.2 (A), R1.2
unnamed: D1.1 (K), JP2.1 (A), TPA02.1, XRiser01.2 (-5V)
unnamed: D2.2 (A), R2.1
unnamed: D2.1 (K), JP2.2 (B), TPB02.1, XRiser-2.7, XRiser-2.8
unnamed: JP1.1 (A), R1.1, TPA01.1, XRiser01.1 (0V)
unnamed: JP1.2 (B), R2.2, TPB01.1, XRiser-2.1, XRiser-2.2, XRiser-2.3, XRiser-2.4
unnamed: JP3.1 (A), TPA03.1, XRiser01.3
unnamed: JP3.2 (B), TPB03.1, XRiser-2.11, XRiser-2.12
unnamed: JP4.1 (A), TPA04.1, XRiser01.4
unnamed: JP4.2 (B), TPB04.1, XRiser-2.15, XRiser-2.16
unnamed: JP5.1 (A), TPA05.1, XRiser01.5
unnamed: JP5.2 (B), TPB05.1, XRiser-2.19, XRiser-2.20
unnamed: JP6.1 (A), TPA06.1, XRiser01.6
unnamed: JP6.2 (B), TPB06.1, XRiser-2.23, XRiser-2.24
unnamed: JP7.1 (A), TPA07.1, XRiser01.7
unnamed: JP7.2 (B), TPB07.1, XRiser-2.27, XRiser-2.28
unnamed: JP8.1 (A), TPA08.1, XRiser01.8
unnamed: JP8.2 (B), TPB08.1, XRiser-2.31, XRiser-2.32
unnamed: JP9.1 (A), TPA09.1, XRiser01.9
unnamed: JP9.2 (B), TPB09.1, XRiser-2.35, XRiser-2.36
unnamed: JP10.1 (A), TPA10.1, XRiser01.10
unnamed: JP10.2 (B), TPB10.1, XRiser-2.39, XRiser-2.40
unnamed: JP11.1 (A), TPA11.1, XRiser01.11
unnamed: JP11.2 (B), TPB11.1, XRiser-2.43, XRiser-2.44
unnamed: JP12.1 (A), TPA12.1, XRiser01.12
unnamed: JP12.2 (B), TPB12.1, XRiser-2.47, XRiser-2.48
unnamed: JP13.1 (A), TPA13.1, XRiser01.13
unnamed: JP13.2 (B), TPB13.1, XRiser-2.51, XRiser-2.52
unnamed: JP14.1 (A), TPA14.1, XRiser01.14
unnamed: JP14.2 (B), TPB14.1, XRiser-2.55, XRiser-2.56
unnamed: JP15.1 (A), TPA15.1, XRiser01.15
unnamed: JP15.2 (B), TPB15.1, XRiser-2.59, XRiser-2.60
unnamed: JP16.1 (A), TPA16.1, XRiser01.16
unnamed: JP16.2 (B), TPB16.1, XRiser-2.63, XRiser-2.64
unnamed: JP17.1 (A), TPA17.1, XRiser01.17
unnamed: JP17.2 (B), TPB17.1, XRiser-2.67, XRiser-2.68
unnamed: JP18.1 (A), TPA18.1, XRiser01.18
unnamed: JP18.2 (B), TPB18.1, XRiser-2.71, XRiser-2.72
unnamed: JP19.1 (A), TPA19.1, XRiser01.19
unnamed: JP19.2 (B), TPB19.1, XRiser-2.75, XRiser-2.76

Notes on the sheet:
Adjust R1/R2 to archieve desired brightness

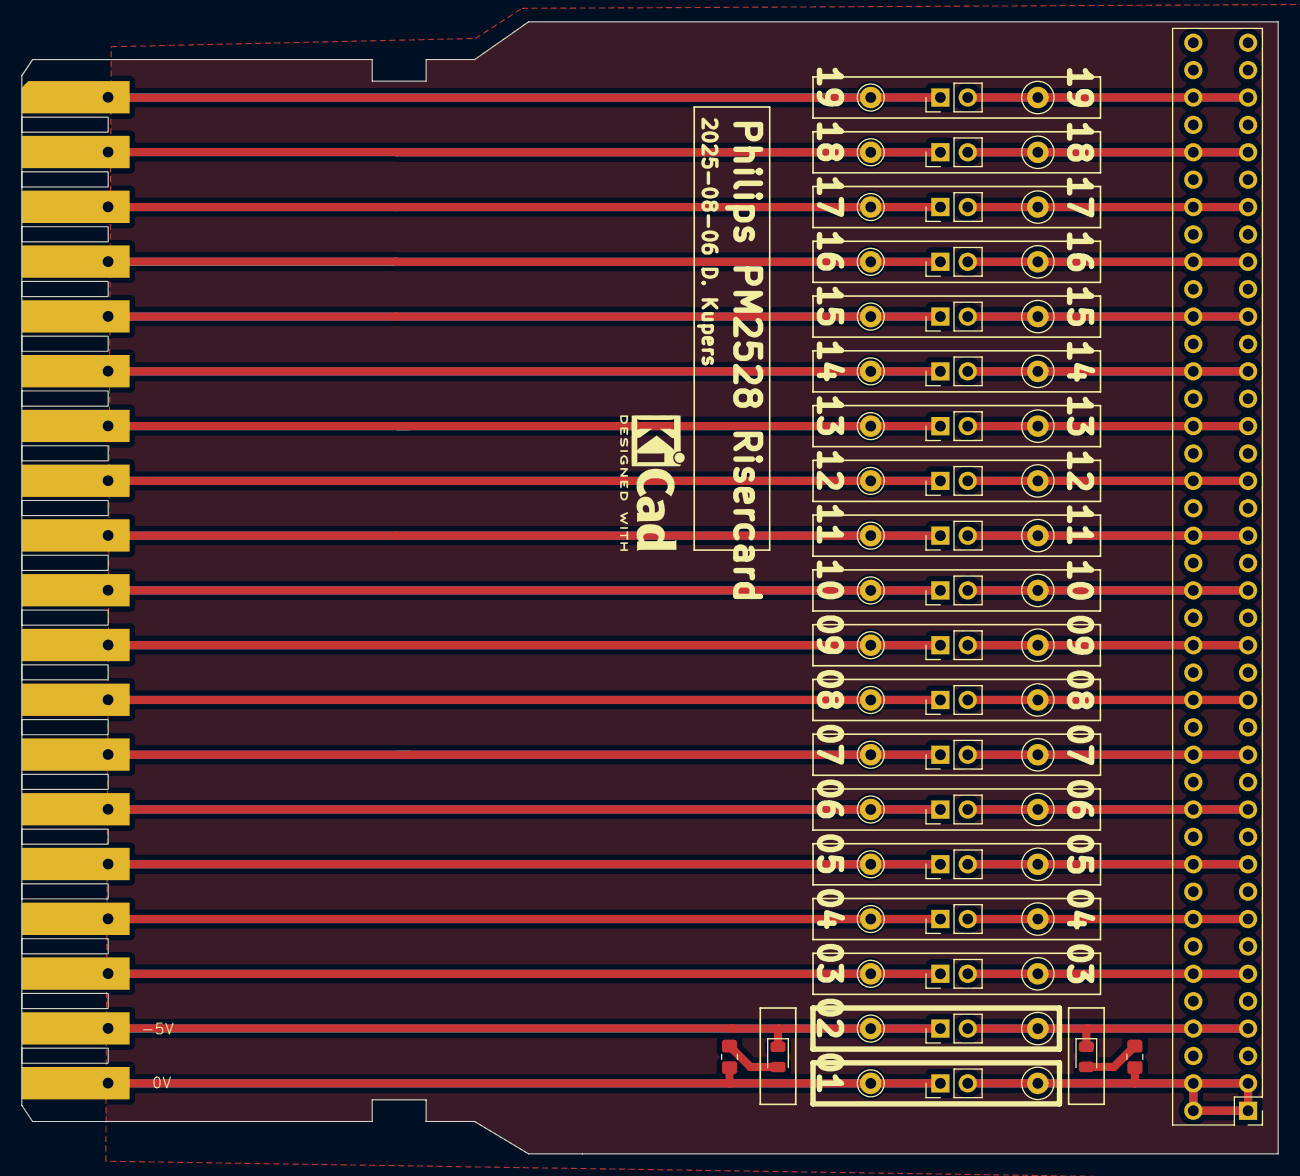
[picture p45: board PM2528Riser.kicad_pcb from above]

Board: 2 copper layers, 116.5 x 105.0 mm, 63 parts (0 on the bottom side), 40 nets.

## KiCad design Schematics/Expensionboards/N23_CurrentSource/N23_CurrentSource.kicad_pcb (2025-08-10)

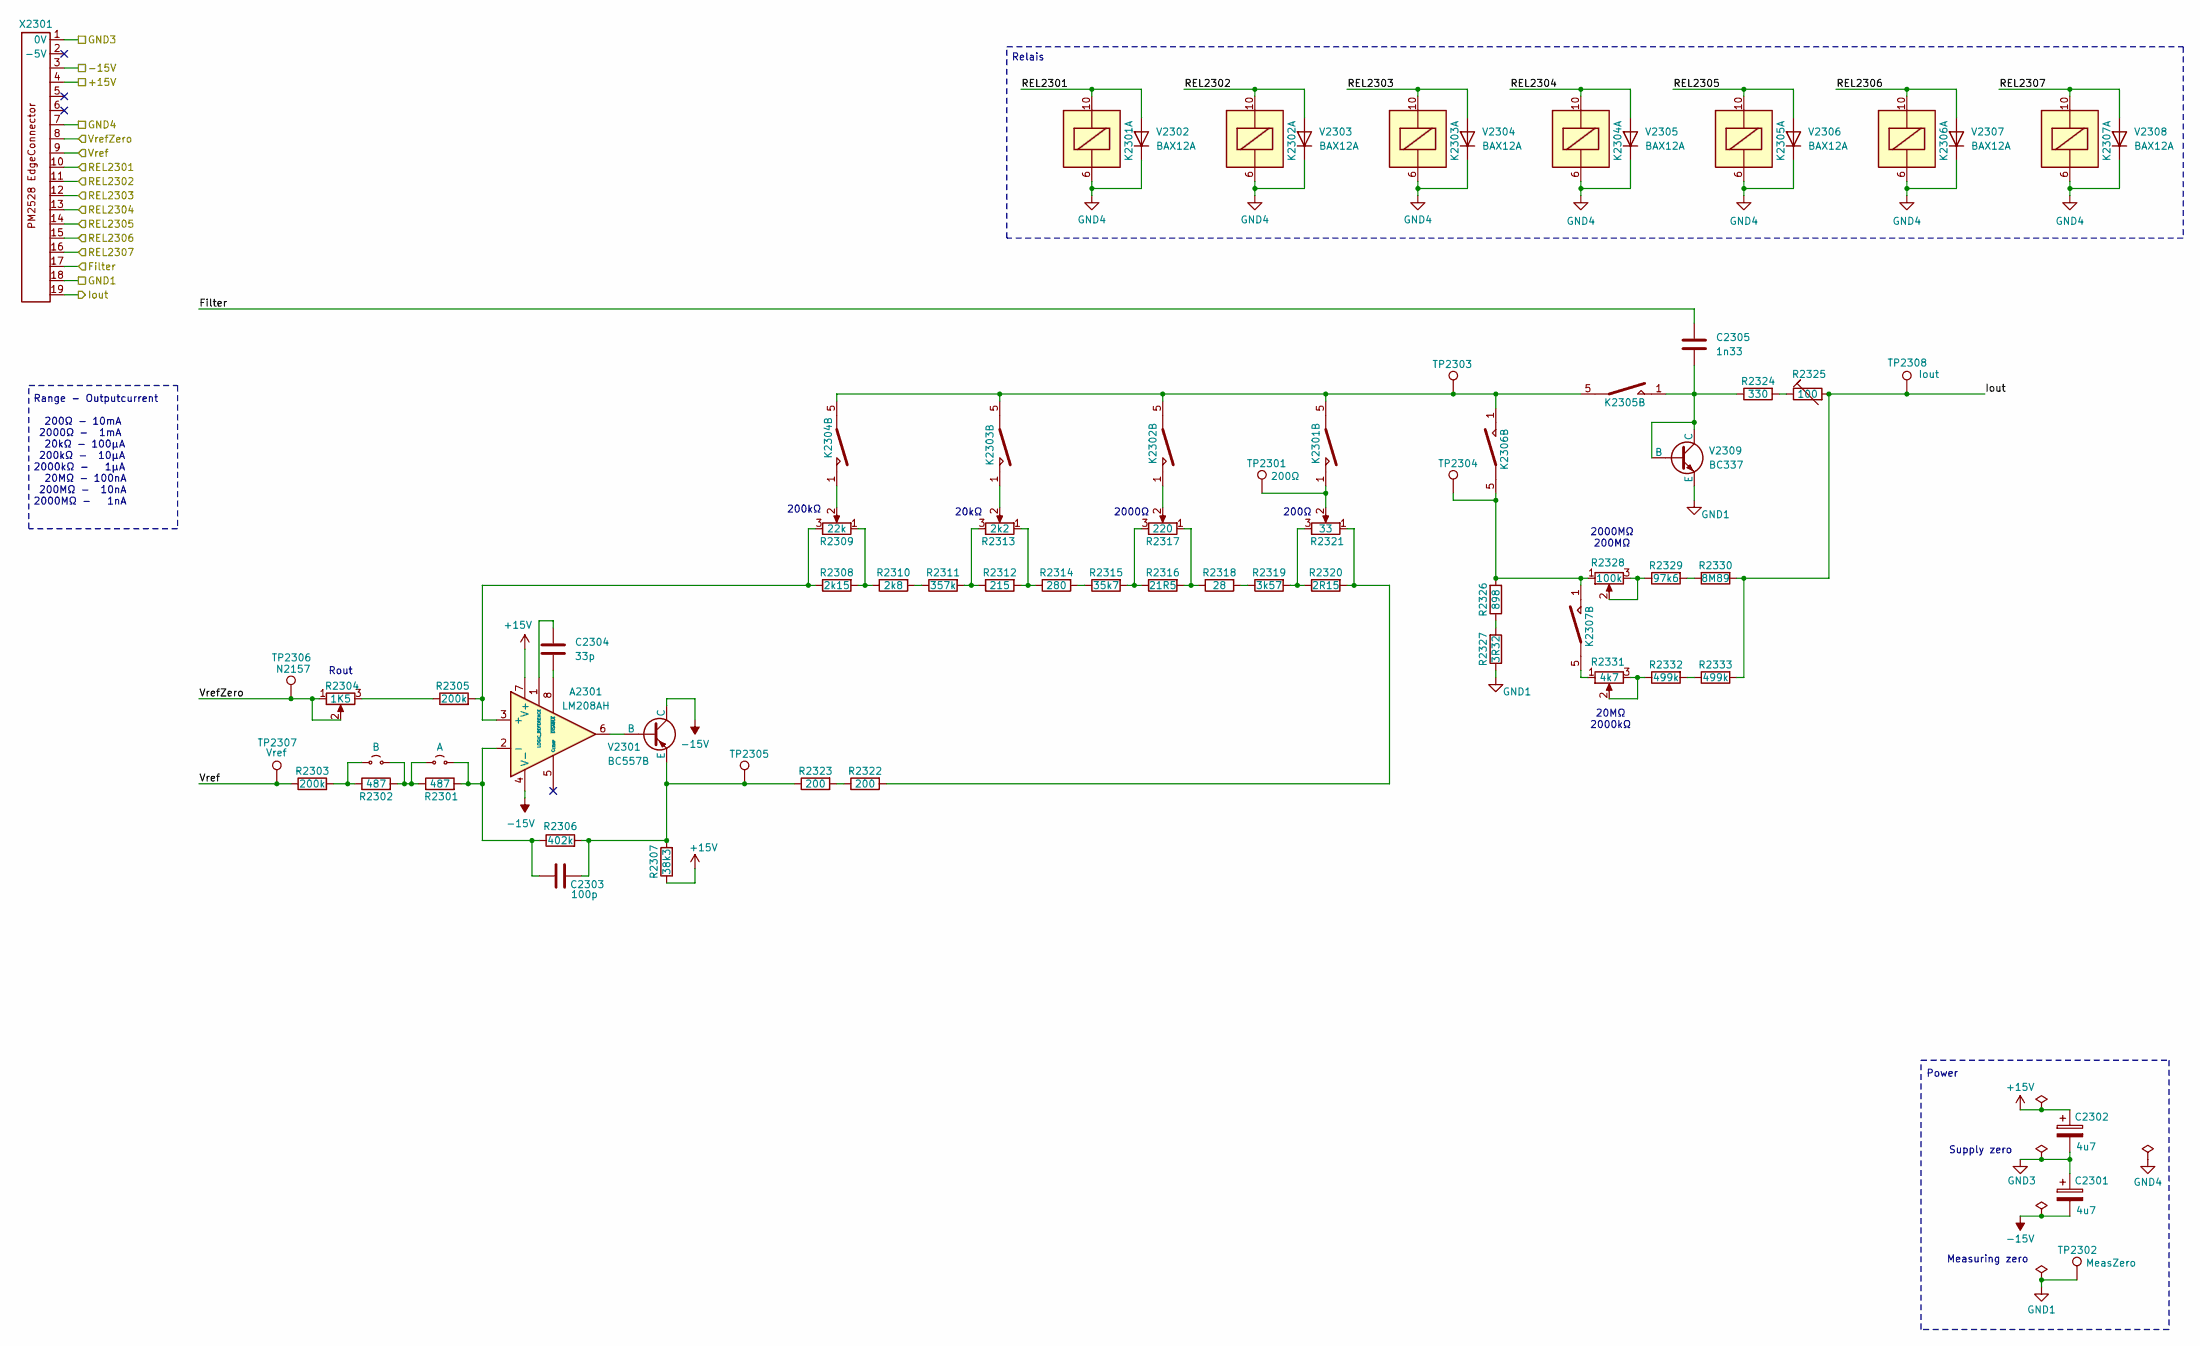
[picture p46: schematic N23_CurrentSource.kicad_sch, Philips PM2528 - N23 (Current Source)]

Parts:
A2301: LM208AH; TO-99-8
C2301, C2302: 4u7; CP_Radial_Tantal_D4.5mm_P5.00mm
C2303: 100p; C_Disc_D4.3mm_W1.9mm_P5.00mm
C2304: 33p; C_Disc_D4.3mm_W1.9mm_P5.00mm
C2305: 1n33; C_Axial_L5.1mm_D3.1mm_P15.00mm_Horizontal
JP2301: B; TestPoint_Bridge_Pitch5.08mm_Drill0.7mm
JP2302: A; TestPoint_Bridge_Pitch5.08mm_Drill0.7mm
K2301, K2302, K2303, K2304, K2305, K2306, K2307: Reed relay assy
R2301: 487; R_Axial_DIN0309_L9.0mm_D3.2mm_P12.70mm_Horizontal
R2302: 487; R_Axial_DIN0207_L6.3mm_D2.5mm_P10.16mm_Horizontal
R2303: 200k; R_Axial_DIN0207_L6.3mm_D2.5mm_P10.16mm_Horizontal
R2304: 1K5; Trimmer vertical
R2305: 200k; R_Axial_DIN0309_L9.0mm_D3.2mm_P12.70mm_Horizontal
R2306: 402k; R_Axial_DIN0309_L9.0mm_D3.2mm_P12.70mm_Horizontal
R2307: 38k3; R_Axial_DIN0207_L6.3mm_D2.5mm_P10.16mm_Horizontal
R2308: 2k15; R_Axial_DIN0207_L6.3mm_D2.5mm_P10.16mm_Horizontal
R2309: 22k; Trimmer vertical
R2310: 2k8; R_Axial_DIN0207_L6.3mm_D2.5mm_P10.16mm_Horizontal
R2311: 357k; R_Axial_DIN0309_L9.0mm_D3.2mm_P12.70mm_Horizontal
R2312: 215; R_Axial_DIN0207_L6.3mm_D2.5mm_P10.16mm_Horizontal
R2313: 2k2; Trimmer vertical
R2314: 280; R_Axial_DIN0207_L6.3mm_D2.5mm_P10.16mm_Horizontal
R2315: 35k7; R_Axial_DIN0207_L6.3mm_D2.5mm_P10.16mm_Horizontal
R2316: 21R5; R_Axial_DIN0207_L6.3mm_D2.5mm_P10.16mm_Horizontal
R2317: 220; Trimmer vertical
R2318: 28; R_Axial_DIN0207_L6.3mm_D2.5mm_P10.16mm_Horizontal
R2319: 3k57; R_Axial_DIN0207_L6.3mm_D2.5mm_P10.16mm_Horizontal
R2320: 2R15; R_Axial_DIN0207_L6.3mm_D2.5mm_P10.16mm_Horizontal
R2321: 33; Trimmer vertical
R2322, R2323: 200; R_Axial_DIN0309_L9.0mm_D3.2mm_P12.70mm_Horizontal
R2324: 330; R_Axial_DIN0614_L14.3mm_D5.7mm_P25.40mm_Horizontal
R2325: 100; RV_Disc_D7mm_W3.9mm_P5mm
R2326: 898; R_Axial_DIN0207_L6.3mm_D2.5mm_P10.16mm_Horizontal
R2327: 3R32; R_Axial_DIN0207_L6.3mm_D2.5mm_P10.16mm_Horizontal
R2328: 100k; Trimmer vertical
R2329: 97k6; R_Axial_DIN0207_L6.3mm_D2.5mm_P10.16mm_Horizontal
R2330: 8M89; R_Axial_DIN0411_L9.9mm_D3.6mm_P15.24mm_Horizontal
R2331: 4k7; Trimmer vertical
R2332, R2333: 499k; R_Axial_DIN0309_L9.0mm_D3.2mm_P12.70mm_Horizontal
TP2301: 200Ω; Pin_D0.9mm_L10.0mm_W2.4mm_FlatFork
TP2302: MeasZero; Pin_D0.9mm_L10.0mm_W2.4mm_FlatFork
TP2303, TP2304, TP2305: Pin_D0.9mm_L10.0mm_W2.4mm_FlatFork
TP2306: N2157; Pin_D0.9mm_L10.0mm_W2.4mm_FlatFork
TP2307: Vref; Pin_D0.9mm_L10.0mm_W2.4mm_FlatFork
TP2308: Iout; Pin_D0.9mm_L10.0mm_W2.4mm_FlatFork
V2301: BC557B; TO-92
V2302, V2303, V2304, V2305, V2306, V2307, V2308: BAX12A; D_DO-41_SOD81_P10.16mm_Horizontal
V2309: BC337; TO-92
X2301: PM2528_RiserCardConnector

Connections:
+15V: A2301.7 (V+), C2302.1, R2307.1, X2301.4
-15V: A2301.4 (V-), C2301.2, V2301.1 (C), X2301.3
/Filter: C2305.2, X2301.17
/Iout: R2325.2, R2330.2, R2333.2, TP2308.1, X2301.19
/REL2301: K2301.10, V2302.2 (A), X2301.10
/REL2302: K2302.10, V2303.2 (A), X2301.11
/REL2303: K2303.10, V2304.2 (A), X2301.12
/REL2304: K2304.10, V2305.2 (A), X2301.13
/REL2305: K2305.10, V2306.2 (A), X2301.14
/REL2306: K2306.10, V2307.2 (A), X2301.15
/REL2307: K2307.10, V2308.2 (A), X2301.16
/Vref: R2303.1, TP2307.1, X2301.9
/VrefZero: R2304.1, R2304.2, TP2306.1, X2301.8
GND1: R2327.1, TP2302.1, V2309.3 (E), X2301.18
GND3: C2301.1, C2302.2, X2301.1 (0V)
GND4: K2301.6, K2302.6, K2303.6, K2304.6, K2305.6, K2306.6, K2307.6, V2302.1 (K), V2303.1 (K), V2304.1 (K), V2305.1 (K), V2306.1 (K), V2307.1 (K), V2308.1 (K), X2301.7
unnamed: A2301.3 (+), R2305.2, R2308.1, R2309.3
unnamed: A2301.2 (-), C2303.2, JP2302.2 (B), R2301.2, R2306.1
unnamed: A2301.1 (LOGIC_REFERENCE), C2304.1
unnamed: A2301.8 (~DISABLE), C2304.2
unnamed: JP2301.1 (A), R2302.1, R2303.2
unnamed: JP2301.2 (B), JP2302.1 (A), R2301.1, R2302.2
unnamed: K2301.1, R2321.2, TP2301.1
unnamed: K2301.5, K2302.5, K2303.5, K2304.5, K2305.5, K2306.1, TP2303.1
unnamed: K2302.1, R2317.2
unnamed: K2303.1, R2313.2
unnamed: K2304.1, R2309.2
unnamed: K2306.5, K2307.1, R2326.2, R2328.1, TP2304.1
unnamed: K2307.5, R2331.1
unnamed: R2304.3, R2305.1
unnamed: R2308.2, R2309.1, R2310.1
unnamed: R2310.2, R2311.1
unnamed: R2311.2, R2312.1, R2313.3
unnamed: R2312.2, R2313.1, R2314.1
unnamed: R2314.2, R2315.1
unnamed: R2315.2, R2316.1, R2317.3
unnamed: R2316.2, R2317.1, R2318.1
unnamed: R2318.2, R2319.1
unnamed: R2319.2, R2320.1, R2321.3
unnamed: R2320.2, R2321.1, R2322.2
unnamed: R2322.1, R2323.2
unnamed: R2324.2, R2325.1
unnamed: R2326.1, R2327.2
unnamed: R2328.2, R2328.3, R2329.1
unnamed: R2329.2, R2330.1
unnamed: R2331.2, R2331.3, R2332.1
unnamed: R2332.2, R2333.1
unnamed: A2301.6, V2301.2 (B)
unnamed: C2303.1, R2306.2, R2307.2, R2323.1, TP2305.1, V2301.3 (E)
unnamed: C2305.1, K2305.1, R2324.1, V2309.1 (C), V2309.2 (B)

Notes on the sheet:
200Ω
Power
Measuring zero
20kΩ
2000MΩ 200MΩ
200kΩ
20MΩ 2000kΩ
Relais
2000Ω
Rout
Range - Outputcurrent 200Ω - 10mA 2000Ω - 1mA 20kΩ - 100µA 200kΩ - 10µA 2000kΩ - 1µA 20MΩ - 100nA 200MΩ - 10nA 2000MΩ - 1nA
Supply zero

Board: 2 copper layers, 66 parts (0 on the bottom side), 50 nets, no tracks yet.

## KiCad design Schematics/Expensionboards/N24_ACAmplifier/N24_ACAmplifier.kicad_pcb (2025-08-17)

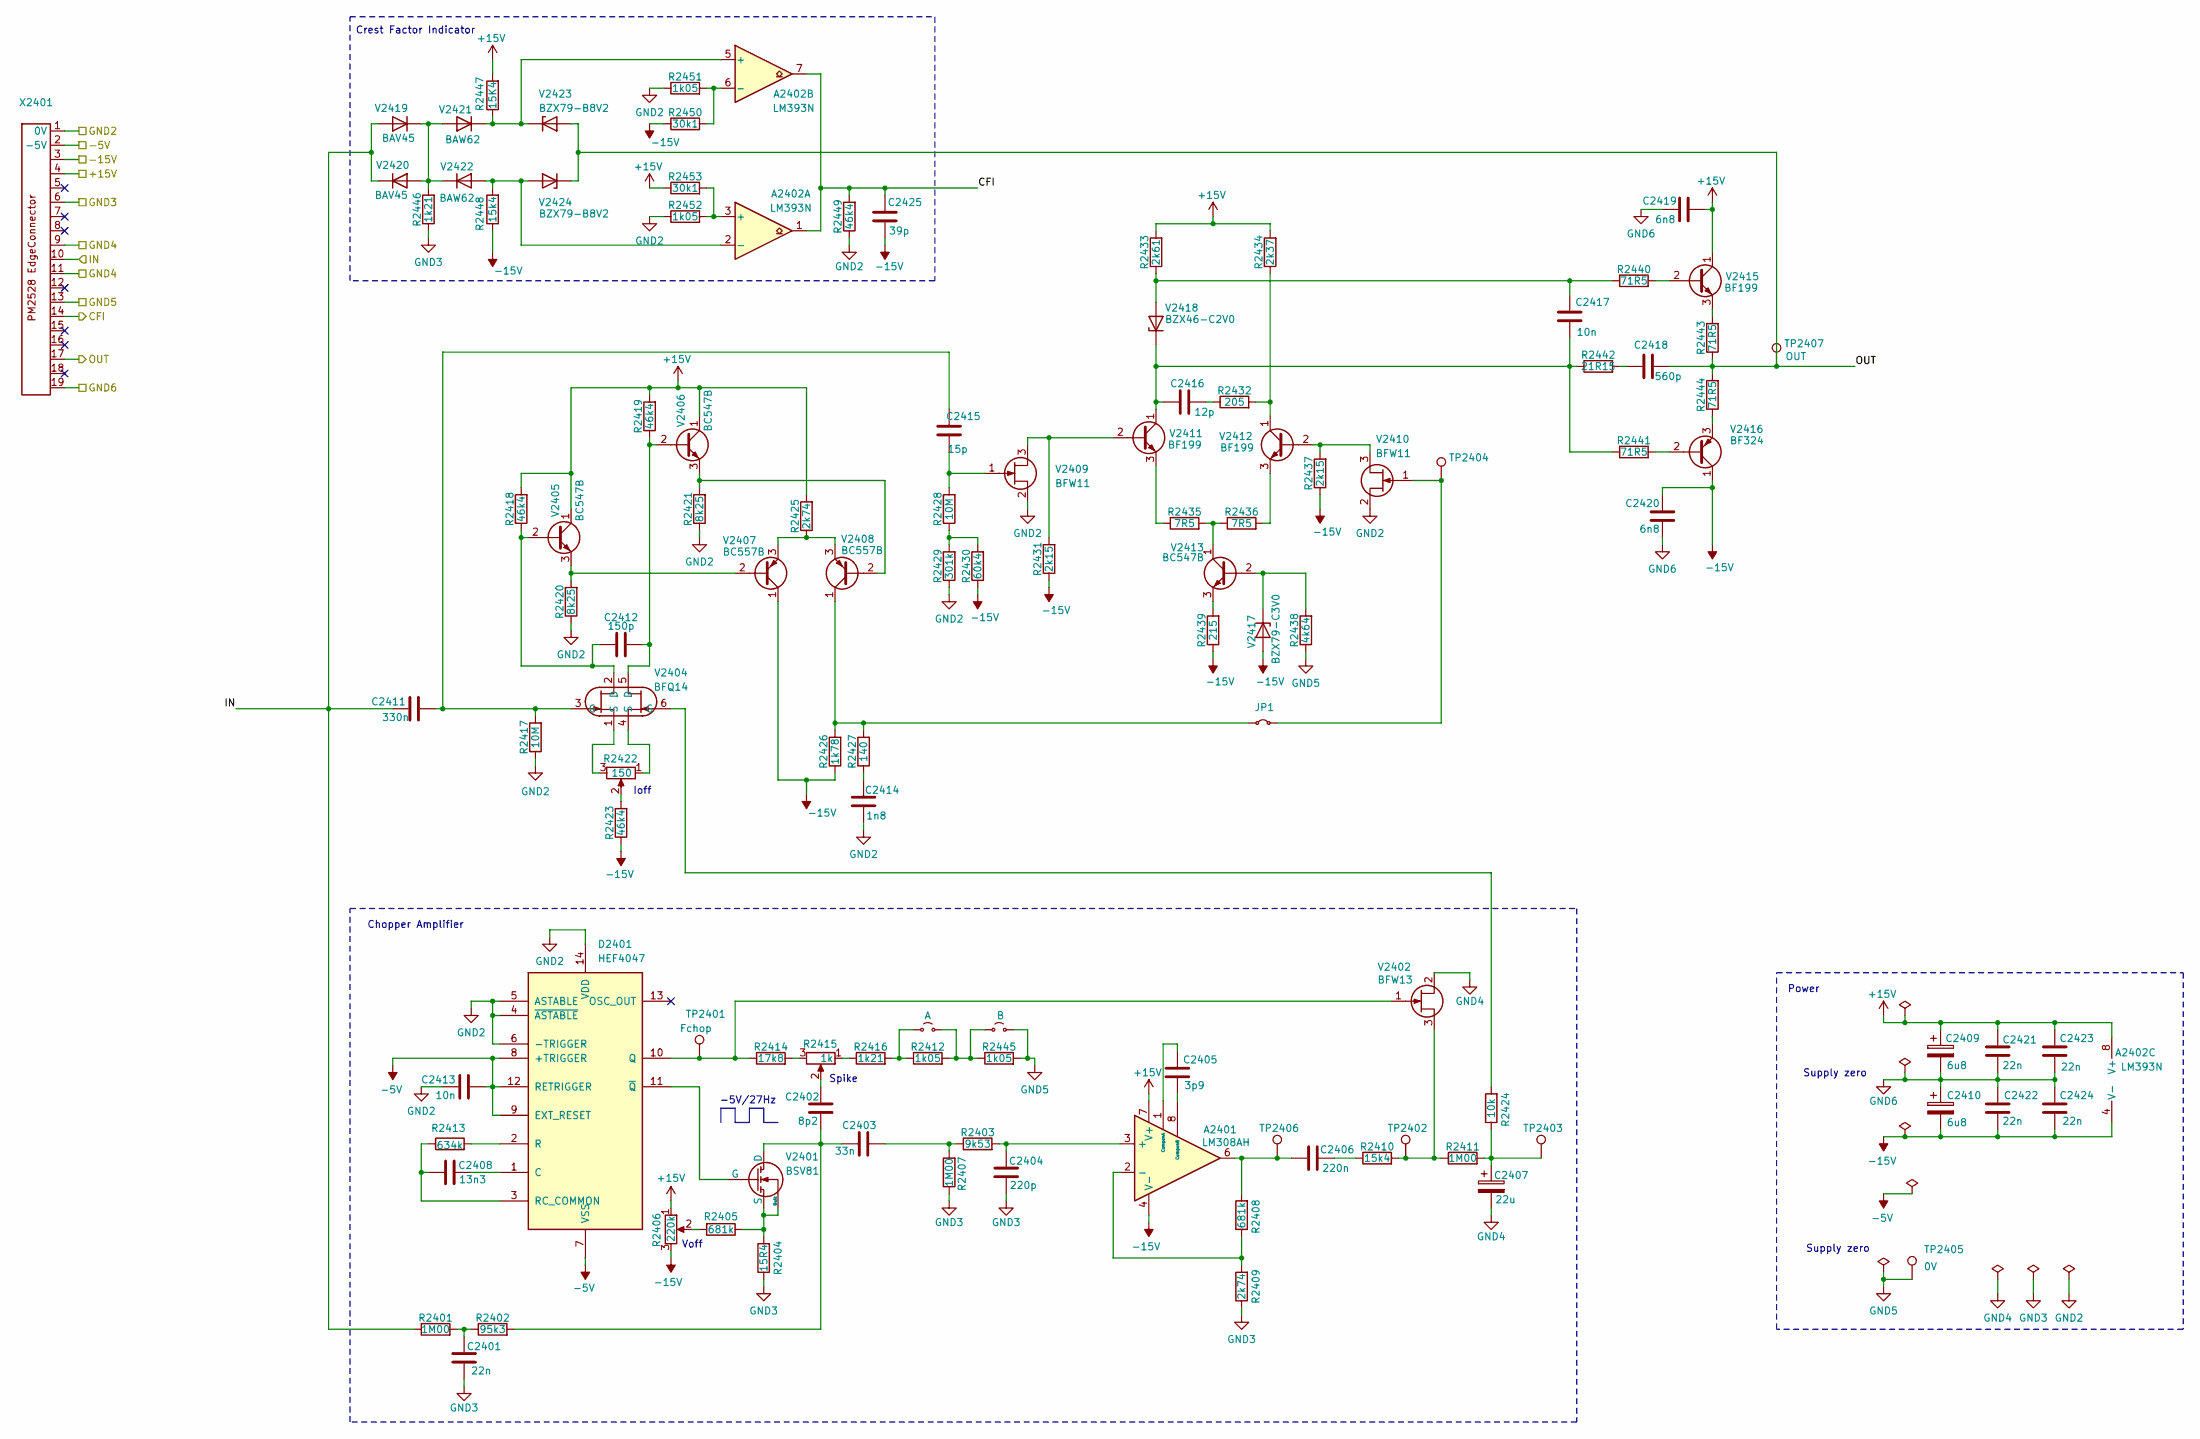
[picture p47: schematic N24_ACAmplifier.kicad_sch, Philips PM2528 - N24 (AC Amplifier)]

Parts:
A2401: LM308AH; DIP-8_W7.62mm
A2402: LM393N; DIP-8_W7.62mm
C2401: 22n; C_Rect_L13.0mm_W4.0mm_P10.00mm_FKS3_FKP3_MKS4
C2402: 8p2; C_Disc_D4.3mm_W1.9mm_P5.00mm
C2403: 33n; C_Rect_L13.0mm_W4.0mm_P10.00mm_FKS3_FKP3_MKS4
C2404: 220p; C_Disc_D4.3mm_W1.9mm_P5.00mm
C2405: 3p9; C_Disc_D4.3mm_W1.9mm_P5.00mm
C2406: 220n; C_Rect_L13.0mm_W4.0mm_P10.00mm_FKS3_FKP3_MKS4
C2407: 22u; CP_Radial_Tantal_D4.5mm_P5.00mm
C2408: 13n3; C_Axial_L5.1mm_D3.1mm_P15.00mm_Horizontal
C2409, C2410: 6u8; CP_Radial_Tantal_D4.5mm_P5.00mm
C2411: 330n; C_Rect_L18.0mm_W5.0mm_P15.00mm_FKS3_FKP3
C2412: 150p; C_Disc_D4.3mm_W1.9mm_P5.00mm
C2413, C2417: 10n; C_Disc_D4.3mm_W1.9mm_P5.00mm
C2414: 1n8; C_Disc_D4.3mm_W1.9mm_P5.00mm
C2415: 15p; C_Disc_D4.3mm_W1.9mm_P5.00mm
C2416: 12p; C_Disc_D4.3mm_W1.9mm_P5.00mm
C2418: 560p; C_Disc_D4.3mm_W1.9mm_P5.00mm
C2419, C2420: 6n8; C_Disc_D4.3mm_W1.9mm_P5.00mm
C2421, C2422, C2423, C2424: 22n; C_Disc_D4.3mm_W1.9mm_P5.00mm
C2425: 39p; C_Disc_D4.3mm_W1.9mm_P5.00mm
D2401: HEF4047; DIP-14_W7.62mm
JP1: Jumper_2_Small_Bridged; TestPoint_Bridge_Pitch5.08mm_Drill0.7mm
JP2401: A; TestPoint_Bridge_Pitch5.08mm_Drill0.7mm
JP2402: B; TestPoint_Bridge_Pitch5.08mm_Drill0.7mm
R2401, R2407, R2411: 1M00; R_Axial_DIN0207_L6.3mm_D2.5mm_P10.16mm_Horizontal
R2402: 95k3; R_Axial_DIN0207_L6.3mm_D2.5mm_P10.16mm_Horizontal
R2403: 9k53; R_Axial_DIN0207_L6.3mm_D2.5mm_P10.16mm_Horizontal
R2404: 15R4; R_Axial_DIN0207_L6.3mm_D2.5mm_P10.16mm_Horizontal
R2405, R2408: 681k; R_Axial_DIN0207_L6.3mm_D2.5mm_P10.16mm_Horizontal
R2406: 220k; Trimmer vertical
R2409, R2425: 2k74; R_Axial_DIN0207_L6.3mm_D2.5mm_P10.16mm_Horizontal
R2410, R2448: 15k4; R_Axial_DIN0207_L6.3mm_D2.5mm_P10.16mm_Horizontal
R2412, R2445, R2451, R2452: 1k05; R_Axial_DIN0207_L6.3mm_D2.5mm_P10.16mm_Horizontal
R2413: 634k; R_Axial_DIN0207_L6.3mm_D2.5mm_P10.16mm_Horizontal
R2414: 17k8; R_Axial_DIN0207_L6.3mm_D2.5mm_P10.16mm_Horizontal
R2415: 1k; Trimmer vertical
R2416, R2446: 1k21; R_Axial_DIN0207_L6.3mm_D2.5mm_P10.16mm_Horizontal
R2417, R2428: 10M; R_Axial_DIN0207_L6.3mm_D2.5mm_P10.16mm_Horizontal
R2418, R2419, R2423, R2449: 46k4; R_Axial_DIN0207_L6.3mm_D2.5mm_P10.16mm_Horizontal
R2420, R2421: 8k25; R_Axial_DIN0207_L6.3mm_D2.5mm_P10.16mm_Horizontal
R2422: 150; Trimmer vertical
R2424: 10k; R_Axial_DIN0207_L6.3mm_D2.5mm_P10.16mm_Horizontal
R2426: 1k78; R_Axial_DIN0207_L6.3mm_D2.5mm_P10.16mm_Horizontal
R2427: 140; R_Axial_DIN0207_L6.3mm_D2.5mm_P10.16mm_Horizontal
R2429: 301k; R_Axial_DIN0207_L6.3mm_D2.5mm_P10.16mm_Horizontal
R2430: 60k4; R_Axial_DIN0207_L6.3mm_D2.5mm_P10.16mm_Horizontal
R2431, R2437: 2k15; R_Axial_DIN0207_L6.3mm_D2.5mm_P10.16mm_Horizontal
R2432: 205; R_Axial_DIN0207_L6.3mm_D2.5mm_P10.16mm_Horizontal
R2433: 2k61; R_Axial_DIN0207_L6.3mm_D2.5mm_P10.16mm_Horizontal
R2434: 2k37; R_Axial_DIN0207_L6.3mm_D2.5mm_P10.16mm_Horizontal
R2435, R2436: 7R5; R_Axial_DIN0207_L6.3mm_D2.5mm_P10.16mm_Horizontal
R2438: 4k64; R_Axial_DIN0207_L6.3mm_D2.5mm_P10.16mm_Horizontal
R2439: 215; R_Axial_DIN0207_L6.3mm_D2.5mm_P10.16mm_Horizontal
R2440, R2441, R2443, R2444: 71R5; R_Axial_DIN0207_L6.3mm_D2.5mm_P10.16mm_Horizontal
R2442: 21R15; R_Axial_DIN0207_L6.3mm_D2.5mm_P10.16mm_Horizontal
R2447: 15K4; R_Axial_DIN0207_L6.3mm_D2.5mm_P10.16mm_Horizontal
R2450, R2453: 30k1; R_Axial_DIN0207_L6.3mm_D2.5mm_P10.16mm_Horizontal
TP2401: Fchop; Pin_D0.9mm_L10.0mm_W2.4mm_FlatFork
TP2402, TP2403: Pin_D0.9mm_L10.0mm_W2.4mm_FlatFork
TP2404: something; Pin_D0.9mm_L10.0mm_W2.4mm_FlatFork
TP2405: 0V; Pin_D0.9mm_L10.0mm_W2.4mm_FlatFork
TP2406: AC_RMS?; Pin_D0.9mm_L10.0mm_W2.4mm_FlatFork
TP2407: OUT; Pin_D0.9mm_L10.0mm_W2.4mm_FlatFork
V2401: BSV81; TO-72-4
V2402: BFW13; TO-72-4
V2404: BFQ14; TO-75-6
V2405, V2406, V2413: BC547B; TO-92_Inline
V2407, V2408: BC557B; TO-92_Inline
V2409, V2410: BFW11; TO-72-4
V2411, V2412, V2415: BF199; TO-92_Inline
V2416: BF324; TO-92_Inline
V2417: BZX79-C3V0; D_DO-35_SOD27_P10.16mm_Horizontal
V2418: BZX46-C2V0; D_DO-35_SOD27_P10.16mm_Horizontal
V2419, V2420: BAV45; TO-72-4
V2421, V2422: BAW62; D_DO-35_SOD27_P10.16mm_Horizontal
V2423, V2424: BZX79-B8V2; D_DO-35_SOD27_P10.16mm_Horizontal
X2401: PM2528_RiserCardConnector

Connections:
+15V: A2401.7 (V+), A2402.8 (V+), C2409.1, C2419.2, C2421.1, C2423.1, R2406.1, R2418.2, R2419.2, R2425.2, R2433.2, R2434.2, R2447.2, R2453.1, V2405.1 (C), V2406.1 (C), V2415.1 (C), X2401.4
-5V: C2413.1, D2401.7 (VSS), D2401.8 (+TRIGGER), D2401.9 (EXT_RESET), D2401.12 (RETRIGGER), X2401.2 (-5V)
-15V: A2401.4 (V-), A2402.4 (V-), C2410.2, C2420.1, C2422.2, C2424.2, C2425.1, R2406.3, R2423.1, R2426.1, R2430.1, R2431.1, R2437.1, R2439.1, R2448.1, R2450.1, V2407.1 (C), V2416.1 (C), V2417.2 (A), X2401.3
/CFI: A2402.1, A2402.7, C2425.2, R2449.2, X2401.14
/IN: C2411.2, R2401.1, V2419.2 (A), V2420.1 (K), X2401.10
/OUT: C2418.1, R2443.1, R2444.2, TP2407.1, V2423.2 (A), V2424.1 (K), X2401.17
GND2: C2413.2, C2414.1, D2401.4 (~ASTABLE), D2401.5 (ASTABLE), D2401.6 (-TRIGGER), D2401.14 (VDD), R2417.1, R2420.1, R2421.1, R2429.1, R2449.1, R2451.1, R2452.1, V2409.2 (S), V2410.2 (S), X2401.1 (0V)
GND3: C2401.2, C2404.2, R2404.1, R2407.1, R2409.1, R2446.1, X2401.6
GND4: C2407.2, V2402.2 (S), X2401.9, X2401.11
GND5: JP2402.2 (B), R2438.1, R2445.2, TP2405.1, X2401.13
GND6: C2409.2, C2410.1, C2419.1, C2420.2, C2421.2, C2422.1, C2423.2, C2424.1, X2401.19
unnamed: A2401.3 (+), C2404.1, R2403.2
unnamed: A2401.2 (-), R2408.1, R2409.2
unnamed: A2401.1 (CompenA), C2405.1
unnamed: A2401.8 (CompenB), C2405.2
unnamed: A2401.6, C2406.1, R2408.2, TP2406.1
unnamed: A2402.3 (+), R2452.2, R2453.2
unnamed: A2402.2 (-), R2448.2, V2422.2 (A), V2424.2 (A)
unnamed: A2402.5 (+), R2447.1, V2421.1 (K), V2423.1 (K)
unnamed: A2402.6 (-), R2450.2, R2451.2
unnamed: C2401.1, R2401.2, R2402.1
unnamed: C2402.1, R2415.2
unnamed: C2403.2, R2403.1, R2407.2
unnamed: C2406.2, R2410.1
unnamed: C2407.1, R2411.2, R2424.1, TP2403.1
unnamed: C2411.1, C2415.1, R2417.2, V2404.3 (G)
unnamed: C2414.2, R2427.1
unnamed: C2416.1, R2432.1
unnamed: C2418.2, R2442.2
unnamed: C2408.1, D2401.1 (C)
unnamed: D2401.10 (Q), R2414.1, TP2401.1, V2402.1 (G)
unnamed: D2401.2 (R), R2413.2
unnamed: C2408.2, D2401.3 (RC_COMMON), R2413.1
unnamed: D2401.11 (~Q), V2401.2 (G)
unnamed: JP1.1 (A), R2426.2, R2427.2, V2408.1 (C)
unnamed: JP1.2 (B), TP2404.1, V2410.1 (G)
unnamed: JP2401.1 (A), R2412.1, R2416.2
unnamed: JP2401.2 (B), JP2402.1 (A), R2412.2, R2445.1
unnamed: R2405.2, R2406.2
unnamed: R2414.2, R2415.3
unnamed: R2415.1, R2416.1
unnamed: R2422.1, V2404.4 (S)
unnamed: R2422.2, R2423.2
unnamed: R2422.3, V2404.1 (S)
unnamed: R2424.2, V2404.6 (G)
unnamed: R2428.1, R2429.2, R2430.2
unnamed: R2404.2, R2405.1, V2401.3 (S), V2401.4 (Bulk)
unnamed: C2402.2, C2403.1, R2402.2, V2401.1 (D)
unnamed: R2410.2, R2411.1, TP2402.1, V2402.3 (D)
unnamed: C2412.2, R2418.1, V2404.2 (D), V2405.2 (B)
unnamed: R2420.2, V2405.3 (E), V2407.2 (B)
unnamed: C2412.1, R2419.1, V2404.5 (D), V2406.2 (B)
unnamed: R2421.2, V2406.3 (E), V2408.2 (B)
unnamed: R2425.1, V2407.3 (E), V2408.3 (E)
unnamed: R2431.2, V2409.3 (D), V2411.2 (B)
unnamed: C2415.2, R2428.2, V2409.1 (G)
unnamed: R2437.2, V2410.3 (D), V2412.2 (B)
unnamed: C2416.2, C2417.1, R2441.1, R2442.1, V2411.1 (C), V2418.1 (K)
unnamed: R2435.1, V2411.3 (E)
unnamed: R2432.2, R2434.1, V2412.1 (C)
unnamed: R2436.2, V2412.3 (E)
unnamed: R2438.2, V2413.2 (B), V2417.1 (K)
unnamed: R2435.2, R2436.1, V2413.1 (C)
unnamed: R2439.2, V2413.3 (E)
unnamed: R2440.2, V2415.2 (B)
unnamed: R2443.2, V2415.3 (E)
unnamed: R2441.2, V2416.2 (B)
unnamed: R2444.1, V2416.3 (E)
unnamed: C2417.2, R2433.1, R2440.1, V2418.2 (A)
unnamed: R2446.2, V2419.1 (K), V2420.2 (A), V2421.2 (A), V2422.1 (K)

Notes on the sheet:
Power
-5V/27Hz
Voff
Supply zero
Ioff
Spike
Chopper Amplifier
Crest Factor Indicator

Board: 2 copper layers, 114 parts (0 on the bottom side), 70 nets, no tracks yet.

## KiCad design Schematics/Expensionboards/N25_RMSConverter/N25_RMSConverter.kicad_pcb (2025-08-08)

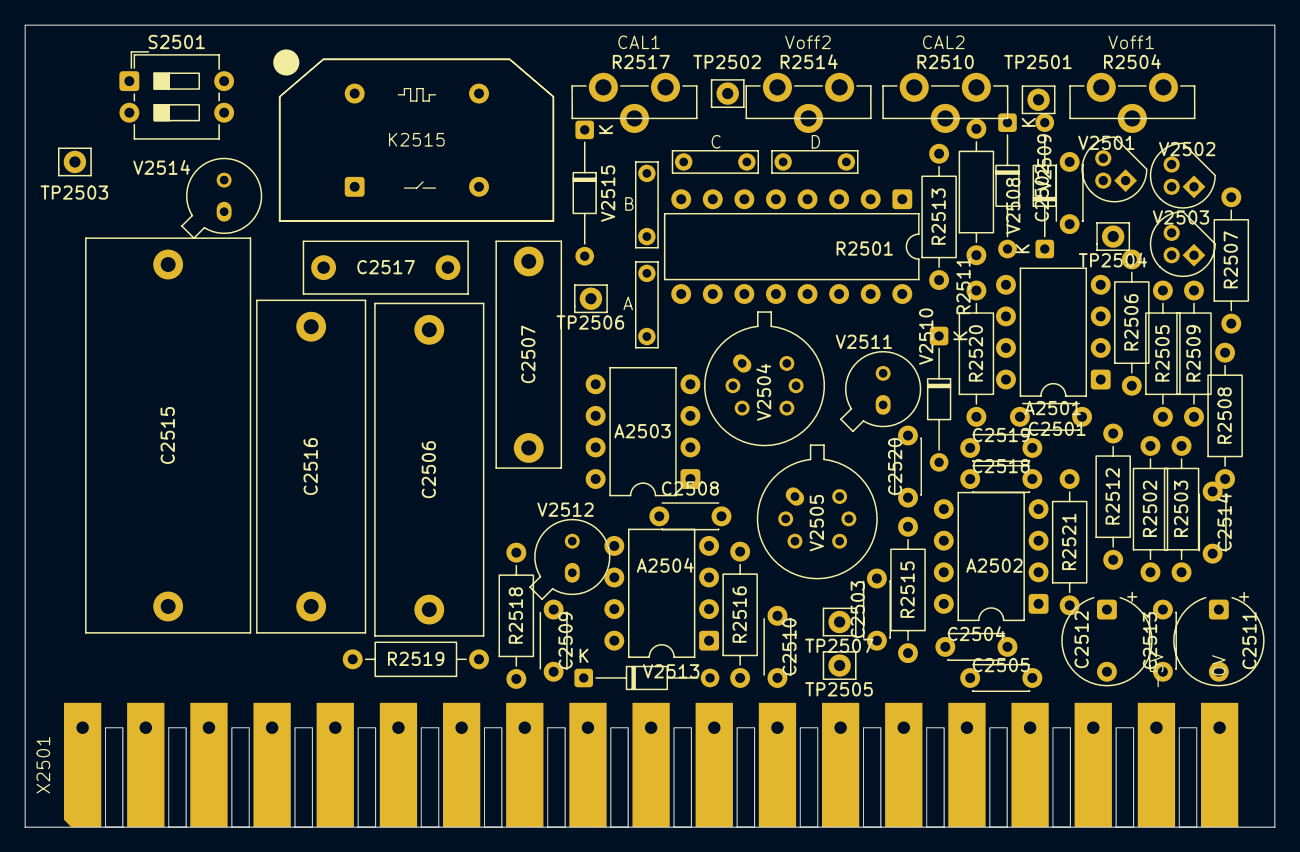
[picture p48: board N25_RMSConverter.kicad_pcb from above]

Board: 2 copper layers, 100.5 x 64.5 mm, 72 parts (0 on the bottom side), 51 nets, no tracks yet.

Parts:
A2501, A2503, A2504: LM308AN; DIP-8_W7.62mm
A2502: LF356BN; DIP-8_W7.62mm
C2501: 22p; C_Disc_D4.3mm_W1.9mm_P5.00mm
C2502, C2510: 470p; C_Disc_D4.3mm_W1.9mm_P5.00mm
C2503, C2509: 100p; C_Disc_D4.3mm_W1.9mm_P5.00mm
C2504, C2505, C2518: 10n; C_Disc_D4.3mm_W1.9mm_P5.00mm
C2506: 3u3; C_Rect_L26.5mm_W8.5mm_P22.50mm_MKS4
C2507: 330n; C_Rect_L18.0mm_W5.0mm_P15.00mm_FKS3_FKP3
C2508: 10p; C_Disc_D4.3mm_W1.9mm_P5.00mm
C2511, C2512: 6u8; CP_Radial_Tantal_D7.0mm_P5.00mm
C2513, C2514: 22n; C_Disc_D4.3mm_W1.9mm_P5.00mm
C2515: 6u8; C_Rect_L31.5mm_W13.0mm_P27.50mm_MKS4
C2516: 2u2; C_Rect_L26.5mm_W8.5mm_P22.50mm_MKS4
C2517: 100n; C_Rect_L13.0mm_W4.0mm_P10.00mm_FKS3_FKP3_MKS4
C2519: 2n2; C_Disc_D4.3mm_W1.9mm_P5.00mm
C2520: 18p; C_Disc_D4.3mm_W1.9mm_P5.00mm
JP2501: A; TestPoint_Bridge_Pitch5.08mm_Drill0.7mm
JP2502: B; TestPoint_Bridge_Pitch5.08mm_Drill0.7mm
JP2503: C; TestPoint_Bridge_Pitch5.08mm_Drill0.7mm
JP2504: D; TestPoint_Bridge_Pitch5.08mm_Drill0.7mm
K2515: Reed relay assy
R2501: OM529; DIP-16_W7.62mm
R2502: 19R6; R_Axial_DIN0207_L6.3mm_D2.5mm_P10.16mm_Horizontal
R2503, R2513: 301k; R_Axial_DIN0207_L6.3mm_D2.5mm_P10.16mm_Horizontal
R2504, R2514: 47k; Trimmer vertical
R2505: 750; R_Axial_DIN0207_L6.3mm_D2.5mm_P10.16mm_Horizontal
R2506: 590; R_Axial_DIN0207_L6.3mm_D2.5mm_P10.16mm_Horizontal
R2507: 301; R_Axial_DIN0207_L6.3mm_D2.5mm_P10.16mm_Horizontal
R2508: 7k87; R_Axial_DIN0207_L6.3mm_D2.5mm_P10.16mm_Horizontal
R2509: 1k96; R_Axial_DIN0207_L6.3mm_D2.5mm_P10.16mm_Horizontal
R2510: 1K; Trimmer vertical
R2511: 8R25; R_Axial_DIN0207_L6.3mm_D2.5mm_P10.16mm_Horizontal
R2512: 115; R_Axial_DIN0207_L6.3mm_D2.5mm_P10.16mm_Horizontal
R2515, R2518: 2k05; R_Axial_DIN0207_L6.3mm_D2.5mm_P10.16mm_Horizontal
R2516: 4k02; R_Axial_DIN0207_L6.3mm_D2.5mm_P10.16mm_Horizontal
R2517: 330; Trimmer vertical
R2519: 3k01; R_Axial_DIN0207_L6.3mm_D2.5mm_P10.16mm_Horizontal
R2520: 5M6; R_Axial_DIN0207_L6.3mm_D2.5mm_P10.16mm_Horizontal
R2521: 33M; R_Axial_DIN0207_L6.3mm_D2.5mm_P10.16mm_Horizontal
S2501: SW_DPST_x2; SW_DIP_SPSTx02_Slide_6.7x6.64mm_W7.62mm_P2.54mm_LowProfile
TP2501, TP2502, TP2504, TP2507: Pin_D0.9mm_L10.0mm_W2.4mm_FlatFork
TP2503: OUT; Pin_D0.9mm_L10.0mm_W2.4mm_FlatFork
TP2505: IN; Pin_D0.9mm_L10.0mm_W2.4mm_FlatFork
TP2506: 0V; Pin_D0.9mm_L10.0mm_W2.4mm_FlatFork
V2501, V2502: BC547B; TO-92
V2503: BC559B; TO-92
V2504, V2505: MAT01GH; TO-78-6
V2508, V2509, V2513: BAW62; D_DO-34_SOD68_P10.16mm_Horizontal
V2510: BZX79-B4V7; D_DO-34_SOD68_P10.16mm_Horizontal
V2511, V2512, V2514: BAV45; TO-18-2
V2515: BAX12A; D_DO-34_SOD68_P10.16mm_Horizontal
X2501: PM2528_RiserCardConnector

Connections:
+5V: R2518.2, X2501.5
+15V: A2501.7 (V+), A2502.7 (V+), A2503.7 (V+), A2504.7 (V+), C2504.1, C2511.1, C2513.1, R2504.1, R2505.2, R2506.2, R2514.1, X2501.4
-15V: A2501.4 (V-), A2502.4 (V-), A2503.4 (V-), A2504.4 (V-), C2505.2, C2512.2, C2514.2, R2504.3, R2507.1, R2509.1, R2514.3, V2510.2 (A), X2501.3
/D1703.22: K2515.10, V2515.2 (A), X2501.15
/IN: C2518.2, R2501.16, R2521.1, TP2505.1, X2501.7
/OUT: C2516.2, C2517.2, R2501.10, TP2503.1, V2514.2 (A), X2501.13
GND3: C2504.2, C2505.1, C2511.2, C2512.1, C2513.2, C2514.1, R2508.1, R2519.1, TP2506.1, X2501.1 (0V)
GND4: A2503.3 (+), A2504.3 (+), R2502.1, R2512.1, V2504.2 (B), V2504.5 (B), X2501.8, X2501.12
GND5: C2509.2, C2517.1, K2515.5, S2501.3 (A), X2501.11
GND6: K2515.6, V2515.1 (K), X2501.14
unnamed: A2501.3 (+), R2502.2, R2503.2
unnamed: A2501.2 (-), C2502.2, R2510.2, TP2501.1
unnamed: A2501.1 (CompenA), C2501.2
unnamed: A2501.8 (CompenB), C2501.1
unnamed: A2502.3 (+), R2512.2, R2513.2
unnamed: A2502.2 (-), C2519.2, C2520.1, R2501.15, V2504.1 (C), V2511.1 (K)
unnamed: A2503.2 (-), C2506.1, C2507.1, R2501.13, V2505.6 (C)
unnamed: A2503.1 (CompenA), C2508.2
unnamed: A2503.8 (CompenB), C2508.1
unnamed: A2504.2 (-), C2510.2, R2517.1, R2517.2, V2504.6 (C), V2512.1 (K)
unnamed: A2504.8 (CompenB), C2509.1
unnamed: C2515.2, R2501.11
unnamed: C2518.1, R2520.2
unnamed: C2519.1, R2521.2
unnamed: JP2501.1 (A), R2501.8, R2517.3
unnamed: JP2502.1 (A), R2501.7
unnamed: JP2503.1 (A), R2501.6
unnamed: JP2504.1 (A), R2501.5
unnamed: K2515.1, R2501.9
unnamed: R2501.1, R2510.3, R2511.1, R2520.1
unnamed: R2501.3, R2510.1, R2511.2
unnamed: R2503.1, R2504.2
unnamed: R2513.1, R2514.2
unnamed: C2506.2, S2501.1 (A)
unnamed: A2503.6, C2507.2, R2501.12, S2501.2 (B), TP2502.1
unnamed: C2515.1, C2516.1, S2501.4 (B)
unnamed: A2501.6, V2501.2 (B), V2510.1 (K)
unnamed: R2505.1, V2501.1 (C), V2503.2 (B)
unnamed: R2507.2, V2501.3 (E), V2502.3 (E)
unnamed: C2502.1, R2508.2, R2509.2, V2502.2 (B)
unnamed: V2502.1 (C), V2503.1 (C), V2508.2 (A), V2509.1 (K)
unnamed: R2506.1, V2503.3 (E)
unnamed: V2504.3 (E), V2505.1 (C), V2505.2 (B)
unnamed: V2504.4 (E), V2505.5 (B), V2513.2 (A)
unnamed: C2503.2, R2515.2, TP2507.1, V2505.3 (E), V2505.4 (E)
unnamed: R2501.14, TP2504.1, V2508.1 (K)
unnamed: R2501.2, V2509.2 (A)
unnamed: A2502.6, C2503.1, C2520.2, R2515.1, V2511.2 (A)
unnamed: A2504.6, C2510.1, R2516.2, V2512.2 (A)
unnamed: R2516.1, V2513.1 (K)
unnamed: R2518.1, R2519.2, V2514.1 (K)

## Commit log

2024-08-15 First version
    [PM2528Riser.kicad_pcb, PM2528Riser.kicad_sch]
2024-08-29 Version 2
    [PM2528Riser.kicad_pcb, PM2528Riser.kicad_sch]
2024-08-29 Remove backups
    [342-080-558-201 - EDAC Card Edge Connector.STEP, PM2528Riser.kicad_pcb, PM2528Riser.kicad_sch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]
2024-08-29 Added new files for N21
    [342-080-558-201 - EDAC Card Edge Connector.STEP, ModulePins.xlsx, N20_ADCControl.kicad_pcb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]
2024-10-04 Replaced testpins with testloops/beads
    [N20_ADCControl.kicad_pcb, N20_ADCControl.kicad_sch, N21_ADCAnalog.kicad_pcb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]
2024-11-01 Added N22/N23
    [Info.xlsx, ModulePins.xlsx, N20_ADCControl.kicad_pcb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]
2025-04-08 Updates, add N25
    [N20_ADCControl.kicad_pcb, N20_ADCControl.kicad_sch, N21_ADCAnalog.kicad_pcb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]
2025-04-27 Updated info, updated N22
    [Info.xlsx, N22_DCAmplifier.kicad_pcb, N22_DCAmplifier.kicad_sch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]
2025-05-25 Started with N24
    [Info.xlsx, N22_DCAmplifier.kicad_pcb, N22_DCAmplifier.kicad_sch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]
2025-05-29 Small updates, N25 also
    [N21_ADCAnalog.kicad_pcb, N21_ADCAnalog.kicad_sch, N22_DCAmplifier.kicad_pcb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]
2025-05-30 N25 RMS Ok!
    [Info.xlsx, N25_RMSConverter.kicad_pcb, N25_RMSConverter.kicad_sch]
2025-05-30 Updated relais-xreference
    [Info.xlsx, N22_DCAmplifier.kicad_sch]
2025-07-06 Update schematics, move projectlibraries to D:
    [N20_ADCControl.kicad_pcb, N20_ADCControl.kicad_sch, N21_ADCAnalog.kicad_pcb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]
2025-07-24 Restructure folders, added EPROM-dumps
    [Info.xlsx, N21_ADCAnalog.kicad_sch, N23_CurrentSource.kicad_pcb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]
2025-07-28 Restructure folders, added EPROMs and Ghidra-project
    [342-080-558-201 - EDAC Card Edge Connector.STEP, Info.xlsx, N20_ADCControl.kicad_pcb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]
2025-08-05 Lotsofchanges. Included Ghidra-project and correct firmware-images
    [Info.xlsx, N20_ADCControl.kicad_pcb, N20_ADCControl.kicad_sch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]
2025-08-08 Reworked N20/N21
    [3306W.stp, 3319W.stp, 3386V001XXX.stp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]
2025-08-10 Small modifications, more disassembly
    [Info.xlsx, N20_ADCControl.kicad_pcb, N22_DCAmplifier.kicad_pcb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]
2025-08-10 Reorganize Ghidra folderstructure Add some comments in assembly
2025-08-15 Updated N24 schema/PCB
    [N24_ACAmplifier.kicad_pcb, N24_ACAmplifier.kicad_sch]
2025-08-17 Updated some component-values
    [N21_ADCAnalog.kicad_sch, N24_ACAmplifier.kicad_pcb, N24_ACAmplifier.kicad_sch]
2025-08-17 Added N30 schema/PCB Small additions to disassembly
    [Info.xlsx, N30_GalvanicSeperation.kicad_pcb, N30_GalvanicSeperation.kicad_sch]
2025-08-23 Updated disassembly some more Moved PM2528 footprints/3D to subfolder
    [3306W.stp, 3319W.stp, 3386V001XXX.stp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]
2025-08-31 More disassembly More info in Info-Excel-sheet
    [Info.xlsx]
2025-09-10 Some more disassembly
    [Info.xlsx]
2025-09-12 Some more disassembly, optimize N20 schematics (naming of signals)
    [Info.xlsx, N20_ADCControl.kicad_pcb, N20_ADCControl.kicad_sch]
2025-09-21 Small updates Some GPIB-analyzing-functions found.
    [Info.xlsx, N20_ADCControl.kicad_pcb, N20_ADCControl.kicad_sch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]
2025-10-10 Lotsofassembly-comments Added extra MCS48-info Updated Excelsheet
    [PM2528 Technical details.xlsx]
2025-10-17 Added LA-traces, some assembly-comments
    [N20_ADCControl.kicad_sch, N21_ADCAnalog.kicad_sch, PM2528 Technical details.xlsx]
2025-11-02 Added ADC controlflow (Archimate)
2025-11-02 Deepdive ADC (wip)
2025-11-15 Added ADC-deepdive txts
2025-11-19 Added N20 deepdive
    [N20_ADCControl.kicad_sch]
2025-11-29 Small textual changes
    [N21_ADCAnalog.kicad_sch]
2025-11-30 Included schematics
    [N20_ADCControl.kicad_sch, N21_ADCAnalog.kicad_sch]
2025-12-03 Added PCB
    [N20_ADCControl.kicad_pcb, N21_ADCAnalog.kicad_pcb]
2025-12-03 Rename ADC Core to ADC Analog
2025-12-03 Included PCBs, Risercard and 3D-views
    [N20_ADCControl.kicad_pcb, N20_ADCControl.kicad_sch, N21_ADCAnalog.kicad_pcb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]
2025-12-03 PCBs in color
2025-12-16 Schematic-analyses N20
    [N20_ADCControl.kicad_sch]
2025-12-21 More N20
    [N20_ADCControl.kicad_sch]
2026-01-16 More N20, update Ghidra-project to most recent Ghidra version
    [N20_ADCControl.kicad_sch]
2026-11-07 Correct N21-N30 schematics against service manual and parts list
    - N21: values and supply of D2101 updated, V2101 ON528, A2105 LM208AH
    - N22: R2213 2R05, Q no longer joined to C2210, C2205 680n, LF355H, BZX87
    - N23: Vref pins swapped (+2VRef on pin 8), R2325 PTC, test point labels
    - N24: A2401 LM308AN, R2442 2R15, test point labels
    - N25: K2515 renamed K2501, TP2506 on GND5
    - N26: V2607 OA95, R2615 4k64 (parts list)
    - N30: C3008 22n
    - Footprint library renamed to PhilipsPM2528
    - Deepdive N20/N21 text updates
    - .gitignore: exclude .claude/ and reveng/
2026-11-09 Updated some component values, updates to most recent KiCad
2026-11-09 Add N27 peak detector schematic (work in progress)
    The schematic is not complete yet.
2026-11-12 Add device-info to Ghidra-project
2026-11-13 Updated schematics for local ground
2026-11-13 Create KiCad mastersheet which incorporates all parts
